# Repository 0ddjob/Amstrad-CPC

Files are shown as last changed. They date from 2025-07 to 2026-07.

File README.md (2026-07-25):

# Amstrad CPC
Amstrad CPC related projects.

## [Typer-Inner-Checker](/Typer-Inner-Checker)
A simple HTML/web page to aid typing in Locomotive BASIC program listings on a modern computer.  It doesn't run the program, that's for a proper emulator.<br>

This HTML page will:
- Check each line as you type it in
- Colourise/capitalise keywords
- Highlights missing GOTO/GOSUB targets
- Save/load BAS file for resuming where you left off

## [CPC PLUS Floppy Adaptor](/CPC_Plus_Floppy_Adaptor)
An idea to convert the 6128 PLUS model's Centronics floppy connector to a more standard 26-way or 34-way pin header to connect a drive via a ribbon cable.<br>

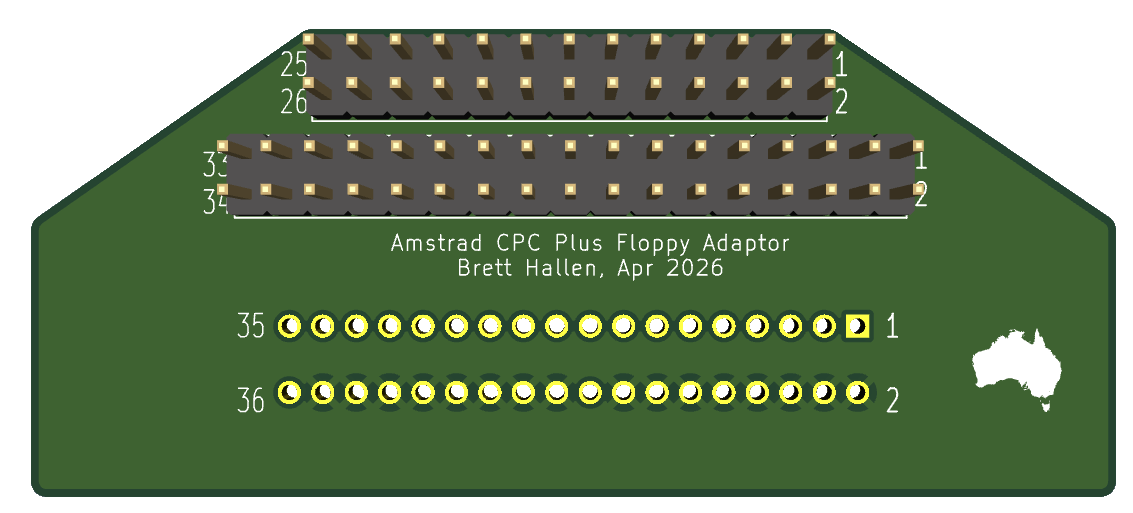
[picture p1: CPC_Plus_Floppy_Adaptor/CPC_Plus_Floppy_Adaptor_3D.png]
CPC PLUS Floppy Adaptor


### Status
21-May-2026: test boards being fabricated

## [Dual ROM Adaptor for CPC464](/CPC464_Dual_ROM)
An idea for a no-cut adaptor board to allow two 32KB ROM images to be installed/switchable on a 64KB EPROM.  This means you could have the original 464 firmware/BASIC 1.0 and 664 (or 6128) firmware/BASIC 1.1 easily switchable.  Alternatively you could install a diagnostic ROM in one of the 32KB banks.<br>

Of course you would need to de-solder the original ROM and install this, but you wouldn't need to worry about cutting the PCB and wiring up pin 1, and you can just reinstall the original ROM.<br>

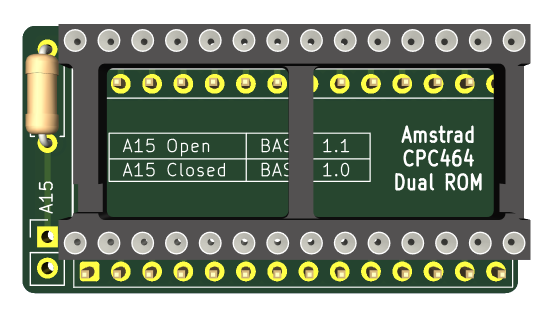
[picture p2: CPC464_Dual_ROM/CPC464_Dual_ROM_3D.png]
Dual ROM 3D


### Status
21-May-2026: test boards being fabricated

## [Amstrad CPC Troubleshooting Keyboard](/Amstrad_CPC_Keyboard)
Started off as a quick'n'dirty keyboard for my 2nd CPC664 motherboard that's missing the top case/keyboard, then morphed to a generic CPC keyboard that could be used for troubleshooting naked motherboards.<br>

### Status
25-Jul-2025: work in progress<br>

## [Easy Add on Projects for Amstrad CPC](/Easy-Add-on-Projects-for-Amstrad-CPC)
Trying out hardware projects from the book.

## [VGA4CPC](/VGA4CPC_Brett)
A modification of [grzegorz_gr's original design](https://github.com/grzegorz-gr/vga4cpc) to use with [WacKEDmaN's enhanced firmware](https://github.com/WacKEDmaN/VGA4CPC-Enhanced).<br>

- Rev. A: original re-design of grzegorz-gr's original, adding 6-pin & 8-pin DIN input sockets plus 3.5mm audio pass-through & 2.1mm DC power input
- Rev. B: added buffer on VGA output as suggest by [WacKEDmaN](https://github.com/WacKEDmaN/VGA4CPC-Enhanced#optional-hardware-mods), pass-through for B&W LUM signal, extra push button & breakout of spare GPIOs
- Rev. C: removed CPC PLUS 8-pin DIN to reduce board size (<100x100mm) for cheaper fabrication, adjusted resistor values
- Rev. D: added the CPC PLUS 8-pin DIN back in plus 3.5mm stereo audio output, remaining under 100x100mm
- Rev. E: swapped TLV3212 (SOIC-8) comparator for TLV3232 (SSOP-8) as it's faster
- Rev. F: moved the [comparator to its own daughterboard](/Amstrad-CPC/VGA4CPC_Brett/Comparator_Board) (simplifies circuit routing), switched to 5V logic (Pico 2 required), also switching the 74LVC245 (SMD) to 74HCT245 (THT)

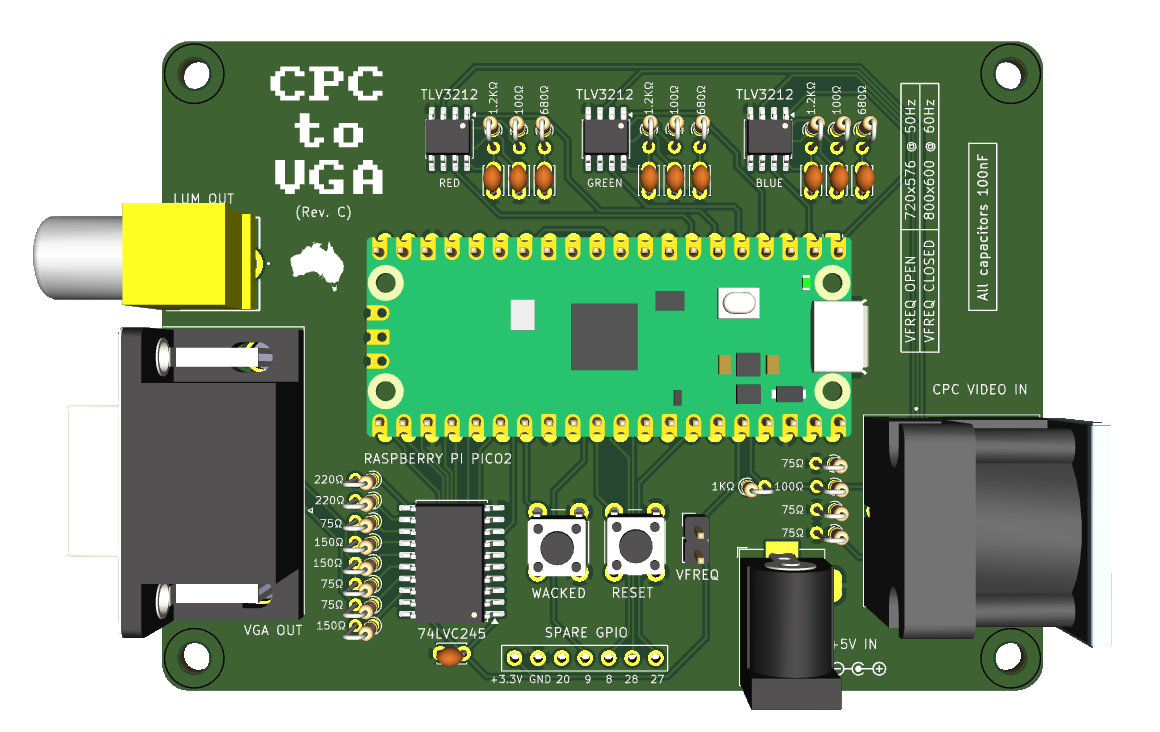
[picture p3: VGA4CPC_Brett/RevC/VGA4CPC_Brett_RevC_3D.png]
Brett's CPC-only board 3D


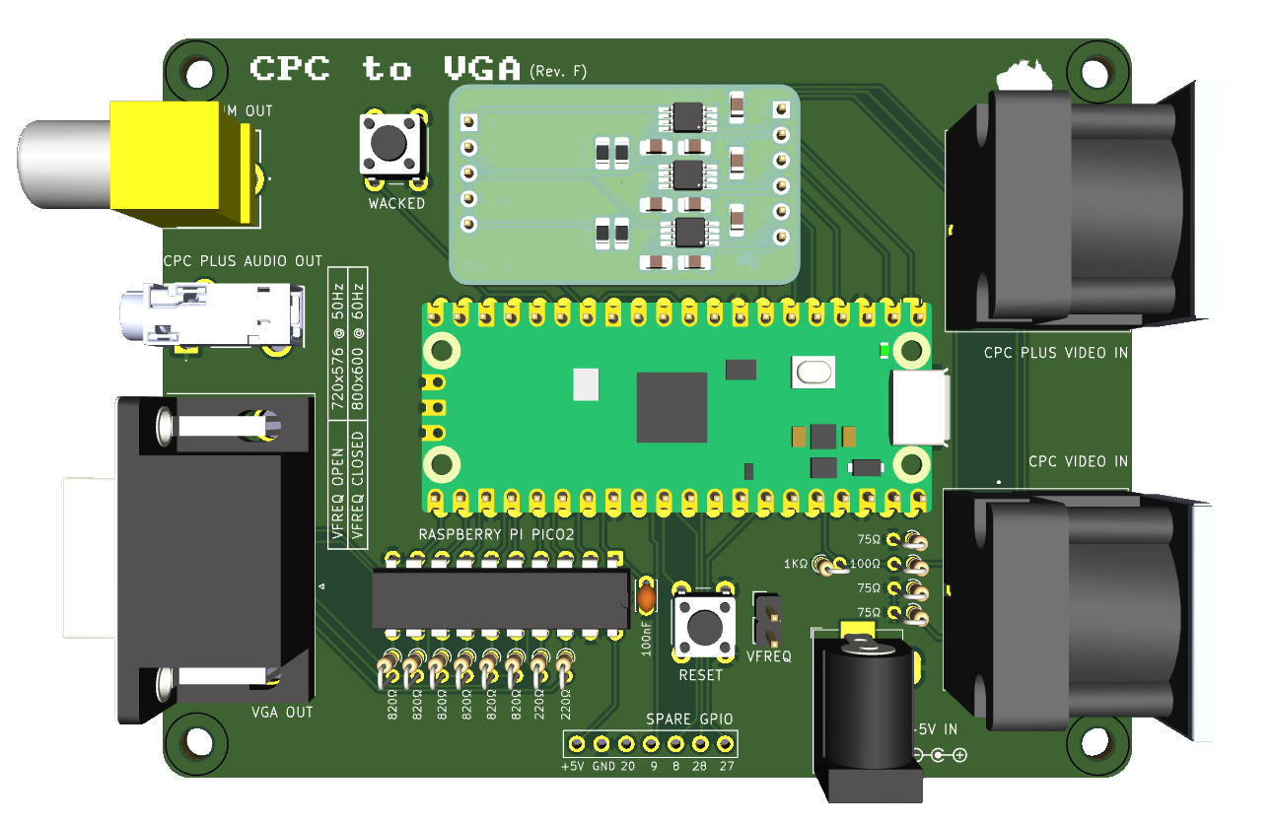
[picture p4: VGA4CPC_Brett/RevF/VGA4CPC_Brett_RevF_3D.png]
Brett's CPC-to-VGA board 3D


### Status
22-May-2025: Rev. C pending fab & testing

## [CPC DIN to VGA](/CPC_DIN-to-VGA)
This is just a very simple connector converter - convert the CPC/CPC PLUS DIN to VGA, with also an RCA for the B&W LUM signal and 3.5mm stereo socket for the PLUSs' audio output.<br>

The idea is that you can then more easily plug it into a device with a VGA socket (like GBS8200) for actual signal conversion.<br>

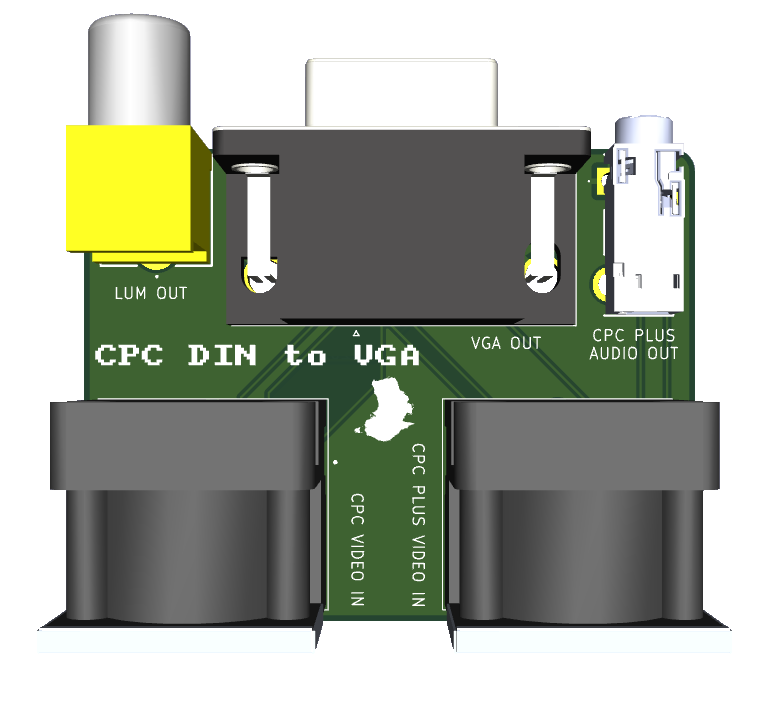
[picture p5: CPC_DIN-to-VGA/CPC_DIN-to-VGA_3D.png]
CPC DIN to VGA converter 3D


## [Laserwarp](/Laserwarp)
Laserwarp was the first game, with Map Rally, that we got with our green screen Amstrad CPC464 so I have fond memories.<br>

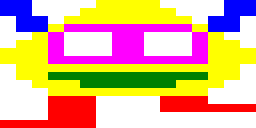
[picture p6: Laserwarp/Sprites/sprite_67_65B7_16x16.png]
Laserwarp sprite


I thought it might be interesting to try out Claude to disassemble and delve into how the game works.<br>

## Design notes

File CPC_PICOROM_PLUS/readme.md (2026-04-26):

# CPC+ ROM Emulator using Raspberry Pi Pico
Based on [Matt Callow's](https://github.com/mattcallow/CPC_PICOROM) original design for the CPC.

## Current Status: UNTESTED!
- 18-Nov-2024: initial design done
- 20-Nov-2024: test PCBs on their way from PCBWAY
- 3-Dec-2024: Initial testing ... not working!  (not really a surprise)
- 12-Dec-2024: Centronics pin numbering all wrong, duh!  External ROMs on Plus machines are all logical, upper ROMs only.

Plus Expansion Connector

## Instructions
Please refer to Matt's page for firmware & instructions on how to initialise the Pico & transfer/use Amstrad CPC ROMs.<br>
ROMs can be found [here](https://www.cpcwiki.eu/index.php/ROM_List).

## Parts
- Raspberry Pi Pico
- 50-way male Centronics connector (NorComp 111-050-113L001?)
- 2 x 6mm tactile switch (for reset)
- 5 x 1N4148 diodes

## Design
Designed using Kicad.<br>
Files, including Gerbers for production, can be found [here.](/Hardware/)<br>
Centronics connector [Kicad symbol.](/CPC_PICOROM_PLUS/Hardware/Centronics_Connector/)  I also made a custom version with signal names on the pins (see schematic image below).<br>
Raspberry Pi Pico [Kicad symbol.](https://github.com/ncarandini/KiCad-RP-Pico)<br>
Tactile switches [Kicad symbol.](https://github.com/skiselev/my_kicad_library)<br>

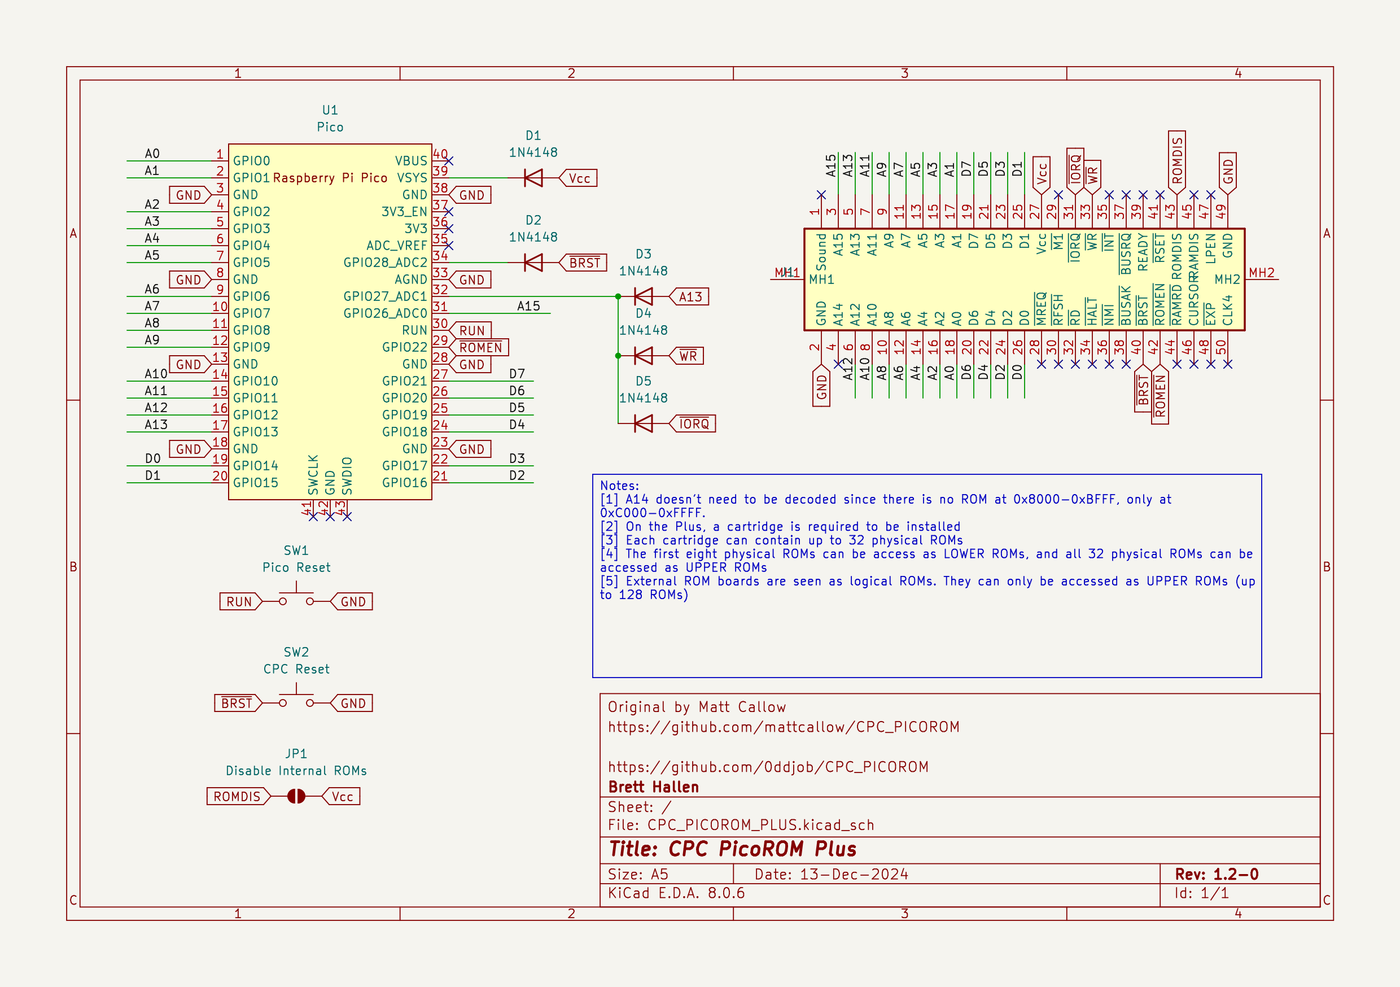
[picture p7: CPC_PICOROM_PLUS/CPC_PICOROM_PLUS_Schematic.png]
Schematic


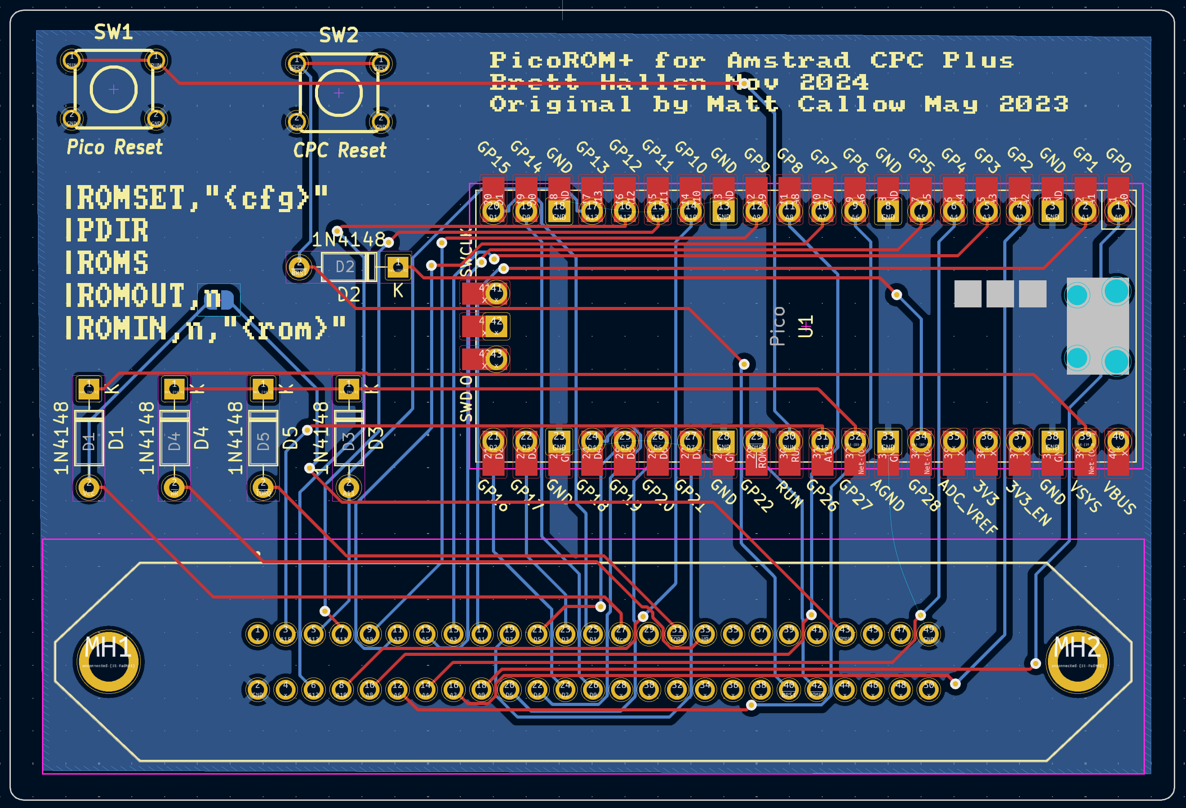
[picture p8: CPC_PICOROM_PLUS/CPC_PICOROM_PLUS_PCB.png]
PCB layout


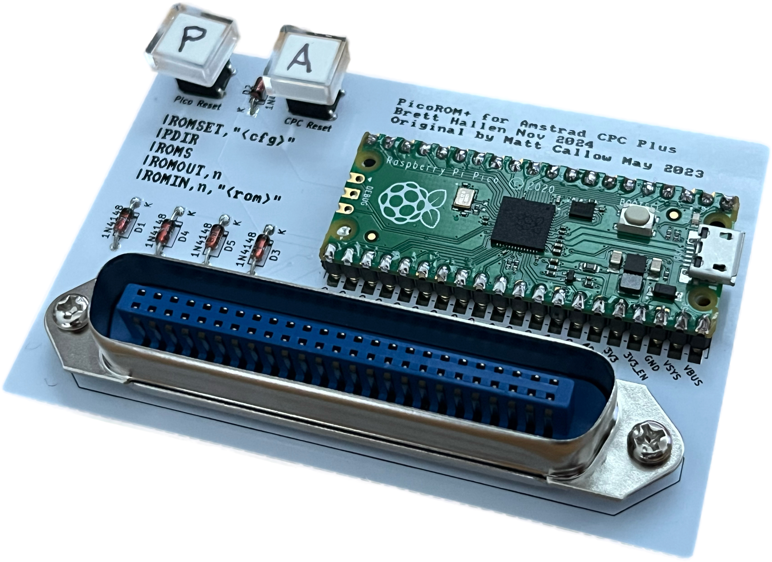
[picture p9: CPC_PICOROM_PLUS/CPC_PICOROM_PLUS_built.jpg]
Build PCB


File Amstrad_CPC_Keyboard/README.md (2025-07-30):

# Amstrad CPC Troubleshooting Keyboard
Started off as a quick'n'dirty keyboard for my 2nd CPC664 motherboard that's missing the top case/keyboard, then morphed to a generic CPC keyboard that could be used for troubleshooting naked motherboards.<br>

The CPC6128/Plus keyboard is a simple rectangle so I based this keyboard on that design, but using CPC464 colouring (that I grew up with).  The initial CPC464/664 keyboard design was abandoned/not completed in favour of the CPC6128 design.<br>

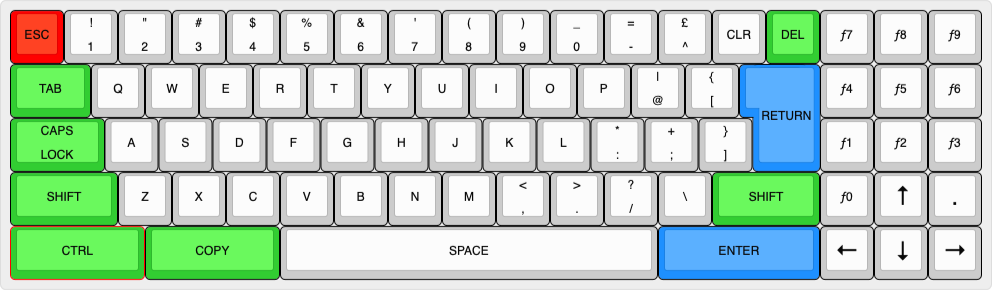
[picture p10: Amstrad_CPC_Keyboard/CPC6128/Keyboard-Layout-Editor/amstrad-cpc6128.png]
Proposed troubleshooting keyboard layout


And now I've decided to just concentrate on a simple tactile switch version, nice and compact, suitable for troubleshooting purposes.<br>

As there are different connectors used on the CPC464, CPC664 and CPC6128/Plus computers I decided to use just one connector on the keyboard itself and handle the motherboard connection by using different cable sets (to be designed).<br>

## Links (for Cherry version)
- [Keyboard layout design](https://www.keyboard-layout-editor.com)
- [Switch layout template](http://builder.swillkb.com)

## Proposed BOM (for Cherry version)
- 74 x Cherry MX-type key switches in total
- 63 x 1u
- 1 x ISO ENTER
- 1 x 1.5u (TAB)
- 1 x 1.75u (CAPS LOCK)
- 2 x 2.5u (COPY & CTRL)
- 1 x 3u (number pad ENTER)
- 1 x 7u (SPACE)
- 1 x SPST power switch
- 1 x LED & resistor
- 2 x 10-pin header (for keyboard)
- 1 x 2-pin header (for power)

## Status
25-Jul-2025: work in progress<br>

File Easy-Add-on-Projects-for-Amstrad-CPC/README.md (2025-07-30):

# Easy Add-on Projects for Amstrad CPC & MSX Computers
Hardware projects from the [book](https://archive.org/details/easy-add-on-projects-for-amstrad-cpc-464-664-6128-and-msx-computers-owen-bishopacme) by Owen Bishop.<br>

## [Project 2: Picture Digitiser](/Project02/)
Status:<br>
15-Apr-2025: Initial PCB design completed<br>

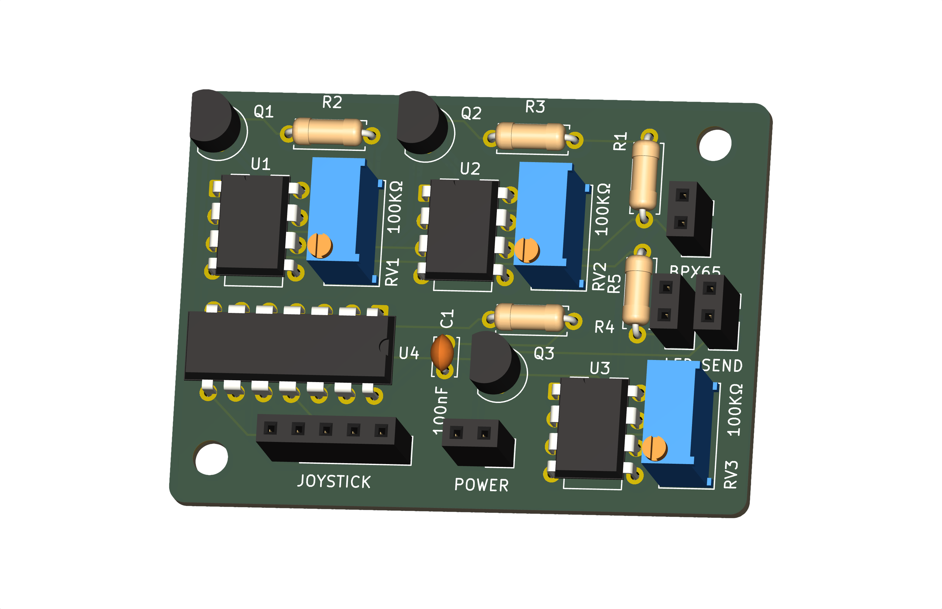
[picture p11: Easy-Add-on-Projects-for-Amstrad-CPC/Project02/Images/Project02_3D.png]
3D view of PCB


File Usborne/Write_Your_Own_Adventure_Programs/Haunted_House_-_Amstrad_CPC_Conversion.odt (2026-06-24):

Haunted House

An Amstrad CPC (Locomotive BASIC) conversion by Claude (with minor patches by Brett Hallen, June 2026)

This is a conversion of the Haunted House adventure from Usborne’s Write Your Own Adventure Programs for Your Microcomputer (the listing beginning on page 33). The book gives a generic “Microsoft BASIC” listing with conversion notes for the VIC-20, Oric, BBC, Spectrum and ZX81 — but not the Amstrad CPC. This version runs on a CPC 464, 664 or 6128 under Locomotive BASIC.

Line numbers are kept identical to the book so you can cross-reference the original. Only the lines listed below were changed; everything else is typed exactly as printed.

# Loading and running

Type the listing in directly on a real machine or an emulator (WinAPE, Caprice32, RetroVirtualMachine all work well), then:

RUN

To keep a copy:

SAVE"HAUNTED"

In an emulator you can usually paste the .bas text straight into the BASIC editor, or convert it to a .DSK disk image with a tool such as iDSK / CPCDiskXP and then LOAD it.

# Changes made for the Amstrad CPC

Line(s) | In the book | Amstrad CPC version | Reason
50 | REM SELECT "TEXT MODE" IF NECESSARY | MODE 1:INK 0,0:INK 1,24:BORDER 0:PEN 1:PAPER 0 | The CPC needs an explicit screen mode. MODE 1 gives a 40-column screen, wide enough for every message. The INK/BORDER/PAPER/PEN settings give bright text on a black background for atmosphere and are optional.
65 | CLEAR 100 | (line removed) | Marked “only needed on TRS-80.” Locomotive BASIC’s CLEAR takes no string-space argument, so this line would cause a syntax error. String space is handled automatically.
90 | CLS | CLS (unchanged) | The CPC already has CLS, so the VIC-20 substitution (PRINT CHR$(147)) is not needed.
420 | ...RND(3)<>3... | ...INT(RND*3+1)<>3... | On the CPC, RND(x) for any positive x returns a fraction 0–1, so RND(3) never equals 3. Replaced with the integer form the book itself specifies for other machines (bats attack ~2 times in 3).
430 | ...RND(2)=1... | ...INT(RND*2)=1... | Same RND issue. INT(RND*2) gives 0 or 1, a true 50/50 chance for the ghosts to appear.
1190 | ...RM=RND(63) | ...RM=INT(RND*64) | Same RND issue. INT(RND*64) teleports you to a random room 0–63, as intended.
235 | (new line) | Q$=UPPER$(Q$) | Added so input is folded to upper case before parsing. The verb and object names are stored in capitals, so without this the player would have to use CAPS LOCK. UPPER$ is built into Locomotive BASIC on all CPC models.

One small display tidy-up (not CPC-specific): line 150 originally printed a comma after every exit, leaving a trailing one — “EXITS: N,W,E,”. It now prints the comma only between exits, so the list reads “EXITS: N,W,E”.

# Things that did NOT need changing

These are worth knowing, because the book’s notes for other machines can be misleading on the CPC:

Arrays start at zero. The listing fills R$(0)…R$(63) and D$(0)…D$(63) and depends on element zero existing. Locomotive BASIC arrays are 0-based by default, exactly like the Microsoft BASIC the listing targets, so the Spectrum’s “add 1 to every room index” rewrite is NOT needed here.

LET is optional. The Spectrum requires LET on every assignment; the CPC does not, so assignments are left bare as printed (e.g. V=25).

INPUT prompts. INPUT "...";Q$ works as-is. The book notes a BBC may need a comma instead of the semicolon — the CPC is happy with the semicolon.

Ampersands in DATA. Room names such as “KITCHEN & GRIMY COOKER” and “STUDY WITH DESK & HOLE IN WALL” are left unquoted. When READ into a string variable, Locomotive BASIC takes the characters literally, so they don’t need quoting.

The long ON VB GOSUB at line 460 has 26 targets for 25 verbs — this is intentional, not a typo. An unrecognised verb sets VB to 26, which jumps to the bare RETURN at line 1590 and harmlessly does nothing.

# Playing notes

Type your commands in either case — line 235 folds the input to upper case automatically (UPPER$), so CAPS LOCK is not required. Most commands are two words, e.g. GET ROPE, OPEN DRAWER, LIGHT CANDLE, SAY XZANFAR. HELP lists the words it knows; CARRYING? lists your inventory; SCORE checks progress.

You start at the front gate (room 57) with a candle whose life (LL) is 60 turns; once lit it burns down and warns you before going out. Only N/S/W/E are processed directly — up and down work at the staircases, where lines 720–770 remap them.

# Saving and quitting (pages 30–31)

Pages 30–31 of the book describe optional SAVE, LOAD and QUIT commands. These have been added and adapted to the CPC’s file handling. Each is a single-word command — just type SAVE, LOAD or QUIT. (QUIT first asks whether you want to save, then ends the program.)

Three wiring changes connect the new commands, exactly as the book instructs:

• Line 70: V raised from 25 to 28 (three new verbs).

• Line 1665: SAVE, LOAD and QUIT appended to the verb list, becoming verbs 26, 27 and 28.

• Line 460: the subroutine numbers 3000, 4000 and 5000 spliced in just before the final 1590, so SAVE jumps to 3000, LOAD to 4000 and QUIT to 5000.

The new routines themselves (3000–3200 SAVE, 4000–4200 LOAD, 5000–5050 QUIT) needed the book’s generic file commands swapped for real Locomotive BASIC ones:

Line(s) | In the book | Amstrad CPC version | Reason
3020 / 4020 | OPEN FILE FOR OUTPUT / INPUT (placeholder) | OPENOUT"HOUSE" / OPENIN"HOUSE" | The book leaves these as plain-English placeholders to fill in per machine. On the CPC, OPENOUT opens a file to save to, OPENIN opens one to read back.
3030–3080 / 4030–4080 | PRINT #1,... / INPUT #1,... | PRINT #9,... / INPUT #9,... | Locomotive BASIC uses stream #9 for the open cassette/disc file, not #1.
3080 / 4080 | PRINT #1,C(I),F(I) | PRINT #9,C(I):PRINT #9,F(I) | Two values per line confuse INPUT# on the CPC. Writing (and reading) each on its own line makes the save reliable. The book’s footnote flags this same separator problem for the BBC.
3100 / 4100 | CLOSE | CLOSEOUT / CLOSEIN | The CPC closes the output and input files with separate keywords.
5020 | INPUT "...",Q$ | INPUT "...";Q$ | Comma changed to semicolon for the CPC’s INPUT prompt syntax.

Two things worth knowing. On a 464 the game saves to cassette and on a 664/6128 to disc; OPENOUT and OPENIN prompt you to ready the tape automatically, so the “READY TO SAVE/LOAD” questions are just polite extras. And, as the book itself warns, the save records only your room, the object positions, what you are carrying and the game flags — it does NOT save the D$ and R$ arrays. So any room you have permanently changed (opening the secret room, digging out the bars, unlocking the front door) reverts to its original description and exits when you reload. To preserve those too you would add matching loops for D$ and R$ to both routines.

# Full listing

Filename: Haunted House (Amstrad CPC).bas

10 REM HAUNTED HOUSE ADVENTURE

20 REM

30 REM AMSTRAD CPC (LOCOMOTIVE BASIC) VERSION

40 REM ADAPTED FROM USBORNE "WRITE YOUR OWN

45 REM ADVENTURE PROGRAMS", PAGE 33

50 MODE 1:INK 0,0:INK 1,24:BORDER 0:PEN 1:PAPER 0

60 REM

70 V=28:W=36:G=18

80 GOSUB 1600

90 CLS:PRINT"HAUNTED HOUSE"

100 PRINT"------------"

110 PRINT"YOUR LOCATION"

120 PRINT D$(RM)

130 PRINT"EXITS:"

140 FOR I=1 TO LEN(R$(RM))

150 PRINT MID$(R$(RM),I,1);:IF I<LEN(R$(RM)) THEN PRINT",";

160 NEXT I

170 PRINT

180 FOR I=1 TO G

190 IF L(I)=RM AND F(I)=0 THEN PRINT"YOU CAN SEE ";O$(I);" HERE"

200 NEXT I

210 PRINT"=============="

220 PRINT M$:M$="WHAT"

230 INPUT"WHAT WILL YOU DO NOW";Q$

235 Q$=UPPER$(Q$)

240 V$="":W$="":VB=0:OB=0

250 FOR I=1 TO LEN(Q$)

260 IF MID$(Q$,I,1)=" " AND V$="" THEN V$=LEFT$(Q$,I-1)

270 IF MID$(Q$,I,1)=" " AND V$<>"" THEN W$=MID$(Q$,I+1,LEN(Q$)-1):I=LEN(Q$)

280 NEXT I

290 IF W$="" THEN V$=Q$

300 FOR I=1 TO V

310 IF V$=V$(I) THEN VB=I

320 NEXT I

330 FOR I=1 TO W

340 IF W$=O$(I) THEN OB=I

350 NEXT I

360 IF W$<>"" AND OB=0 THEN M$="THAT'S SILLY"

370 IF VB=0 THEN VB=V+1

380 IF W$="" THEN M$="I NEED TWO WORDS"

390 IF VB>V AND OB>0 THEN M$="YOU CAN'T '"+Q$+"'"

400 IF VB>V AND OB=0 THEN M$="YOU DON'T MAKE SENSE"

410 IF VB<V AND OB>0 AND C(OB)=0 THEN M$="YOU DON'T HAVE '"+W$

420 IF F(26)=1 AND RM=13 AND INT(RND*3+1)<>3 AND VB<>21 THEN M$="BATS ATTACKING!":GOTO 90

430 IF RM=44 AND INT(RND*2)=1 AND F(24)<>1 THEN F(27)=1

440 IF F(0)=1 THEN LL=LL-1

450 IF LL<1 THEN F(0)=0

460 ON VB GOSUB 500,570,640,640,640,640,640,640,640,980,980,1030,1070,1140,1180,1220,1250,1300,1340,1380,1400,1430,1460,1490,1510,3000,4000,5000,1590

470 IF LL=10 THEN M$="YOUR CANDLE IS WANING!"

480 IF LL=1 THEN M$="YOUR CANDLE IS OUT!"

490 GOTO 90

500 PRINT"WORDS I KNOW:"

510 FOR I=1 TO V

520 PRINT V$(I);",";

530 NEXT I

540 M$="":PRINT

550 GOSUB 1580

560 RETURN

570 PRINT"YOU ARE CARRYING:"

580 FOR I=1 TO G

590 IF C(I)=1 THEN PRINT O$(I);",";

600 NEXT I

610 M$="":PRINT

620 GOSUB 1580

630 RETURN

640 D=0

650 IF OB=0 THEN D=VB-3

660 IF OB=19 THEN D=1

670 IF OB=20 THEN D=2

680 IF OB=21 THEN D=3

690 IF OB=22 THEN D=4

700 IF OB=23 THEN D=5

710 IF OB=24 THEN D=6

720 IF RM=20 AND D=5 THEN D=1

730 IF RM=20 AND D=6 THEN D=3

740 IF RM=22 AND D=6 THEN D=2

750 IF RM=22 AND D=5 THEN D=3

760 IF RM=36 AND D=6 THEN D=2

770 IF RM=36 AND D=5 THEN D=2

780 IF F(14)=1 THEN M$="CRASH! YOU FELL OUT OF THE TREE!":F(14)=0:RETURN

790 IF F(27)=1 AND RM=52 THEN M$="GHOSTS WILL NOT LET YOU MOVE":RETURN

800 IF RM=45 AND C(1)=1 AND F(34)=0 THEN M$="A MAGICAL BARRIER TO THE WEST":RETURN

810 IF (RM=26 AND F(0)=0) AND (D=1 OR D=4) THEN M$="YOU NEED A LIGHT":RETURN

820 IF RM=54 AND C(15)<>1 THEN M$="YOU'RE STUCK!":RETURN

830 IF C(15)=1 AND NOT (RM=53 OR RM=54 OR RM=55 OR RM=47) THEN M$="YOU CAN'T CARRY A BOAT!":RETURN

840 IF (RM>26 AND RM<30) AND F(0)=0 THEN M$="TOO DARK TO MOVE":RETURN

850 F(35)=0:RL=LEN(R$(RM))

860 FOR I=1 TO RL

870 U$=MID$(R$(RM),I,1)

880 IF (U$="N" AND D=1 AND F(35)=0) THEN RM=RM-8:F(35)=1

890 IF (U$="S" AND D=2 AND F(35)=0) THEN RM=RM+8:F(35)=1

900 IF (U$="W" AND D=3 AND F(35)=0) THEN RM=RM-1:F(35)=1

910 IF (U$="E" AND D=4 AND F(35)=0) THEN RM=RM+1:F(35)=1

920 NEXT I

930 M$="OK"

940 IF F(35)=0 THEN M$="CAN'T GO THAT WAY!"

950 IF D<1 THEN M$="GO WHERE?"

960 IF RM=41 AND F(23)=1 THEN R$(49)="SW":M$="THE DOOR SLAMS SHUT!":F(23)=0

970 RETURN

980 IF OB>G THEN M$="I CAN'T GET "+W$:RETURN

985 IF L(OB)<>RM THEN M$="IT ISN'T HERE"

990 IF F(OB)<>0 THEN M$="WHAT "+W$+"?"

1000 IF C(OB)=1 THEN M$="YOU ALREADY HAVE IT"

1010 IF OB>0 AND L(OB)=RM AND F(OB)=0 THEN C(OB)=1:L(OB)=65:M$="YOU HAVE THE "+W$

1020 RETURN

1030 IF RM=43 AND (OB=28 OR OB=29) THEN F(17)=0:M$="DRAWER OPEN"

1040 IF RM=28 AND OB=25 THEN M$="IT'S LOCKED"

1050 IF RM=38 AND OB=32 THEN M$="THAT'S CREEPY!":F(2)=0

1060 RETURN

1070 IF OB=30 THEN F(18)=0:M$="SOMETHING HERE!"

1080 IF OB=31 THEN M$="THAT'S DISGUSTING!"

1090 IF (OB=28 OR OB=29) THEN M$="THERE IS A DRAWER"

1100 IF OB=33 OR OB=5 THEN GOSUB 1140

1110 IF RM=43 AND OB=35 THEN M$="THERE IS SOMETHING BEYOND.."

1120 IF OB=32 THEN GOSUB 1030

1130 RETURN

1140 IF RM=42 AND OB=33 THEN M$="THEY ARE DEMONIC WORKS"

1150 IF (OB=3 OR OB=36) AND C(3)=1 AND F(34)=0 THEN M$="USE THIS WORD WITH CARE 'XZANFAR'"

1160 IF C(5)=1 AND OB=5 THEN M$="THE SCRIPT IS IN AN ALIEN TONGUE"

1170 RETURN

1180 M$="OK '"+W$+"'"

1190 IF C(3)=1 AND OB=34 THEN M$="*MAGIC OCCURS*":IF RM<>45 THEN RM=INT(RND*64)

1200 IF C(3)=1 AND OB=34 AND RM=45 THEN F(34)=1

1210 RETURN

1220 IF C(12)=1 THEN M$="YOU MADE A HOLE"

1230 IF C(12)=1 AND RM=30 THEN M$="DUG THE BARS OUT":D$(RM)="HOLE IN WALL":R$(RM)="NSE"

1240 RETURN

1250 IF C(14)<>1 AND RM=7 THEN M$="THIS IS NO TIME TO PLAY GAMES"

1260 IF OB=14 AND C(14)=1 THEN M$="YOU SWUNG IT"

1270 IF OB=13 AND C(13)=1 THEN M$="WHOOSH!"

1280 IF OB=13 AND C(13)=1 AND RM=43 THEN R$(RM)="WN":D$(RM)="STUDY WITH SECRET ROOM":M$="YOU BROKE THE THIN WALL"

1290 RETURN

1300 IF OB=14 AND C(14)=1 THEN M$="IT ISN'T ATTACHED TO ANYTHING!"

1310 IF OB=14 AND C(14)<>1 AND RM=7 AND F(14)=0 THEN M$="YOU SEE THICK FOREST AND CLIFF SOUTH":F(14)=1:RETURN

1320 IF OB=14 AND C(14)<>1 AND RM=7 AND F(14)=1 THEN M$="GOING DOWN!":F(14)=0

1330 RETURN

1340 IF OB=17 AND C(17)=1 AND C(8)=0 THEN M$="IT WILL BURN YOUR HANDS"

1350 IF OB=17 AND C(17)=1 AND C(9)=0 THEN M$="NOTHING TO LIGHT IT WITH"

1360 IF OB=17 AND C(17)=1 AND C(9)=1 AND C(8)=1 THEN M$="IT CASTS A FLICKERING LIGHT":F(0)=1

1370 RETURN

1380 IF F(0)=1 THEN F(0)=0:M$="EXTINGUISHED"

1390 RETURN

1400 IF OB=26 AND C(16)=1 THEN M$="HISSSS"

1410 IF OB=26 AND C(16)=1 AND F(26)=1 THEN F(26)=0:M$="PFFT! GOT THEM"

1420 RETURN

1430 IF OB=10 AND C(10)=1 AND C(11)=1 THEN M$="SWITCHED ON":F(24)=1

1440 IF F(27)=1 AND F(24)=1 THEN M$="WHIZZ- VACUUMED THE GHOSTS UP!":F(27)=0

1450 RETURN

1460 IF RM=43 AND (OB=27 OR OB=28) THEN GOSUB 1030

1470 IF RM=28 AND OB=25 AND F(25)=0 AND C(18)=1 THEN F(25)=1:R$(RM)="SEW":D$(RM)="HUGE OPEN DOOR":M$="THE KEY TURNS!"

1480 RETURN

1490 IF C(OB)=1 THEN C(OB)=0:L(OB)=RM:M$="DONE"

1500 RETURN

1510 S=0

1520 FOR I=1 TO G

1530 IF C(I)=1 THEN S=S+1

1540 NEXT I

1550 IF S=17 AND C(15)<>1 AND RM<>57 THEN PRINT"YOU HAVE EVERYTHING":PRINT"RETURN TO THE GATE FOR FINAL SCORE"

1560 IF S=17 AND RM=57 THEN PRINT"DOUBLE SCORE FOR REACHING HERE!":S=S*2

1570 PRINT"YOUR SCORE=";S:IF S>18 THEN PRINT"WELL DONE! YOU FINISHED THE GAME":END

1580 INPUT"PRESS RETURN TO CONTINUE";Q$

1590 RETURN

1600 DIM R$(63),D$(63),O$(W),V$(V)

1610 DIM C(W),L(G),F(W)

1620 DATA 46,38,35,50,13,18,28,42,10,25,26,4,2,7,47,60,43,32

1630 FOR I=1 TO G

1640 READ L(I)

1650 NEXT I

1660 DATA HELP,CARRYING?,GO,N,S,W,E,U,D,GET,TAKE,OPEN,EXAMINE,READ,SAY

1665 DATA DIG,SWING,CLIMB,LIGHT,UNLIGHT,SPRAY,USE,UNLOCK,LEAVE,SCORE,SAVE,LOAD,QUIT

1680 FOR I=1 TO V

1690 READ V$(I)

1700 NEXT I

1710 DATA SE,WE,WE,SWE,WE,WE,SWE,WS

1720 DATA NS,SE,WE,NW,SE,W,NE,NSW

1730 DATA NS,NS,SE,WE,NWUD,SE,WSUD,NS

1740 DATA N,NS,NSE,WE,WE,NSW,NS,NS

1750 DATA S,NSE,NSW,S,NSUD,N,N,NS

1760 DATA NE,NW,NE,W,NSE,WE,W,NS

1770 DATA SE,NSW,E,WE,NS,S,SW,NW

1780 DATA NWE,NWE,WE,WE,WE,NWE,NWE,W

1790 FOR I=0 TO 63

1800 READ R$(I)

1810 NEXT I

1820 DATA DARK CORNER,OVERGROWN GARDEN,BY LARGE WOODPILE,YARD BY RUBBISH

1825 DATA WEEDPATCH,FOREST,THICK FOREST,BLASTED TREE

1840 DATA CORNER OF HOUSE,ENTRANCE TO KITCHEN,KITCHEN & GRIMY COOKER,SCULLERY DOOR

1845 DATA ROOM WITH INCHES OF DUST,REAR TURRET ROOM,CLEARING BY HOUSE,PATH

1860 DATA SIDE OF HOUSE,BACK OF HALLWAY,DARK ALCOVE,SMALL DARK ROOM

1865 DATA BOTTOM OF SPIRAL STAIRCASE,WIDE PASSAGE,SLIPPERY STEPS,CLIFFTOP

1880 DATA NEAR CRUMBLING WALL,GLOOMY PASSAGE,POOL OF LIGHT,IMPRESSIVE VAULTED HALLWAY

1885 DATA HALL BY THICK WOODEN DOOR,TROPHY ROOM,CELLAR WITH BARRED WINDOW,CLIFF PATH

1900 DATA CUPBOARD WITH HANGING COAT,FRONT HALL,SITTING ROOM,SECRET ROOM

1905 DATA STEEP MARBLE STAIRS,DINING ROOM,DEEP CELLAR WITH COFFIN,CLIFF PATH

1920 DATA CLOSET,FRONT LOBBY,LIBRARY OF EVIL BOOKS,STUDY WITH DESK & HOLE IN WALL

1925 DATA WEIRD COBWEBBY ROOM,VERY COLD CHAMBER,SPOOKY ROOM,CLIFF PATH BY MARSH

1940 DATA RUBBLE-STREWN VERANDAH,FRONT PORCH,FRONT TOWER,SLOPING CORRIDOR

1945 DATA UPPER GALLERY,MARSH BY WALL,MARSH,SOGGY PATH

1960 DATA BY TWISTED RAILING,PATH THROUGH IRON GATE,BY RAILINGS,BENEATH FRONT TOWER

1965 DATA DEBRIS FROM CRUMBLING FACADE,LARGE FALLEN BRICKWORK,ROTTING STONE ARCH,CRUMBLING CLIFFTOP

1980 FOR I=0 TO 63

1990 READ D$(I)

2000 NEXT I

2010 DATA PAINTING,RING,MAGIC SPELLS,GOBLET,SCROLL,COINS,STATUE,CANDLESTICK

2012 DATA MATCHES,VACUUM,BATTERIES,SHOVEL,AXE,ROPE,BOAT,AEROSOL,CANDLE,KEY

2014 DATA NORTH,SOUTH,WEST,EAST,UP,DOWN

2016 DATA DOOR,BATS,GHOSTS,DRAWER,DESK,COAT,RUBBISH

2018 DATA COFFIN,BOOKS,XZANFAR,WALL,SPELLS

2060 FOR I=1 TO W

2070 READ O$(I)

2080 NEXT I

2090 F(18)=1:F(17)=1:F(2)=1:F(26)=1:F(28)=1:F(23)=1:LL=60:RM=57:M$="OK"

2100 RETURN

3000 INPUT"READY TO SAVE";Y$

3010 IF Y$<>"Y" THEN 3000

3020 OPENOUT"HOUSE"

3030 PRINT #9,RM

3040 FOR I=1 TO G

3050 PRINT #9,L(I)

3060 NEXT I

3070 FOR I=1 TO W

3080 PRINT #9,C(I):PRINT #9,F(I)

3090 NEXT I

3100 CLOSEOUT

3200 RETURN

4000 INPUT"READY TO LOAD";Y$

4010 IF Y$<>"Y" THEN 4000

4020 OPENIN"HOUSE"

4030 INPUT #9,RM

4040 FOR I=1 TO G

4050 INPUT #9,L(I)

4060 NEXT I

4070 FOR I=1 TO W

4080 INPUT #9,C(I):INPUT #9,F(I)

4090 NEXT I

4100 CLOSEIN

4200 RETURN

5000 INPUT"WANT TO QUIT";Q$

5010 IF Q$<>"Y" THEN RETURN

5020 INPUT"LIKE TO SAVE GAME FIRST";Q$

5030 IF Q$="Y" THEN GOSUB 3000

5040 PRINT"THANKS FOR PLAYING"

5050 END

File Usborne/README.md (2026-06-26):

# Usborne Programs
We got our Amstrad CPC464 with green screen in 1985 and the first book I got was Usborne's "Write Your Own Adventure Programs".<br>

It included a listing of an example adventure game, HAUNTED HOUSE, in Microsoft BASIC with custom conversions for various popular machines ... except for the Amstrad CPC and its Locomotive BASIC ... as the book came out a year before the 464's release.<br>

I never really got the program working (I was very young and stupid) so I finally decided to rectify that by using Claude to generate a CPC version in a DSK file, and then made some minor tweaks of my own (like using UPPER$ function to accept either upper or lower case commands).<br>

Usborne have very graciously made high-quality PDFs available for free download [here](https://usborne.com/au/books/computer-and-coding-books).

## [Write Your Own Adventure Programs](/Usborne/Write_Your_Own_Adventure_Programs)
My first attempt - it seems to work quite well (thanks Claude).<br>

There's two versions:
- HOUSE1.BAS: this is the straight conversion of the original listing
- HOUSE2.BAS: this is my tweaked version that's a little more playable

The tweaks include:
- using UPPER$ function so you don't need to SHOUT commands :)
- removed the extra comma on the EXITS output (i.e. N,S,W instead of N,S,W,)
- added in the save/load/quit subroutines

## [Write Your Own Fantasy Games](/Usborne/Write_Your_Own_Fantasy_Games)
The original game had three separate listings: the dungeon designer, the character creator and then the main game itself.<br>

Still a work in progress - they seem to be working but I will tweak more.<br>

- DUNGEON1.BAS: the straight conversion of the dungeon designer
- DUNGEON2.BAS: my tweaked/improved version
- CREATOR1.BAS: the straight conversion of the character creator
- GAME1.BAS: the straight conversion of the main game

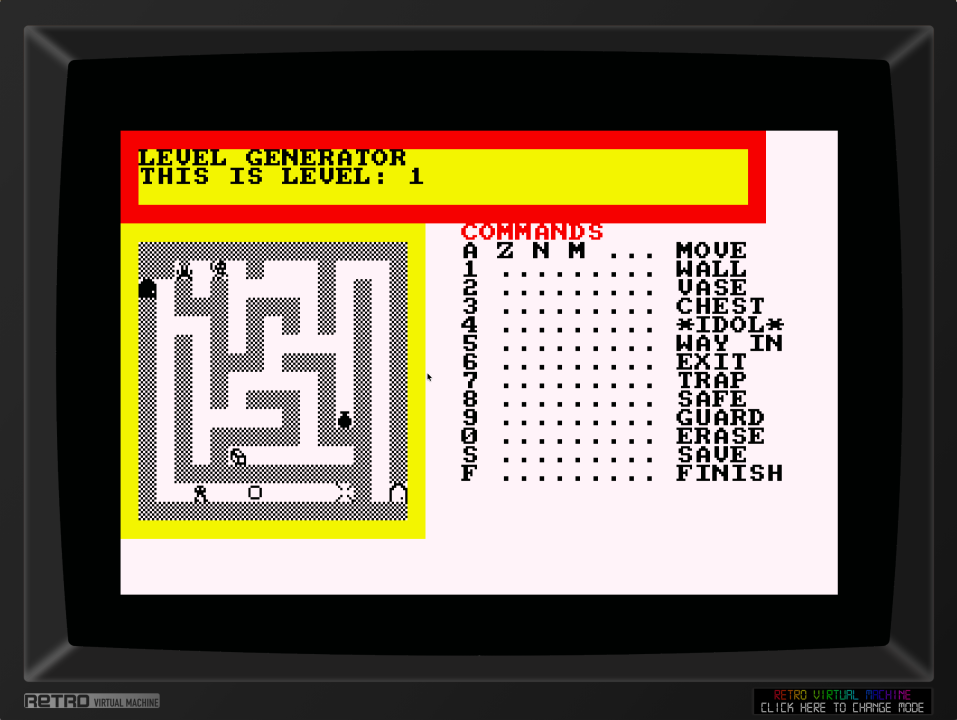
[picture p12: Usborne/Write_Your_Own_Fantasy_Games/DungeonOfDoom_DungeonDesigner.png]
Dungeon of Doom level designer


## [Island of Secrets](/Usborne/Island_Of_Secrets)
Claude got a little cagey when asked to create an Amstrad CPC version - it was worried about copyright.  But it did offer to create a conversion guide which I could use as I type in 450 lines of the program like it was 1985 ...

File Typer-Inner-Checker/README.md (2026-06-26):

# Typer Inner Checker for Locomotive BASIC

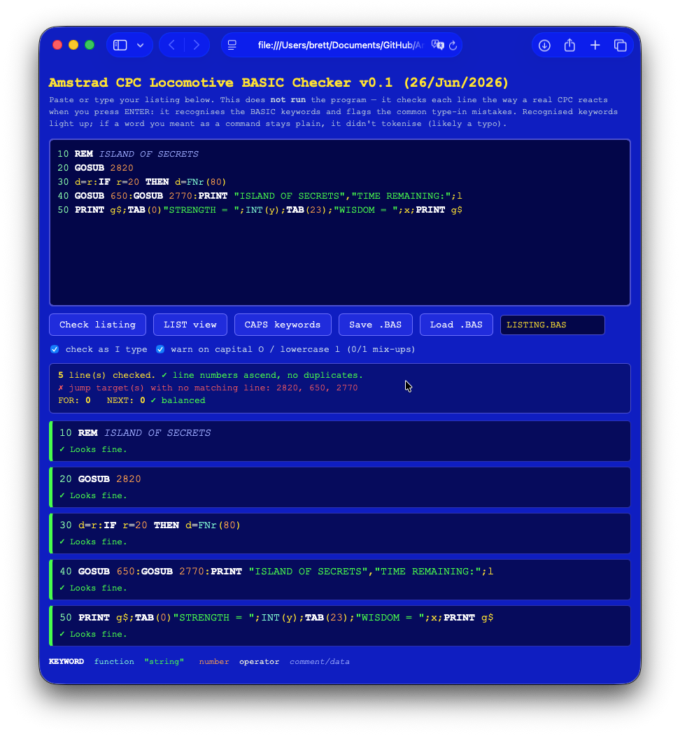
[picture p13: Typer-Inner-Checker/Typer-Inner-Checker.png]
Example


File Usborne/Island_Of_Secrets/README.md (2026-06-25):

# Island of Secrets — Amstrad CPC Conversion Guide

A reference for porting the type-in listing to **Amstrad Locomotive BASIC** (CPC 464/664/6128).
You type the program in from your own copy of the book; apply these rules as you go. The book's
left-margin symbols mark the lines that differ per machine — those are the lines this guide is about.

There is no Amstrad column in the book, so the CPC equivalents below are worked out from how the
generic/Spectrum versions behave.

---

## 1. Global rules (apply everywhere)

| Book construct | CPC (Locomotive BASIC) | Notes |
|---|---|---|
| `LET A=...` | `A=...` (drop `LET`) | Optional on the CPC. Keep `LET` if you'd rather match the book exactly — it's valid either way. |
| `DEF FNR(Z)=INT(RND(1)*Z)+1` | `DEF FNR(Z)=INT(RND*Z)+1` | CPC `RND` already returns 0–<1. (`RND(1)` also works.) Random integer 1…Z. |
| `DEF FNP(Z)=POS` | `DEF FNP(Z)=POS(#0)` | CPC `POS` needs a stream argument. Returns the cursor **column** (1–40). |
| `DEF FNS(Z)=Y-(E/C4+.1)` | unchanged | Uses Y/E/C4 globals; fine as-is. |
| machine-specific clear-screen | `CLS` | Wherever the book's clear routine is called. |
| `PRINT TAB(c)` used for layout | `LOCATE c,r` (or keep `TAB`) | See §2. |

**`O`/`0` and `I`/`1`:** the book warns about these — they bite hardest in the data lines. When in
doubt, capital-letter variables (`L`, `O`, `R`, `Y`) vs digits.

---

## 2. Screen, colour, cursor

- **Mode:** it's a 40-column text adventure → `MODE 1`.
- **Colour:** pick your palette once at start, e.g. a parchment look:
  `MODE 1:INK 0,0:INK 1,26:INK 2,6:INK 3,24:BORDER 0:PAPER 0:PEN 1`
  (black paper, white text; inks 2/3 spare for highlights). Adjust to taste.
- **Status line** (STRENGTH / WISDOM / TIME at the top): the book positions fields with `TAB`/home
  tricks tuned to each machine's width. On the CPC, place each field explicitly:
  `LOCATE 1,1:PRINT"STRENGTH = ";INT(Y);` … `LOCATE 24,1:PRINT"WISDOM = ";X` etc.
  The `G$` "row of dashes" separator string is just text — keep it.
- **Don't rely on TAB(0) wrapping** to start a new line (some machines do this; the CPC's behaviour
  differs). Use `LOCATE` for anything that must land in an exact spot.

---

## 3. Keyboard

- Command line: `INPUT E$` — fine as-is.
- Any single-key tests: wrap with `UPPER$(INKEY$)` so they work without CAPS LOCK.

---

## 4. The one structural change: computed `RESTORE`

The describe-location routine builds a DATA line number and jumps to it:
`D = D*10 + LR : RESTORE D : READ A$` (with `LR` ≈ 2860, so it targets the room-description DATA
block at that line). **Locomotive BASIC's `RESTORE` only accepts a *literal* line number** — `RESTORE D`
is a `Syntax error` on the CPC. This is the only change that needs real restructuring.

**Fix — pre-load the room/action DATA into an array once, then index it.**

At init (after the DIMs), read every room-description DATA block into a string array. If those blocks
run from the first room line `Lfirst` in steps of 10 for `N` rooms:

```
DIM RM$(N)
RESTORE Lfirst              ' literal line number — allowed
FOR I=1 TO N:READ RM$(I):NEXT I
```

Then replace the describe routine's `RESTORE D:READ A$` with a direct index. Because `D=D*10+LR`:

```
A$=RM$((D-LR)/10)
```

For any **other** computed `RESTORE` that uses a *constant* offset (e.g. the one near 4110,
`RESTORE LR+1230`), you don't need an array — just compute the constant yourself and write the
**literal**: `RESTORE 4090` (i.e. 2860+1230). Only the *variable* `RESTORE D` needs the array.

> Tip: keep a scrap of paper mapping `D` values → room line numbers as you type the DATA, so you can
> confirm `(D-LR)/10` lands on the right block.

---

## 5. Word-wrap printer

The book prints a description one character at a time and breaks at a space once the cursor passes a
margin: `IF E$=" " AND FNP(Z)>Z THEN PRINT`. On the CPC:

- `FNP(Z)` → `POS(#0)` (see §1).
- `Z` is your **wrap column**. For MODE 1, set `Z=36` at init (breaks a few columns before the edge).
  `Z` is also passed as the dummy argument to `FNP`/`FNS`, but those ignore it — only line ~730 uses
  `Z` as the threshold, so one value (36) serves both jobs.
- The rest of the print loop is unchanged.

(The CPC also auto-wraps text windows, but the manual break-on-space gives cleaner word breaks — keep it.)

---

## 6. Save / load game (the `"ISDATA"` feature)

The book uses `SAVE "ISDATA" DATA L()` / `LOAD "ISDATA" DATA L()` (and `F()`). The CPC has **no
array save/load** verb, so stream the elements yourself. With `L()` and `F()` dimensioned to 52:

**Save:**
```
OPENOUT"ISDATA"
FOR I=0 TO 52:PRINT #9,L(I):NEXT I
FOR I=0 TO 52:PRINT #9,F(I):NEXT I
CLOSEOUT
```

**Load:**
```
OPENIN"ISDATA"
FOR I=0 TO 52:INPUT #9,L(I):NEXT I
FOR I=0 TO 52:INPUT #9,F(I):NEXT I
CLOSEIN
```

Match the loop bounds to the book's actual `DIM L(...)`/`DIM F(...)`. Numbers round-trip cleanly
through `PRINT #`/`INPUT #`.

---

## 7. The encoded data strings (type, don't convert)

The packed "code" strings (decoded with `ASC(MID$(...))-offset`) and the binary-flag strings are
**machine-independent data** — no CPC change needed. But they must be typed *character-perfect*,
including every `~ % \ ; / *` etc., or the decode produces garbage. Type them slowly and use the
book's own checks: flag strings come in groups of four `0`/`1`s; watch `O` vs `0`. These are the lines
most worth re-reading aloud against the book.

---

## 8. Quick conversion table

| Book | CPC |
|---|---|
| `INT(RND(1)*Z)+1` | `INT(RND*Z)+1` |
| `POS` | `POS(#0)` |
| `RESTORE <variable>` | pre-load DATA → array, index it (§4) |
| `RESTORE <const expr>` | `RESTORE <literal line>` |
| `SAVE/LOAD "x" DATA a()` | `OPENOUT`/`OPENIN` + `PRINT#`/`INPUT#` loop (§6) |
| machine clear-screen | `CLS` |
| `TAB(c)` for absolute layout | `LOCATE c,r` |
| `PEEK(screen)` / `POS` wrap test | `POS(#0)` |
| `LET` | (drop, or keep — your choice) |

---

## 9. Order of work that worked well for the other games

1. Type the **init / DIM / DEF FN** and the **DATA** first (including the encoded strings) and check
   them hard — most "won't run" bugs live here.
2. Add the **main loop + parser**, then the **subroutines** a block at a time, `RUN`-testing after each.
3. Save often. Build a `.dsk` when it's stable — I can do that, verify it round-trips, and add a
   README launcher, exactly like the other titles.

When you hit a line you can't get to behave on the CPC, paste me that line (or the routine around it)
and I'll work out the Locomotive BASIC equivalent with you.

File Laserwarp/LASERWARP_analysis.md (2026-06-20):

# Laserwarp (Amstrad CPC) — Disassembly Notes

**Game:** Laserwarp / *Attaque au Laser* — Amsoft / Mikro-Gen, 1985. Vertically-scrolling
fixed shoot-'em-up; original code by Chris Hinsley.

**This revision is built from the cassette image `Laserwarp (E).cdt`,** which is a far better
source than the earlier `LASERWRP.BIN` and is what these notes now describe. The `.cdt` gives
the **complete, CRC-verified, uncracked** game; the old `.BIN` was only a partial cracked rip.

Deliverables: `LASERWARP.asm` (full annotated listing of the `&4000–&88FF` image),
`laserwarp_full.bin` (the reconstructed binary), `basic_loader.bin` (the BASIC loader), and
these notes. Tooling (`z80disasm.py`, `firmware.py`, `cdt` parser in `generate_full.py`) is
included for reproducibility.

---

## 1. Why the tape is the better source

| | Old `LASERWRP.BIN` | Tape `Laserwarp (E).cdt` |
|---|---|---|
| Coverage | ~13 KB, `&4000–&73xx` only | **Full 18,688 bytes, `&4000–&88FF`** |
| Main loop at `&75FE` | **missing** (jumped outside the file) | **present and disassembled** |
| Integrity | cracked/modified; garbled message text; `CHANY from NPS` / `Doctor Fegg` tags | **clean original; all 95 tape chunks pass CRC** |
| Loader | none | **BASIC loader included** |

The two share only the first 159 bytes (`&4000–&409E`: entry stub + sound init + envelopes);
from `&409F` on they differ almost completely, so the old file was a genuinely different,
modified build — not just a subset.

## 2. Tape structure

The CDT is a TZX 1.0 container. Data is carried in "turbo" (0x11) blocks, each CPC record
being a sync byte (`0x2C` header / `0x16` data) followed by 256-byte chunks each protected by a
16-bit CRC (CRC-16/CCITT, stored complemented). **All 95 chunks verified**, so the
reconstruction is exact. The tape holds two files:

**File 1 — BASIC loader** (type `&01`, loads at `&0170`, 2,510 bytes). It paints the title
screen — its strings include `"AND"`, `"PRESENT"`, `"L A S E R W A R P"`, `"!"` — then loads
and runs the machine-code file.

**File 2 — machine code** (type `&02`), 10 blocks loading contiguously:

```
block 1  &4000  2048      block 6  &6800  2048
block 2  &4800  2048      block 7  &7000  2048
block 3  &5000  2048      block 8  &7800  2048
block 4  &5800  2048      block 9  &8000  2048
block 5  &6000  2048      block 10 &8800   256
```

→ one image `&4000–&88FF`, total length `&4900` (18,688 bytes), matching the header's logical
length field exactly.

## 3. Run-time memory map

| Range | Size | Contents |
|---|---|---|
| `&4000–&4007` | 8 | Entry stub: `call snd_init` ; `jp main` |
| `&4008–&4064` | 93 | Sound + ink initialisation |
| `&4065–&414F` | ~235 | Sound envelopes (6 amplitude + 4 tone), sound-effect blocks, ink-setup string, `SCORE=`/`SECTION=` panel strings |
| `&4150–&6865` | ~10 KB | **Sprite & character graphics** (player, enemies, explosions) |
| `&6866–&7BC8` | ~5 KB | **Game routines** — drawing, movement, collision, scoring, and the main loop at `&75FE` |
| `&7BC9–&8881` | ~3.3 KB | **"THE MASTER" message text**, enemy names, "sheet complete" lines, UI prompts |
| `&8882–&88FF` | ~126 | Small trailing tables |

Recursive-descent from the real entry point reaches ~3.75 KB of code (20% of the image); the
remaining ~80% is graphics, text and tables — a normal ratio for a sprite-heavy 1985 CPC game.

## 4. Control flow that is now resolved

```
entry  &4000  call snd_init        ; install envelopes, program inks
              jp   main (&75FE)
main   &75FE  ld   hl,&4118        ; status-panel string
              call print_string    ; (&405B - the TXT OUTPUT loop from init)
              ld   a,&03           ; 3 lives
              ld   (&7816),a
              ld   (&726F),a
              call sub_7270        ; set up a new game / sheet
              ...
              jp   L_781A          ; enter the per-frame game loop
```

`print_string` (`&405B`) is the small routine `ld a,(hl) : cp &FF : ret z : call TXT OUTPUT :
inc hl : jr` that the init code and main loop both reuse to print `&FF`-terminated strings.
The main loop maintains lives/score/sheet state in a `&72xx–&78xx` variable block and drives
the enemy waves.

## 5. Sound initialisation (`&4008`) — unchanged and confirmed

Installs ten envelopes via the firmware (`call &BCBC` = SOUND AMPL ENVELOPE,
`call &BCBF` = SOUND TONE ENVELOPE), then prints the ink-setup string at `&40D2` (a run of
control-code `&1C` "set ink" triples) to program the 16-pen palette. Decoded envelopes:

```
Amplitude (step-count, step-size, pause):
  1 (15,255,3)  2 (15,255,5)  3 (8,1,6)  4 (7,254,40)
  5 (10,0,1)(10,255,6)(5,255,7)  6 (15,255,60)
Tone:
  1 (0,60,1)(120,3,1)  2 (0,50,1)(100,1,1)  3 (0,20,1)(100,0,1)  4 (100,1,5)
```

## 6. Firmware usage

Standard CPC 464 jumpblock: `KM INITIALISE/RESET`, `KM TEST KEY`, `KM GET JOYSTICK`,
`TXT INITIALISE`, `TXT OUTPUT`, `TXT CLEAR WINDOW`, `SCR SET MODE`, `SCR SET INK`,
`SCR SET BORDER`, `SOUND QUEUE`, `SOUND AMPL ENVELOPE`, `SOUND TONE ENVELOPE`. All referenced
entries are listed as `equ` defs at the top of the listing.

## 7. The script (now complete and clean)

The player is "Earth's greatest defender" facing **THE MASTER** across numbered "sheets". You
start with **3 lives + 1 per 10,000 points**. The enemy waves are:

> WHIRLING DERVISHES · SPACE MINES · RAMSHIPS · INTERSTELLAR POGOS · GALACTIC SPIDERS ·
> COSMIC SPINNERS · ARMOURED DROID · HYPERSPACE CHICKENS

with "Sheet *n* complete" lines and taunts between waves. The tape's text is intact, unlike the
cracked `.BIN` where these strings were corrupted. UI strings: `SCORE=`, `SECTION=`,
`PLEASE ENTER NAME`, `LEVEL (1-9)`, `PRACTICE SHEET`, and the French `VIES INFINIES (O/N) ?`.

## 8. Verification

1. **Tape CRCs** — all 95 data chunks pass CRC-16/CCITT, so the `&4000–&88FF` image is an exact
   bit-for-bit reconstruction of the original tape.
2. **Decoder self-test** — `z80disasm.py` passes 50/50 hand-checked opcode cases across every
   prefix family (CB, ED, DD/FD, DDCB), addressing modes, jumps/calls, block ops and I/O.
3. **Byte-exact round-trip** — re-concatenating every emitted instruction and every `defb`
   block reproduces the 18,688-byte image exactly.

## 9. Taking it further

- Code coverage is the flow-reachable spine (~20%); some routines are reached only through
  data-driven jump tables / `jp (hl)` dispatch that static descent doesn't follow. Seeding the
  disassembler with those table targets (or tracing in an emulator's monitor) would lift it.
- The graphics block `&4150–&6865` is raw sprite/character bitmaps; a CPC sprite viewer (mode-1
  4-colour, 2 pixels/byte) would render them.
- To rebuild a working tape/disk: re-assemble the code, `incbin` the data regions at their
  load addresses, and reproduce the BASIC loader (or just `LOAD` the binary at `&4000` and
  `CALL &4000`).
```

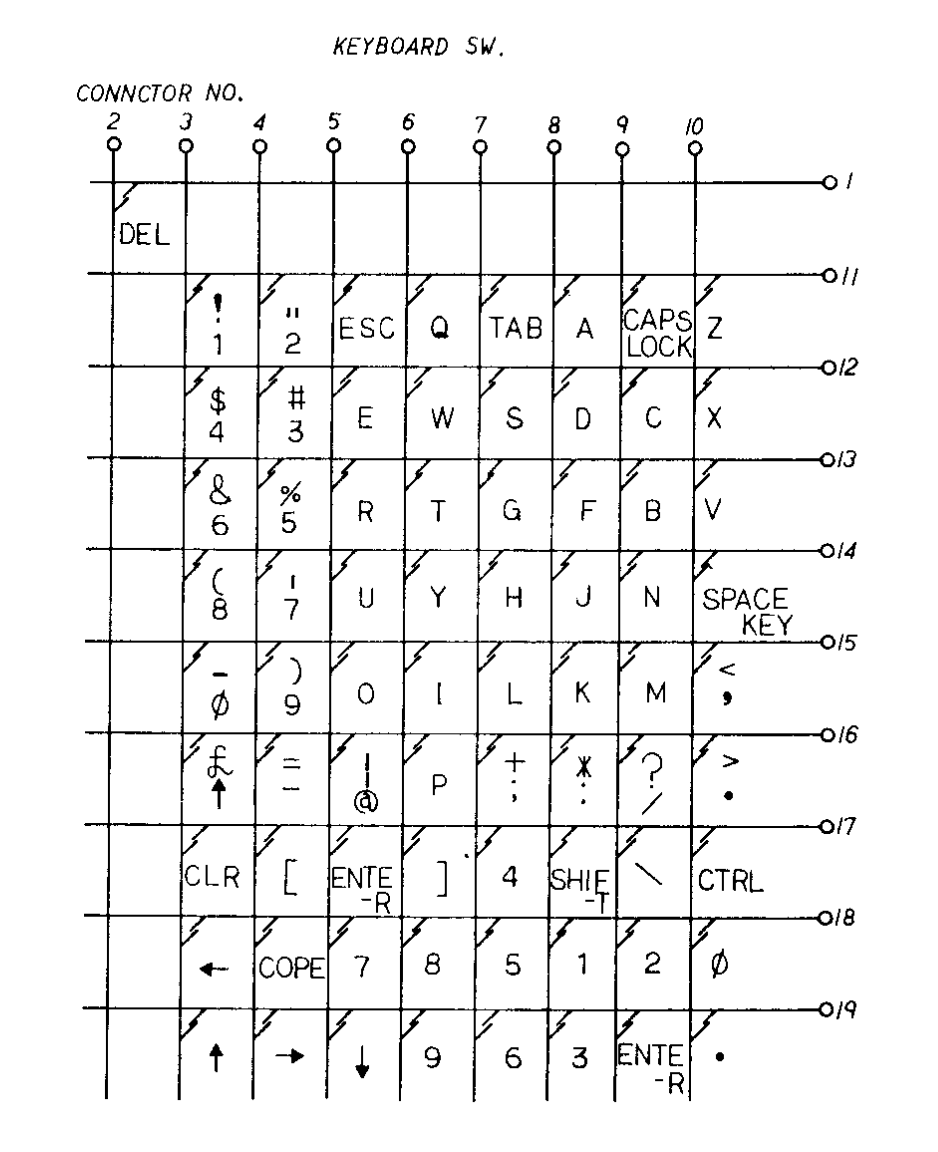
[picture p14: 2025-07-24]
Amstrad_CPC_Keyboard/Schematics/Amstrad_CPC6128_Keyboard_Matrix.png

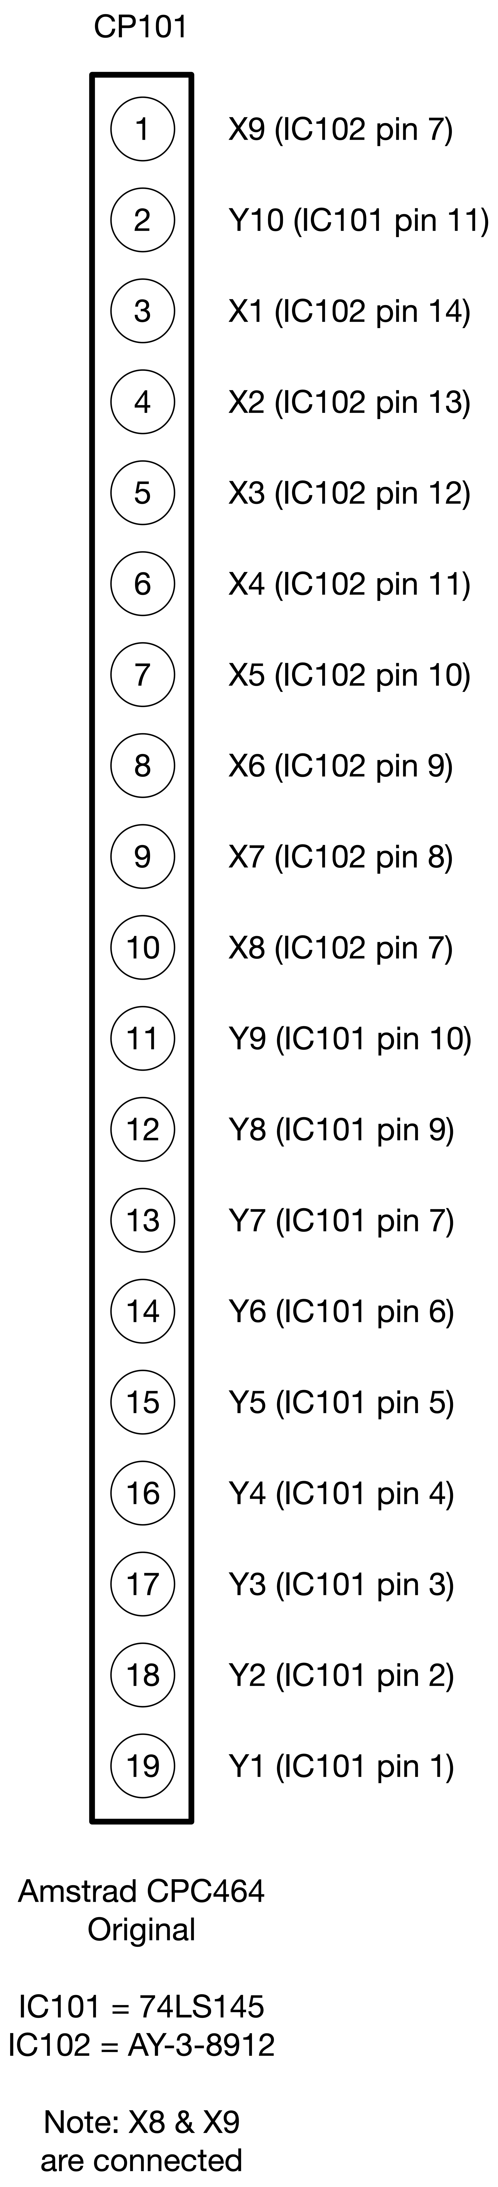
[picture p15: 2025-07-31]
Amstrad_CPC_Keyboard/Schematics/Amstrad_CPC464_Keyboard_Connectors_Original.png

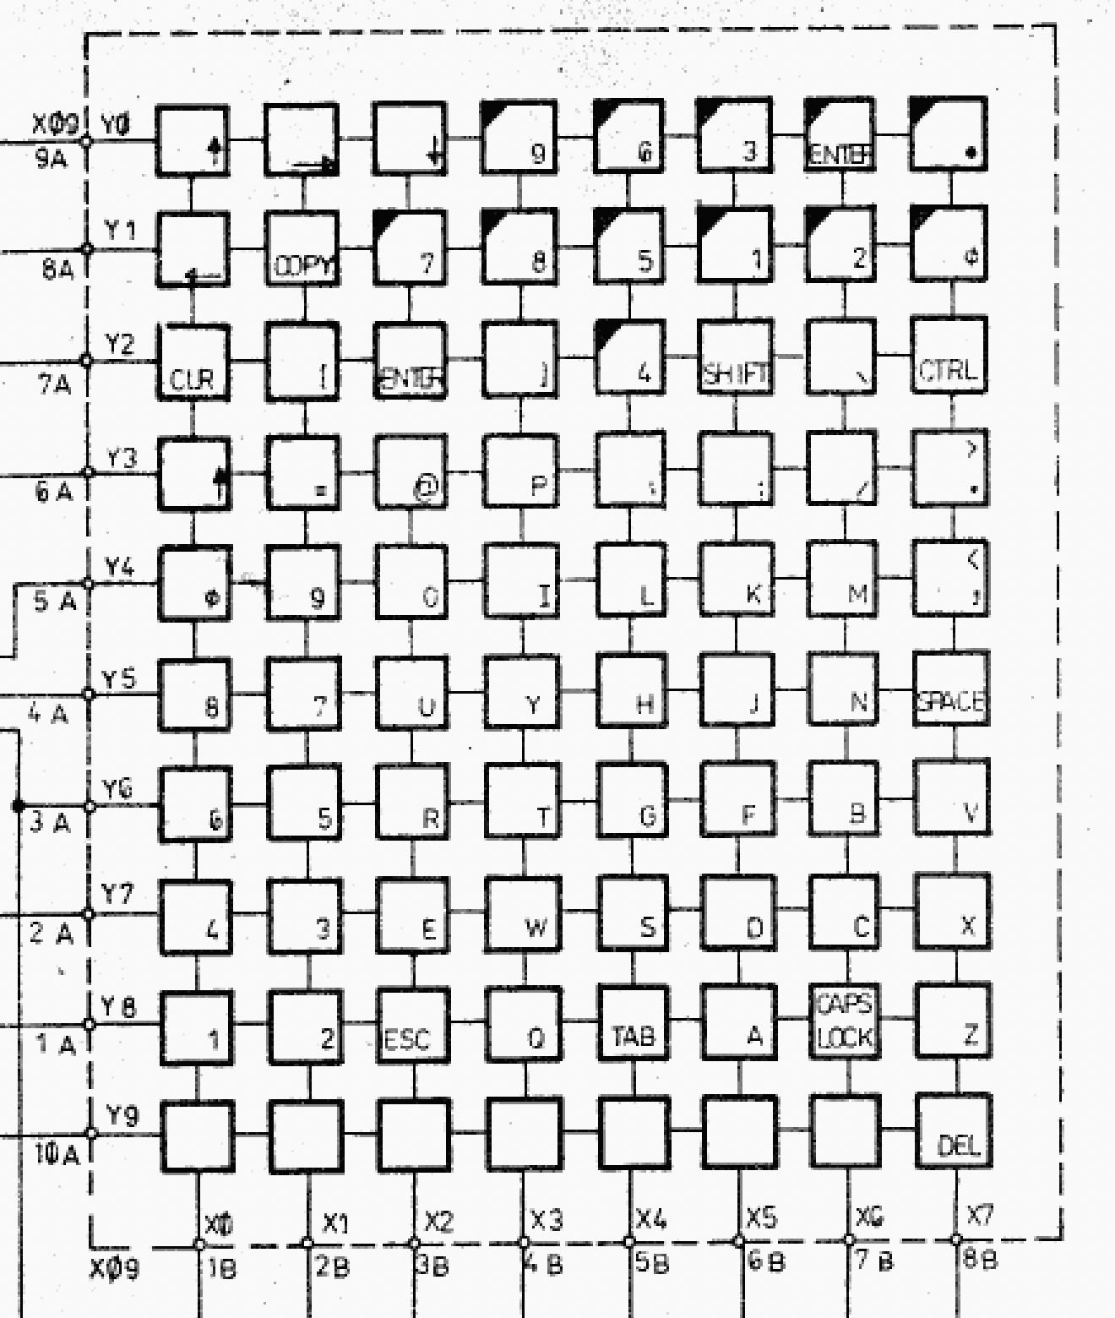
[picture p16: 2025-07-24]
Amstrad_CPC_Keyboard/Schematics/KC_Compact_Keyboard_Matrix.png

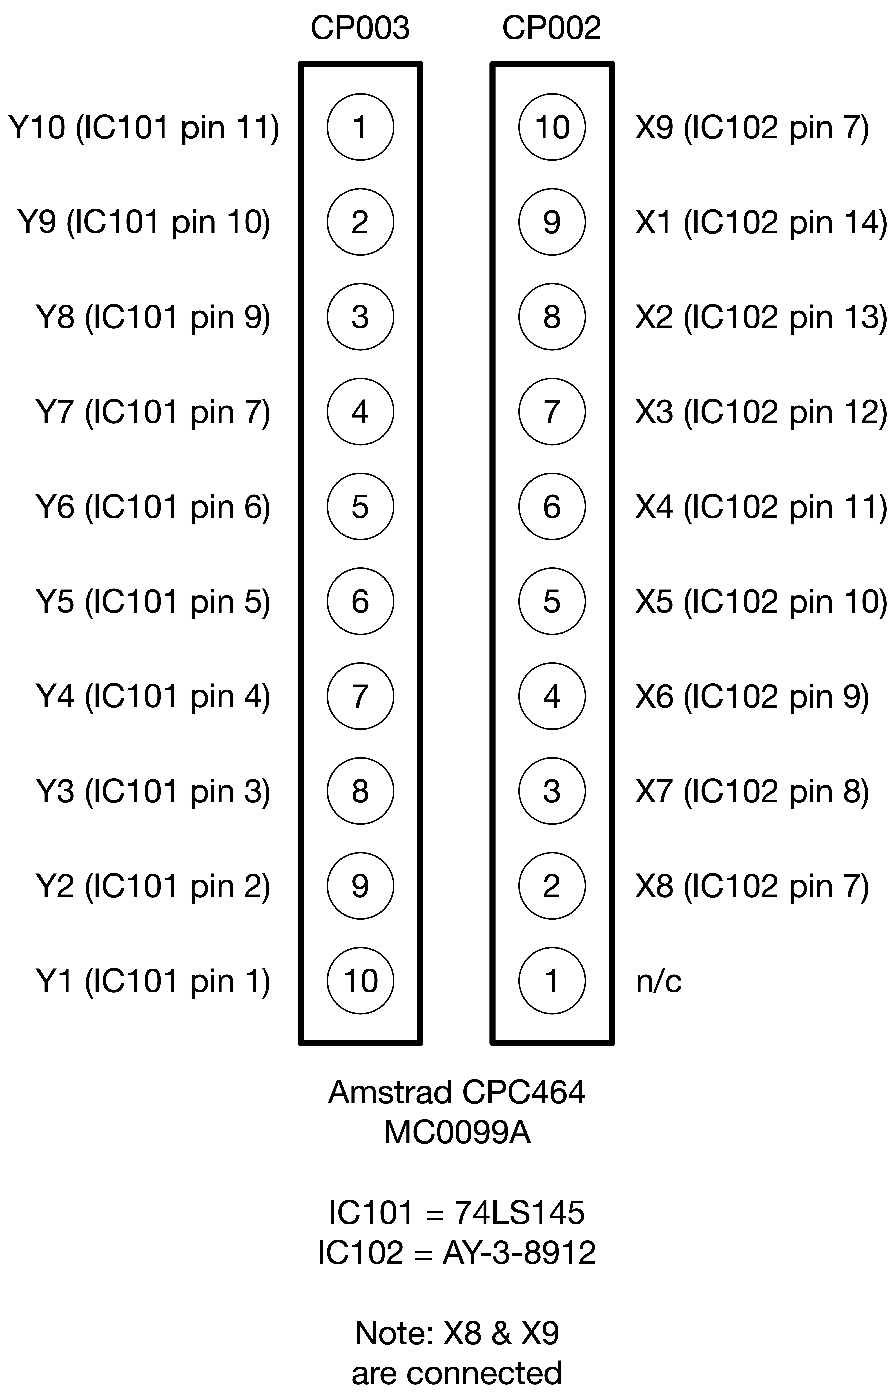
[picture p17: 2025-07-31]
Amstrad_CPC_Keyboard/Schematics/Amstrad_CPC464_Keyboard_Connectors_MC0099A.png

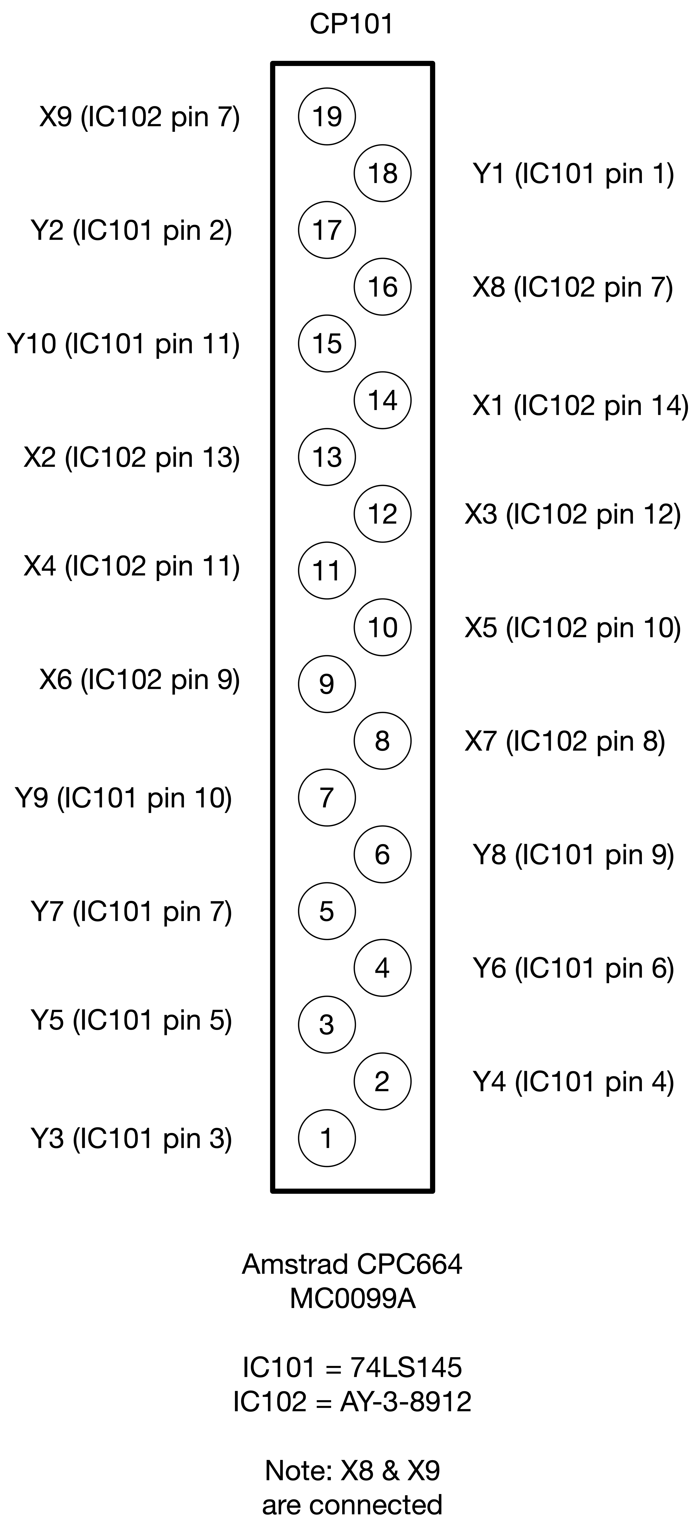
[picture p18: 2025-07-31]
Amstrad_CPC_Keyboard/Schematics/Amstrad_CPC664_Keyboard_Connectors_MC00058.png

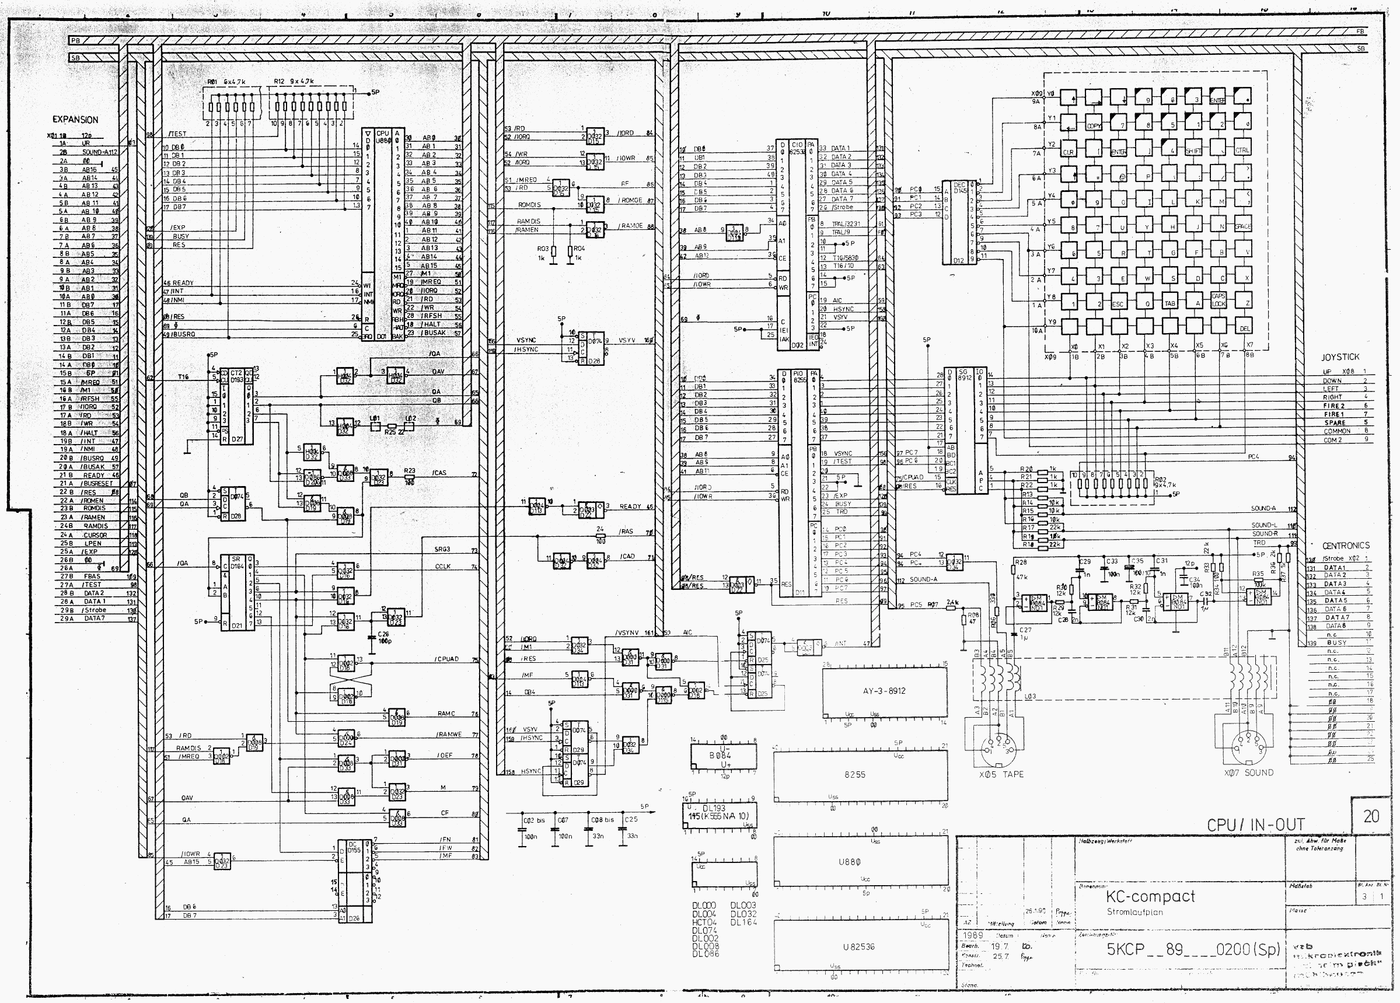
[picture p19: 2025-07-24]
Amstrad_CPC_Keyboard/Schematics/Kcc_schematic_cpu_io.gif

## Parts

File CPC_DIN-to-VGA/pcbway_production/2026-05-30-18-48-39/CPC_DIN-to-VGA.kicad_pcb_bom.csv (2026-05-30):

Designator | Quantity | Value | Footprint | Package | MPN | DNP | Mount_Type | Description
J1 | 1 | DIN-6 | SDF80J |  |  |  | tht | 6-pin DIN connector
J2 | 1 | CPC PLUS VIDEO IN | SDF80J |  |  |  | tht | 8-pin DIN connector
J3 | 1 | CPC PLUS AUDIO OUT | SJ335083ATR |  |  |  | tht | Audio Jack, 3 Poles (Stereo / TRS)
J4 | 1 | 15KHz VGA OUT | DSUB-15-HD_Socket_Horizontal_P2.29x2.54mm_EdgePinOffset8.35mm_Housed_MountingHolesOffset10.89mm |  |  |  | tht | 15-pin D-SUB connector, socket (female), High density (3 columns), Triple Row, Generic, VGA-connector, Mounting Hole
J5 | 1 | LUM OUT | 1560099E |  |  |  | tht | coaxial connector (BNC, SMA, SMB, SMC, Cinch/RCA, LEMO, ...)

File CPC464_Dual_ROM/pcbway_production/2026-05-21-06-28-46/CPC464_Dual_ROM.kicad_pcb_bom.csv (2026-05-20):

Designator | Quantity | Value | Footprint | Package | MPN | DNP | Mount_Type | Description
J1 | 1 | Conn_01x02 | PinHeader_1x02_P2.54mm_Vertical |  |  |  | tht | Generic connector, single row, 01x02, script generated (kicad-library-utils/schlib/autogen/connector/)
R1 | 1 | 10KΩ | R_Axial_DIN0207_L6.3mm_D2.5mm_P7.62mm_Horizontal |  |  |  | tht | Resistor
U1 | 1 | 27256 Socket | DIP-28_W15.24mm |  |  |  | tht | UV Erasable EPROM 256 KiBit, [Obsolete 2000-11]
U2 | 1 | 27512 ROM | DIP-28_W15.24mm_Socket |  |  |  | tht | UV Erasable EPROM 512 KiBit, [Obsolete 2007-01]

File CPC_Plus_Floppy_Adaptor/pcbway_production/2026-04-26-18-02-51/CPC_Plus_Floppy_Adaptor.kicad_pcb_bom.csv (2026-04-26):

Designator | Quantity | Value | Footprint | Package | MPN | DNP | Mount_Type | Description | Height | Mouser Part Number | Mouser Price/Stock | Manufacturer_Name
J1 | 1 | 111-036-113L001 | 111-036-113L001 |  | 111-036-113L001 |  | tht | I/O Connectors 36P Centronics male vertical dip solder | 13.05 | 636-111-036-113L001 | https://www.mouser.co.uk/ProductDetail/NorComp/111-036-113L001?qs=IGgAdOvCTsSmLhhYAltKCw%3D%3D | NorComp
J2 | 1 | Standard Floppy | PinHeader_2x17_P2.54mm_Vertical |  |  |  | tht | Generic connector, double row, 02x17, odd/even pin numbering scheme (row 1 odd numbers, row 2 even numbers), script generated (kicad-library-utils/schlib/autogen/connector/)
J3 | 1 | CPC Floppy | PinHeader_2x13_P2.54mm_Vertical |  |  |  | tht | Generic connector, double row, 02x13, odd/even pin numbering scheme (row 1 odd numbers, row 2 even numbers), script generated (kicad-library-utils/schlib/autogen/connector/)

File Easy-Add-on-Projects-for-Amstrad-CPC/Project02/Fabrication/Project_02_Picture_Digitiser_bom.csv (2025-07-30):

Designator | Quantity | Value | Footprint | Package | MPN | DNP | Mount_Type | Description | Sim.Device | Sim.Type | Sim.Pins
C1 | 1 | 100nF | C_Disc_D3.4mm_W2.1mm_P2.50mm |  |  |  | tht | Unpolarized capacitor
J1 | 1 | BPX65 | PinSocket_1x02_P2.54mm_Vertical |  |  |  | tht | Generic connector, single row, 01x02, script generated (kicad-library-utils/schlib/autogen/connector/)
J2 | 1 | JOYSTICK | PinSocket_1x05_P2.54mm_Vertical |  |  |  | tht | Generic connector, single row, 01x05, script generated (kicad-library-utils/schlib/autogen/connector/)
J3 | 1 | POWER | PinSocket_1x02_P2.54mm_Vertical |  |  |  | tht | Generic connector, single row, 01x02, script generated (kicad-library-utils/schlib/autogen/connector/)
J4 | 1 | LED | PinSocket_1x02_P2.54mm_Vertical |  |  |  | tht | Generic connector, single row, 01x02, script generated (kicad-library-utils/schlib/autogen/connector/)
J5 | 1 | SEND | PinSocket_1x02_P2.54mm_Vertical |  |  |  | tht | Generic connector, single row, 01x02, script generated (kicad-library-utils/schlib/autogen/connector/)
Q1, Q2, Q3 | 3 | ZTX300 | TO-92_Inline |  |  |  | tht | Bipolar transistor symbol for simulation only, substrate tied to the emitter | NPN | GUMMELPOON | 1=C 2=B 3=E
R1 | 1 | 100KΩ | R_Axial_DIN0207_L6.3mm_D2.5mm_P7.62mm_Horizontal |  |  |  | tht | Resistor
R2, R3, R4 | 3 | 1KΩ | R_Axial_DIN0207_L6.3mm_D2.5mm_P7.62mm_Horizontal |  |  |  | tht | Resistor
R5 | 1 | 180Ω | R_Axial_DIN0207_L6.3mm_D2.5mm_P7.62mm_Horizontal |  |  |  | tht | Resistor
RV1, RV2, RV3 | 3 | 100KΩ | Potentiometer_Bourns_3296W_Vertical |  |  |  | tht | Potentiometer
U1, U2, U3 | 3 | LM311 | DIP-8_W7.62mm |  |  |  | tht | Voltage Comparator, DIP-8/SOIC-8
U4 | 1 | 74LS125 | DIP-14_W7.62mm |  |  |  | tht | Quad buffer 3-State outputs

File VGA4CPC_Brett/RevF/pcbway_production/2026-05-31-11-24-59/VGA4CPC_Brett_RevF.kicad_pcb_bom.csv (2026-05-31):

Designator | Quantity | Value | Footprint | Package | MPN | DNP | Mount_Type | Description
C1 | 1 | 100nF | C_Disc_D3.0mm_W2.0mm_P2.50mm |  |  |  | tht
H1, H2, H3, H4 | 4 | MountingHole | MountingHole_3.2mm_M3 |  |  |  | tht
J1 | 1 | CPC VIDEO IN | SDF80J |  |  |  | tht | Same Sky SDF-60J 6-pin DIN Socket
J2 | 1 | LUM OUT | 1560099E |  |  |  | tht | coaxial connector (BNC, SMA, SMB, SMC, Cinch/RCA, LEMO, ...)
J3 | 1 | +5V IN | BarrelJack_Horizontal |  |  |  | tht | DC Barrel Jack
J4 | 1 | VFREQ | PinHeader_1x02_P2.54mm_Vertical |  |  |  | tht | Generic connector, single row, 01x02, script generated (kicad-library-utils/schlib/autogen/connector/)
J5 | 1 | SPARE GPIO | PinHeader_1x07_P2.54mm_Vertical |  |  |  | tht | Generic connector, single row, 01x07, script generated (kicad-library-utils/schlib/autogen/connector/)
J6 | 1 | VGA OUT | DSUB-15-HD_Socket_Horizontal_P2.29x2.54mm_EdgePinOffset8.35mm_Housed_MountingHolesOffset10.89mm |  |  |  | tht | 15-pin D-SUB connector, socket (female), High density (3 columns), Triple Row, Generic, VGA-connector, Mounting Hole
J7 | 1 | CPC PLUS VIDEO IN | SDF80J |  |  |  | tht | 8-pin DIN connector
J8 | 1 | CPC PLUS AUDIO OUT | SJ335083ATR |  |  |  | tht | Audio Jack, 3 Poles (Stereo / TRS)
R1, R2, R3 | 3 | 75Ω | R_Axial_DIN0204_L3.6mm_D1.6mm_P1.90mm_Vertical |  |  |  | tht | Resistor, small symbol
R10, R11, R6, R7, R8, R9 | 6 | 820Ω | R_Axial_DIN0204_L3.6mm_D1.6mm_P1.90mm_Vertical |  |  |  | tht | Resistor, small symbol
R12, R13 | 2 | 220Ω | R_Axial_DIN0204_L3.6mm_D1.6mm_P1.90mm_Vertical |  |  |  | tht | Resistor, small symbol
R4 | 1 | 100Ω | R_Axial_DIN0204_L3.6mm_D1.6mm_P1.90mm_Vertical |  |  |  | tht | Resistor, small symbol
R5 | 1 | 1KΩ | R_Axial_DIN0204_L3.6mm_D1.6mm_P1.90mm_Vertical |  |  |  | tht | Resistor, small symbol
SW1 | 1 | RESET | SW_PUSH_6mm |  |  |  | tht | Push button switch, generic, two pins
SW2 | 1 | WACKED | SW_PUSH_6mm |  |  |  | tht | Push button switch, generic, two pins
U1 | 1 | RASPBERRY PI PICO2 | RaspberryPi_Pico_Common_Unspecified |  |  |  | tht | Versatile and inexpensive microcontroller module powered by RP2040 dual-core Arm Cortex-M0+ processor up to 133 MHz, 264kB SRAM, 2MB QSPI flash; also supports Raspberry Pi Pico 2
U2 | 1 | 74HCT245 | DIP-20_W7.62mm |  |  |  | tht | Octal BUS Transceivers, 3-State outputs
U6 | 1 | Comparator Daughterboard | Comparator Daughterboard |  |  |  | tht

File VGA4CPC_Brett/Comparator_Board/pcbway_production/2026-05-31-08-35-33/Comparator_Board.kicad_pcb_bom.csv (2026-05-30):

Designator | Quantity | Value | Footprint | Package | MPN | DNP | Mount_Type | Description | Height | Mouser Part Number | Mouser Price/Stock | Manufacturer_Name
C1, C2, C3, C4, C5, C6, C7, C8, C9 | 9 | 100nF | C_0805_2012Metric_Pad1.18x1.45mm_HandSolder |  |  |  | smt
J1 | 1 | INPUT | PinHeader_1x05_P2.54mm_Vertical |  |  |  | tht | Generic connector, single row, 01x05, script generated (kicad-library-utils/schlib/autogen/connector/)
J2 | 1 | OUTPUT | PinHeader_1x06_P2.54mm_Vertical |  |  |  | tht | Generic connector, single row, 01x06, script generated (kicad-library-utils/schlib/autogen/connector/)
R1 | 1 | 17KΩ | R_0805_2012Metric_Pad1.20x1.40mm_HandSolder |  |  |  | smt | Resistor, small symbol
R2 | 1 | 3KΩ | R_0805_2012Metric_Pad1.20x1.40mm_HandSolder |  |  |  | smt | Resistor, small symbol
R3 | 1 | 19KΩ | R_0805_2012Metric_Pad1.20x1.40mm_HandSolder |  |  |  | smt | Resistor, small symbol
R4 | 1 | 1KΩ | R_0805_2012Metric_Pad1.20x1.40mm_HandSolder |  |  |  | smt | Resistor, small symbol
U1, U2, U3 | 3 | TLV3232 | VSSOP-8_3x3mm_P0.65mm |  | TLV3202AID |  | smt | Dual, 40ns, microPower, Rail-to-Rail input Comparator with Push-pull outputs | 1.75 | 595-TLV3202AID | https://www.mouser.co.uk/ProductDetail/Texas-Instruments/TLV3202AID?qs=b5Ofe9I6AaEPCPyfWxMBkg%3D%3D | Texas Instruments

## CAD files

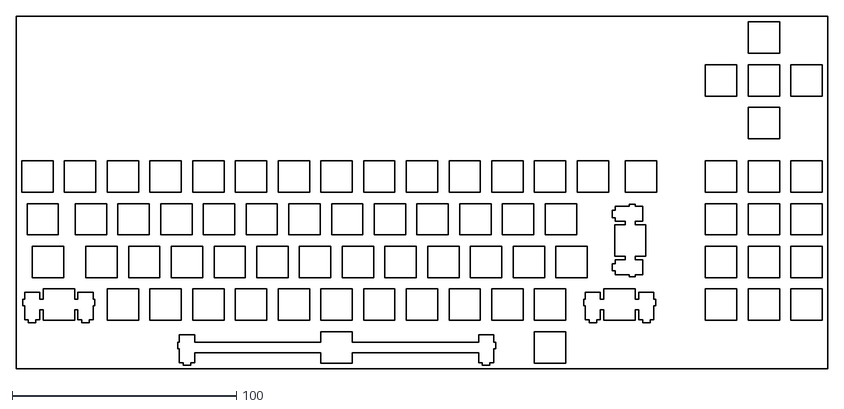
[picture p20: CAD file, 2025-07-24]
Amstrad_CPC_Keyboard/CPC464_CPC664/Keyboard-Layout-Editor/Match_Original_CPC664/amstrad-cpc664_original_plate.dxf
361.9 x 157.2

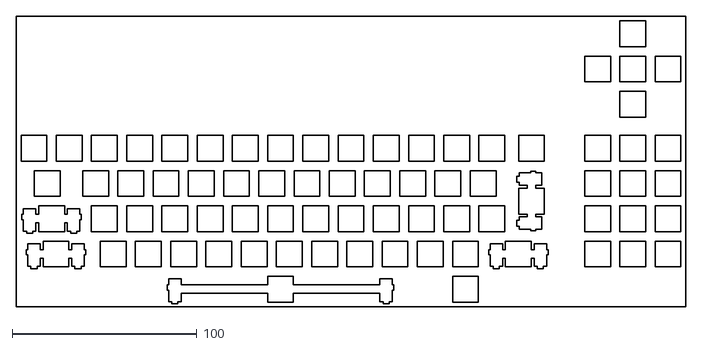
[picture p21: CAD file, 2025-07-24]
Amstrad_CPC_Keyboard/CPC464_CPC664/Keyboard-Layout-Editor/Modern_Key_Size/amstrad-cpc664_modern_plate.dxf
361.9 x 157.2

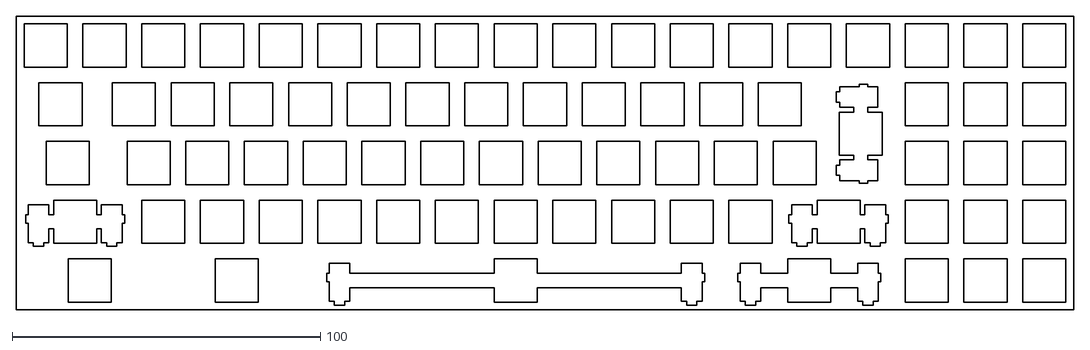
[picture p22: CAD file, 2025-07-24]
Amstrad_CPC_Keyboard/CPC6128/Keyboard-Layout-Editor/amstrad-cpc6128_plate.dxf
342.9 x 95.2

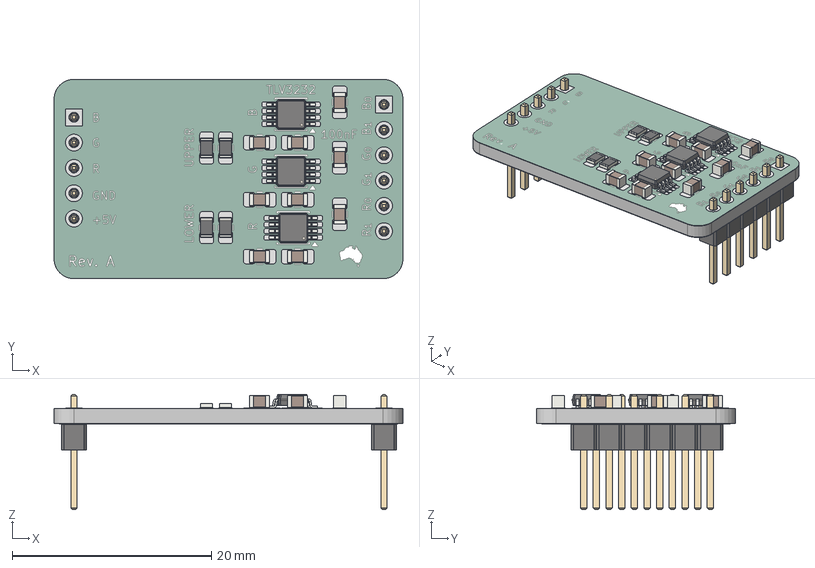
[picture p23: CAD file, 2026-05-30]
VGA4CPC_Brett/Comparator_Board.step
35.0 x 20.0 x 11.6 mm
R_0805_2012Metric x 4
C_0805_2012Metric x 9
VSSOP-8_3x3mm_P0.65mm x 3
PinHeader_1x06_P2.54mm_Vertical
PinHeader_1x05_P2.54mm_Vertical
Comparator_Board_copper
Comparator_Board_pad
Comparator_Board_via
Comparator_Board_silkscreen x 2
Comparator_Board_soldermask x 2
Comparator_Board_PCB

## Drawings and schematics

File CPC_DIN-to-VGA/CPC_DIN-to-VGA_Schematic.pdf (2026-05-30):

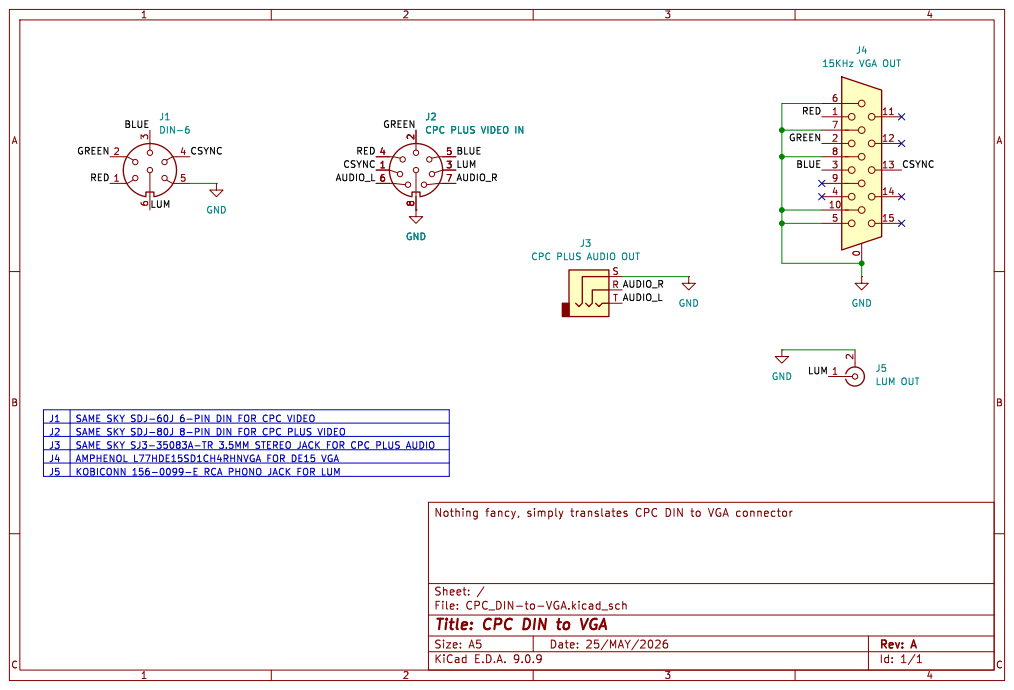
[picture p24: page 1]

J3 CPC PLUS AUDIO OUT

J1 | SAME SKY SDJ-60J 6-PIN DIN FOR CPC VIDEO
J2 | SAME SKY SDJ-80J 8-PIN DIN FOR CPC PLUS VIDEO
J3 | SAME SKY SJ3-35083A-TR 3.5MM STEREO JACK FOR CPC PLUS AUDIO
J4 | AMPHENOL L77HDE15SD1CH4RHNVGA FOR DE15 VGA
J5 | KOBICONN 156-0099-E RCA PHONO JACK FOR LUM

Id: 1/1 Title: CPC DIN to VGA

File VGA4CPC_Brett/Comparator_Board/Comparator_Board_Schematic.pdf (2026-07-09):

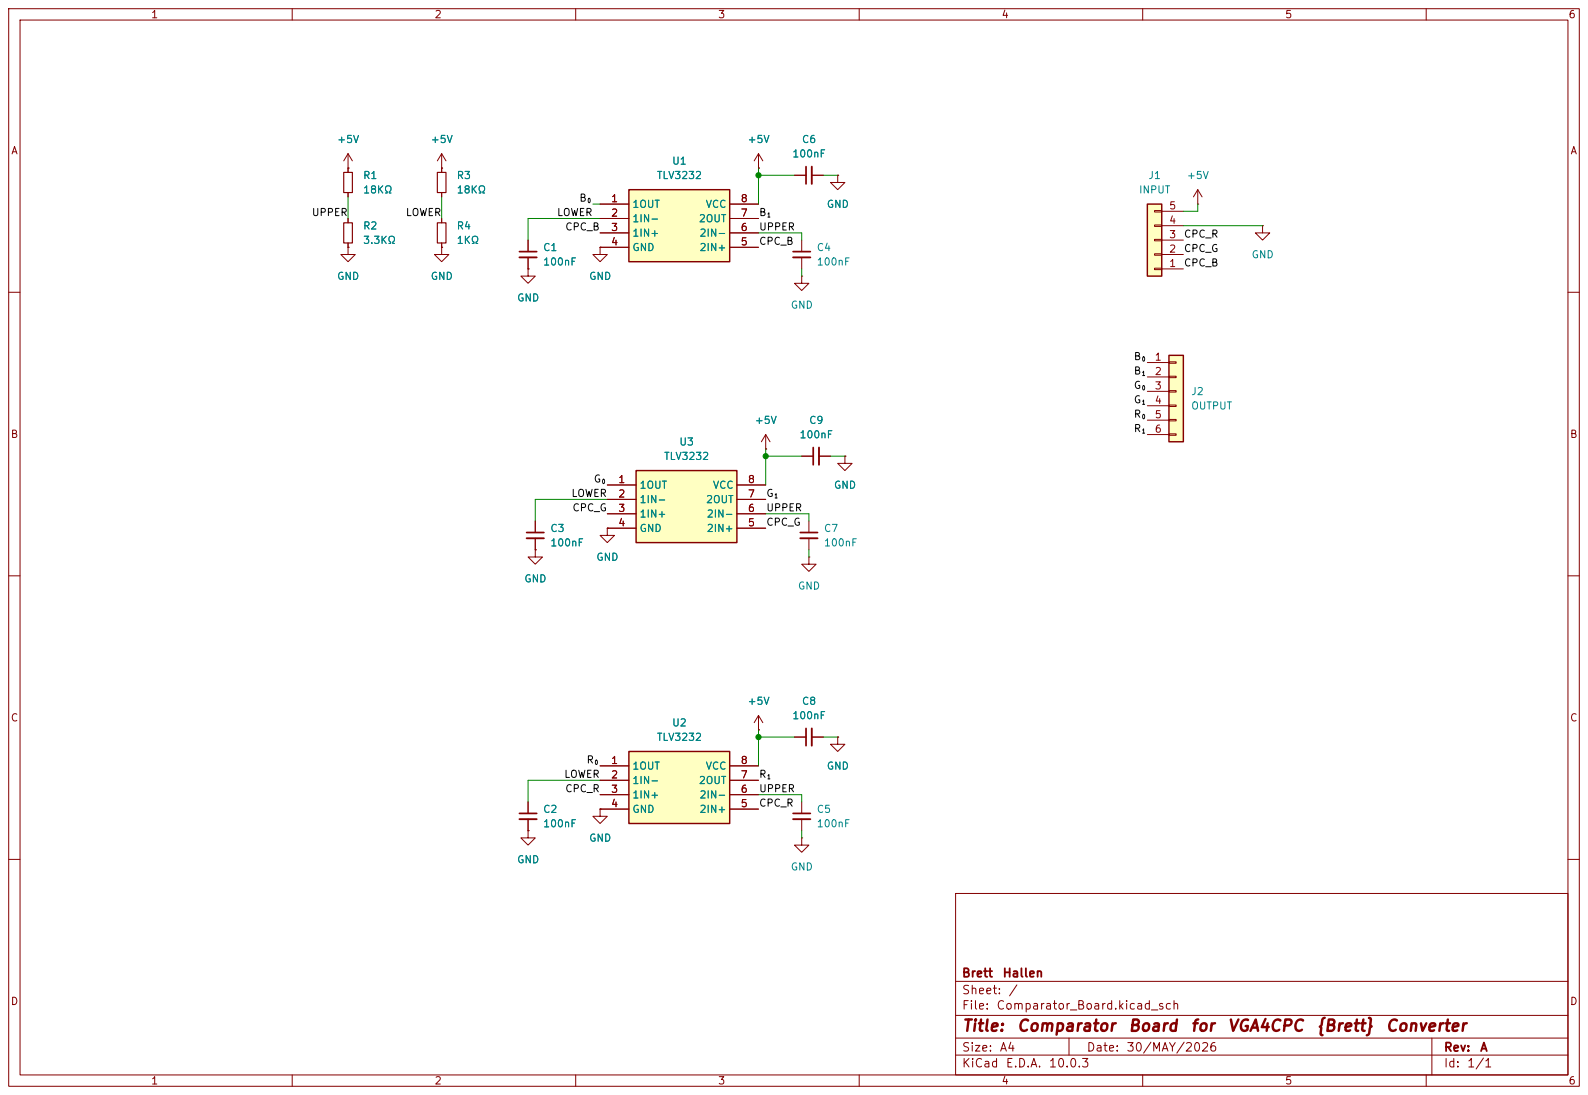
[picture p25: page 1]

Brett Hallen
Sheet: /
File: Comparator_Board.kicad_sch
Title: Comparator Board for VGA4CPC {Brett} Converter

Size: A4 | Rev: A
KiCad E.D.A. 10.0.3 | Id: 1/1

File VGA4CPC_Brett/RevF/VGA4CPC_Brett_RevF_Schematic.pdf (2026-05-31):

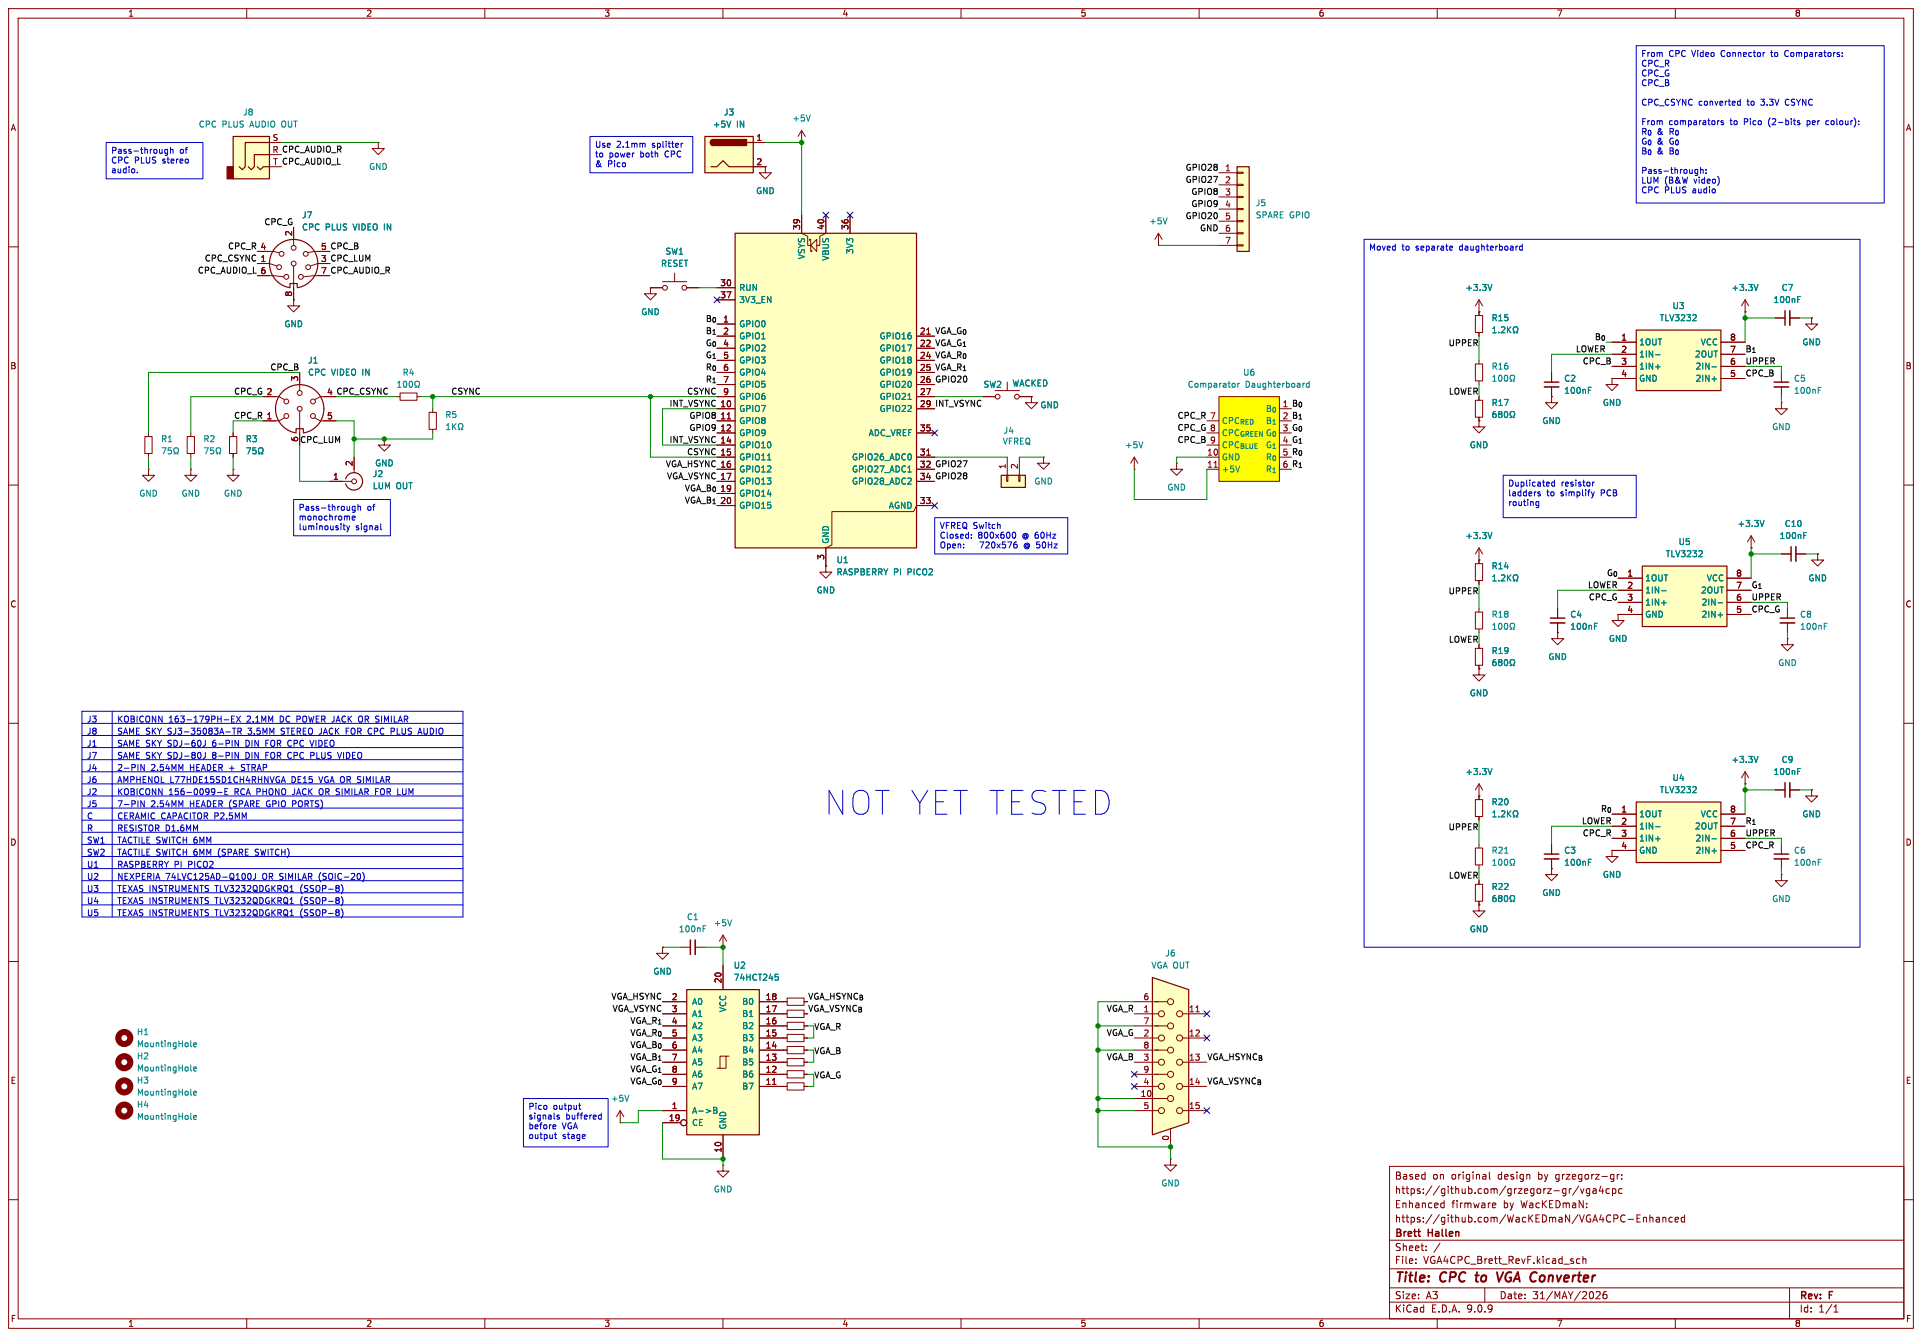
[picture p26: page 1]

routing Moved to separate daughterboard Use 2.1mm splitter
to power both CPC

3 3V3 36 GPIO16 21 GPIO17 22 GPIO18 24 GPIO19 25 GPIO20 26 GPIO21 27 GPIO22 29 ADC_VREF 35 GPIO26_ADC0 31 GPIO27_ADC1 32 GPIO28_ADC2 34 AGND 33 U1 RASPBERRY PI PICO2 GND GND

Pass-through: LUM (B&W video) CPC PLUS audio NOT YET TESTED

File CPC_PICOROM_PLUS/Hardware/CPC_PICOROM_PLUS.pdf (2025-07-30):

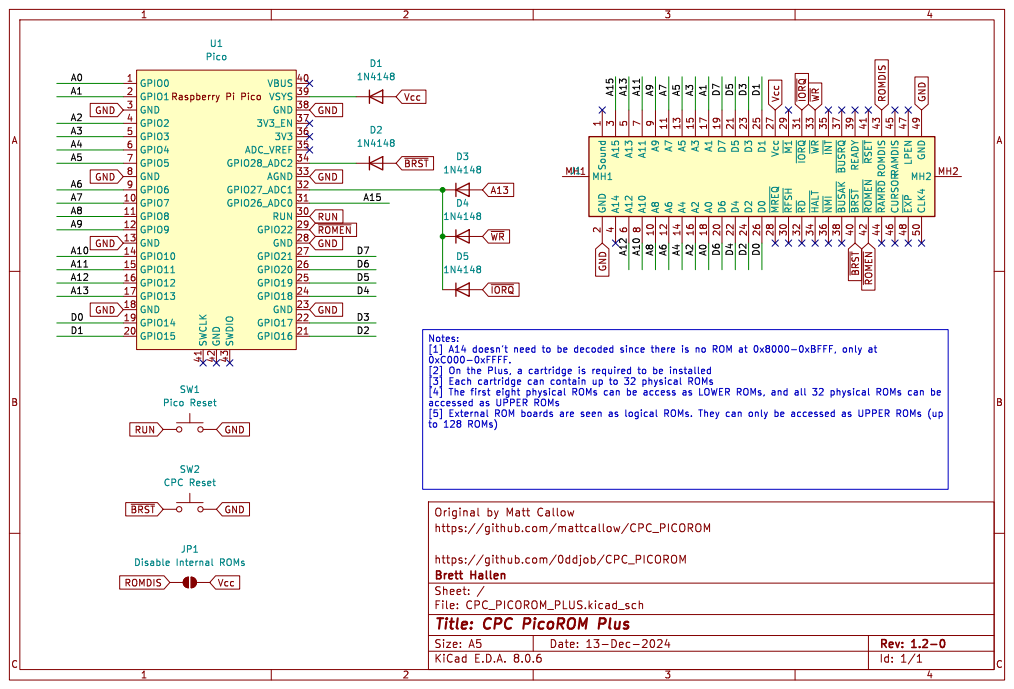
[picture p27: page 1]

3 ~{RFSH} 30 ~{IORQ}31 ~{RD} 32 ~{WR}33 ~{HALT} 34 ~{INT}35 ~{NMI} 36 ~{BUSRQ}37 ~{BUSAK} 38 READY 39 A14

4 ~{BRST} 40 ~{RSET}41 ~{ROMEN} 42 ROMDIS 43 ~{RAMRD} 44 RAMDIS 45 CURSOR 46 LPEN 47 ~{EXP} 48 GND 49 A13

https://github.com/mattcallow/CPC_PICOROM

https://github.com/0ddjob/CPC_PICOROM
Sheet: /
File: CPC_PICOROM_PLUS.kicad_sch
Title: CPC PicoROM Plus

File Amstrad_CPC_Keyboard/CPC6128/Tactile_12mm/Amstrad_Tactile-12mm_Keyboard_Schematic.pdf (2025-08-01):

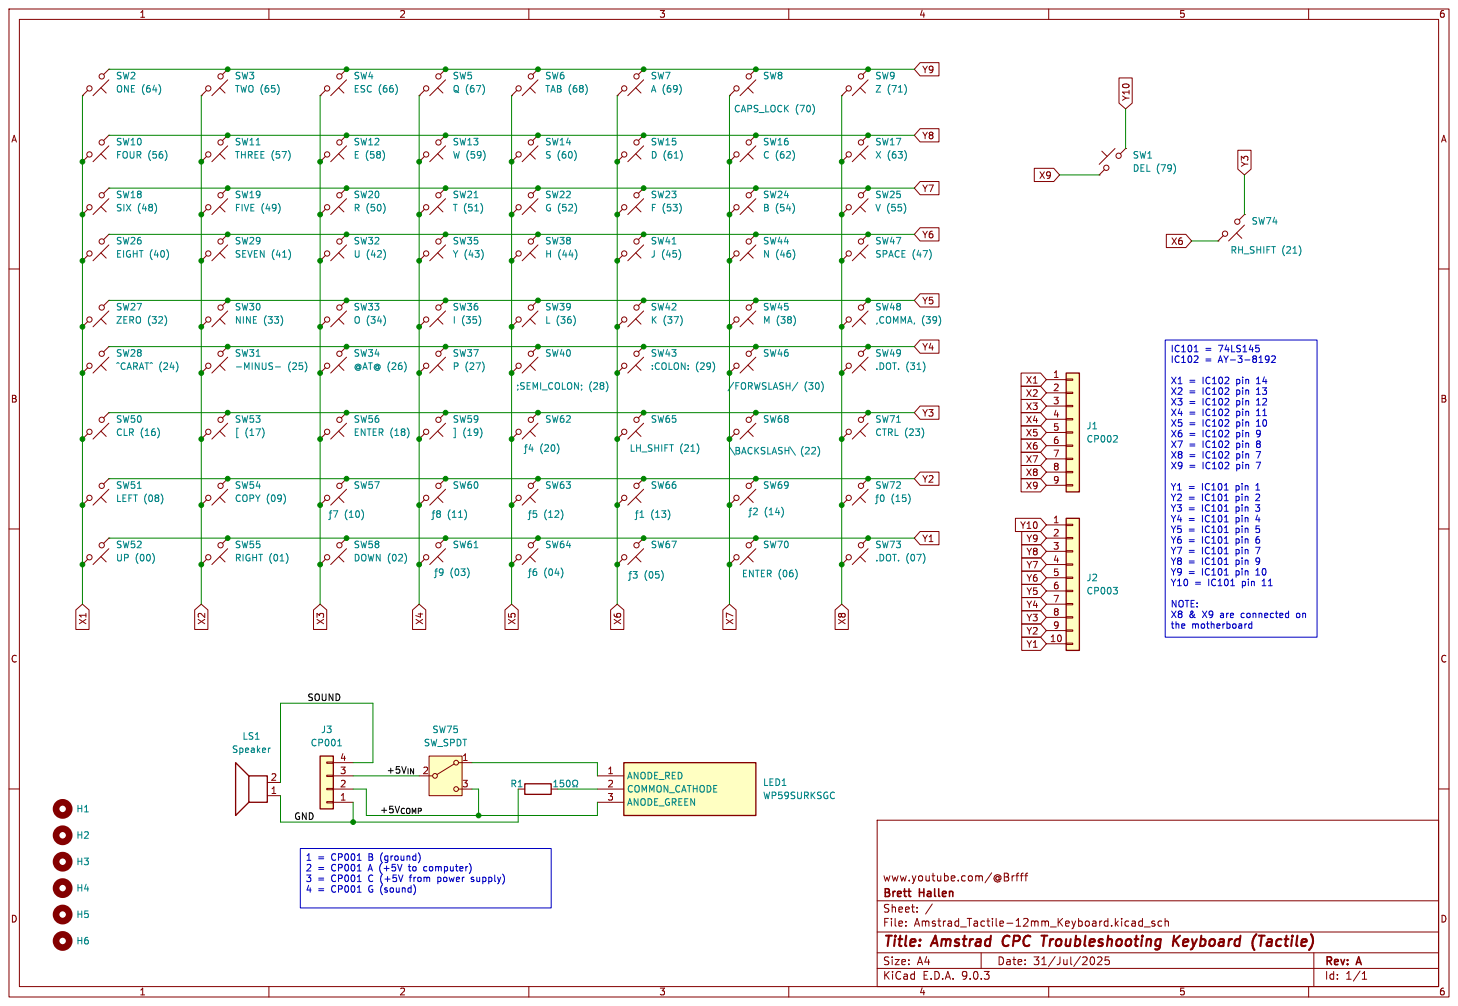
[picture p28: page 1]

1 = CP001 B (ground) 2 = CP001 A (+5V to computer) 3 = CP001 C (+5V from power supply) 4 = CP001 G (sound)

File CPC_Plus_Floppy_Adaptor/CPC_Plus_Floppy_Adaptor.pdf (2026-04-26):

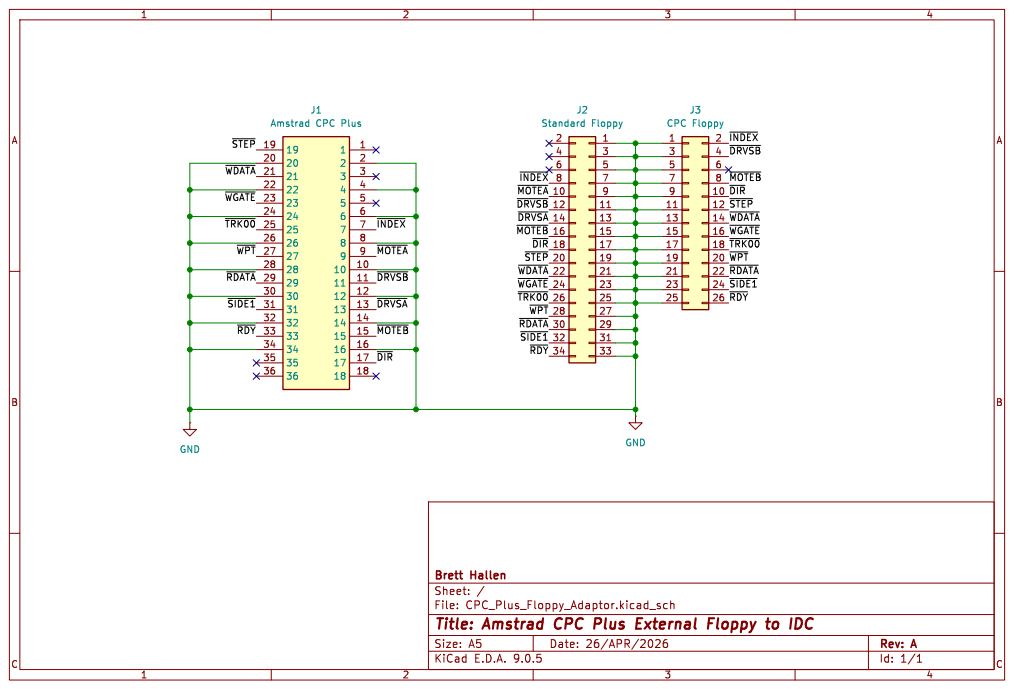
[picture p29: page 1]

16 | ~{WGATE}
18

Sheet: /
File: CPC_Plus_Floppy_Adaptor.kicad_sch
Title: Amstrad CPC Plus External Floppy to IDC

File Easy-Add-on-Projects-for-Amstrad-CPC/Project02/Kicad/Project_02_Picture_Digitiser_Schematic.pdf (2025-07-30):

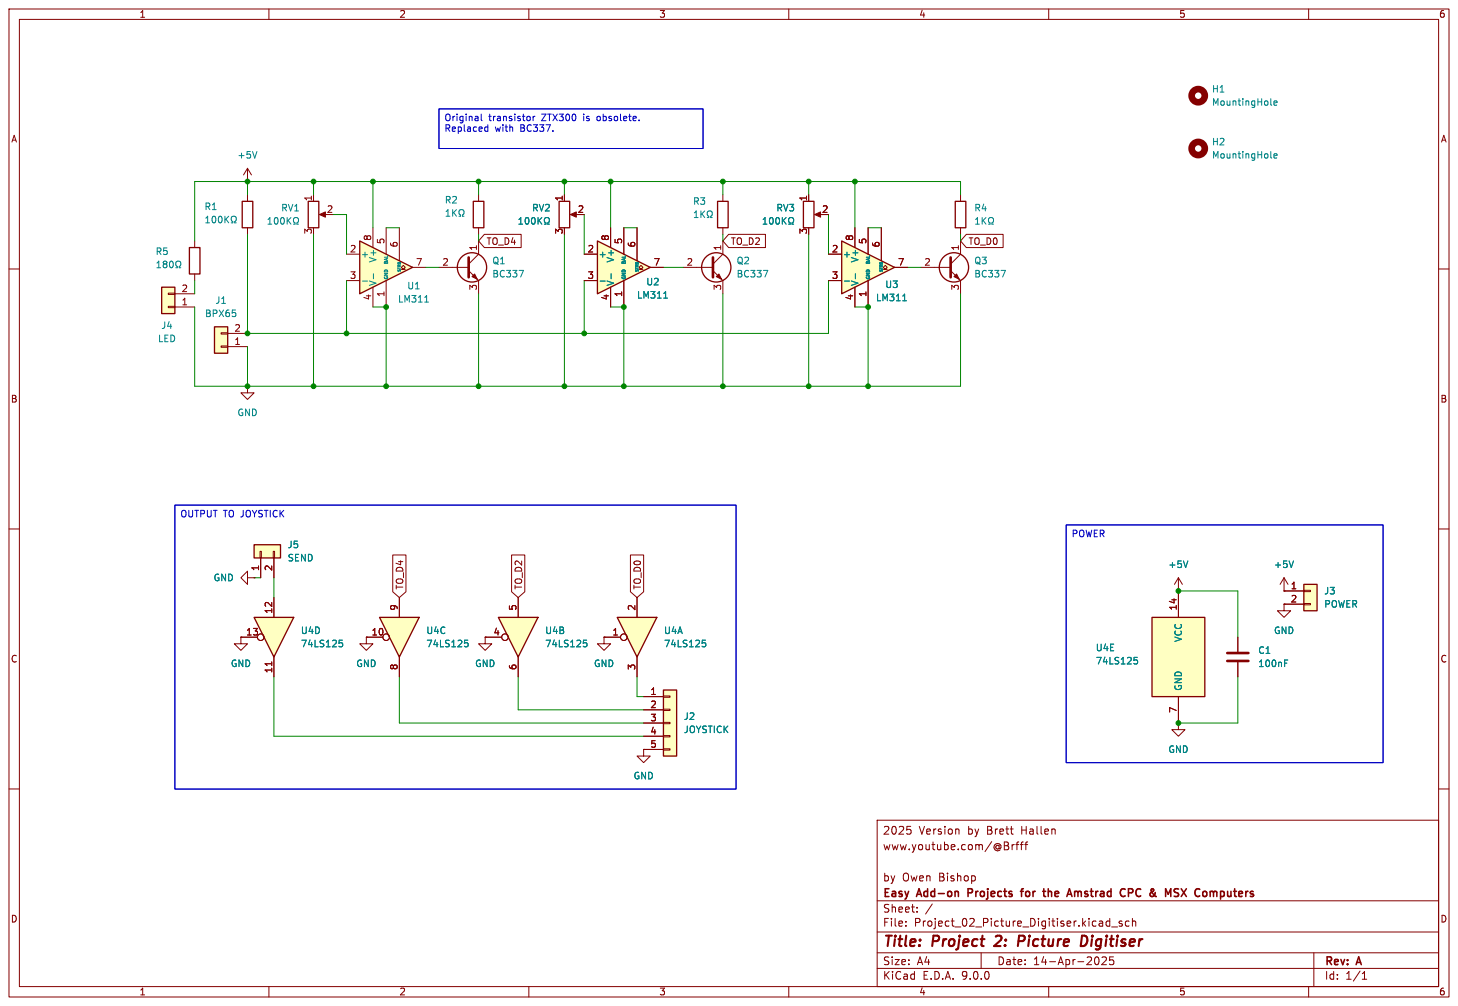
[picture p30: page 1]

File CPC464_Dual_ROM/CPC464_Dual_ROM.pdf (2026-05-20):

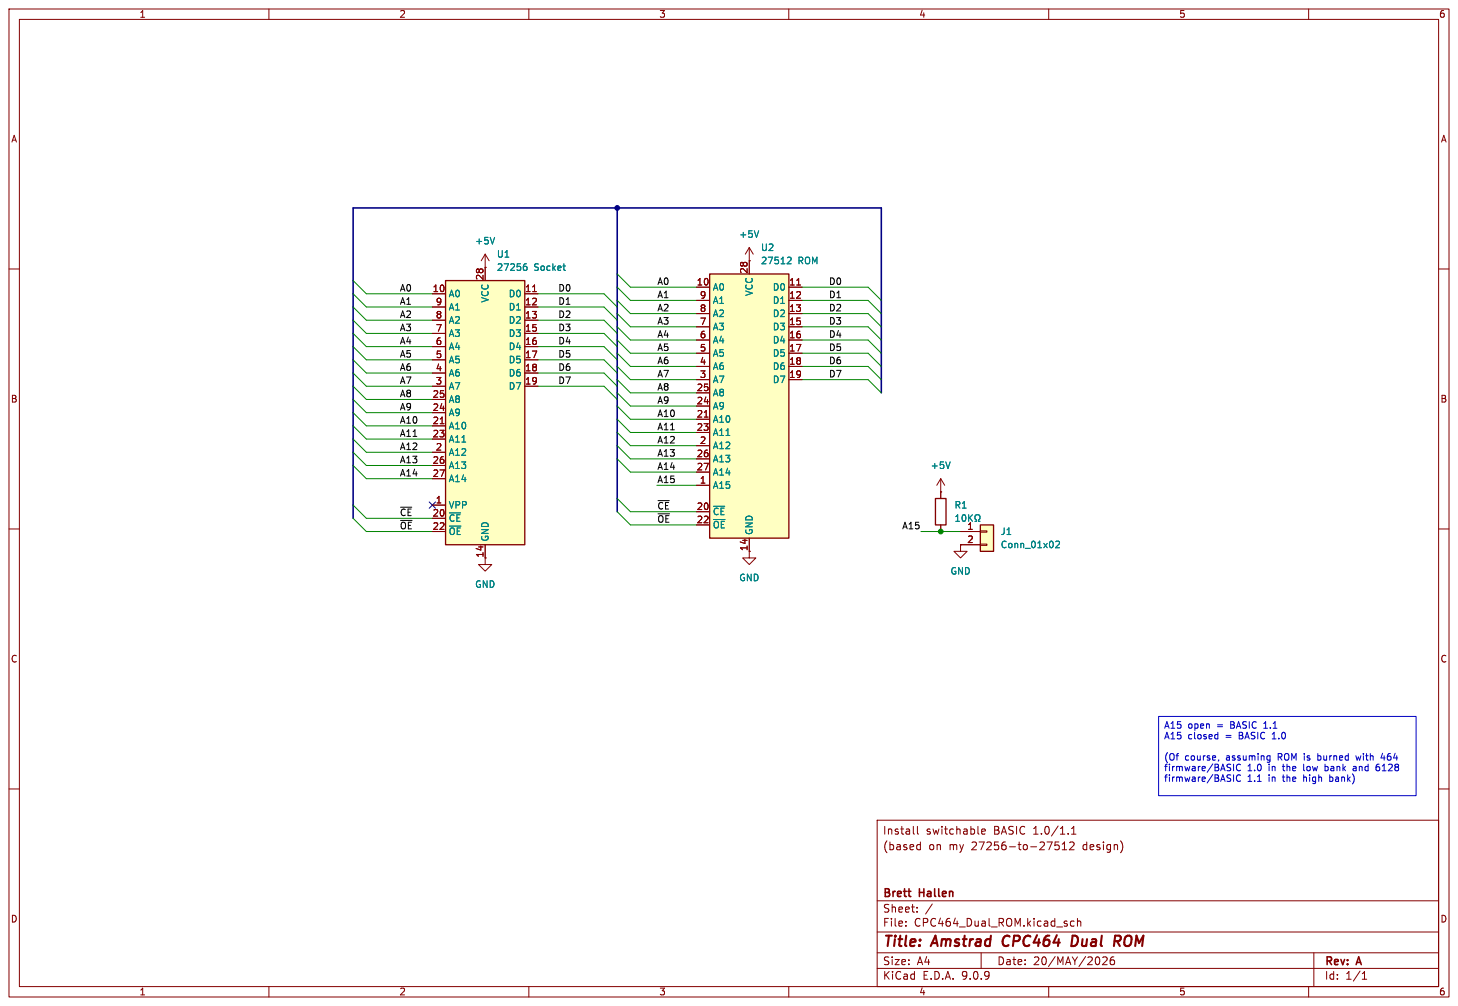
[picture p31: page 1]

Id: 1/1 Title: Amstrad CPC464 Dual ROM

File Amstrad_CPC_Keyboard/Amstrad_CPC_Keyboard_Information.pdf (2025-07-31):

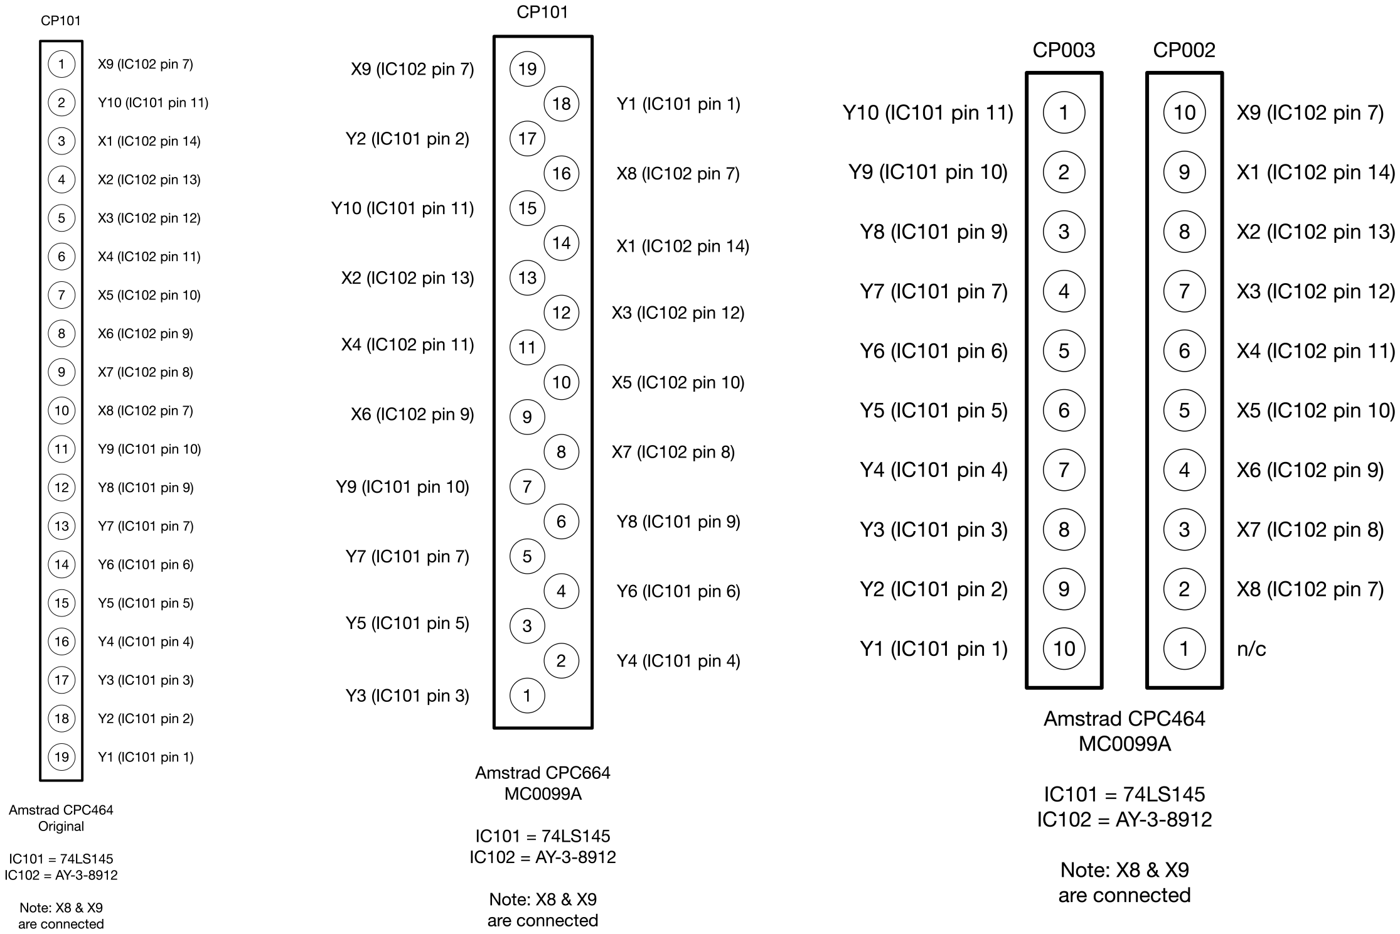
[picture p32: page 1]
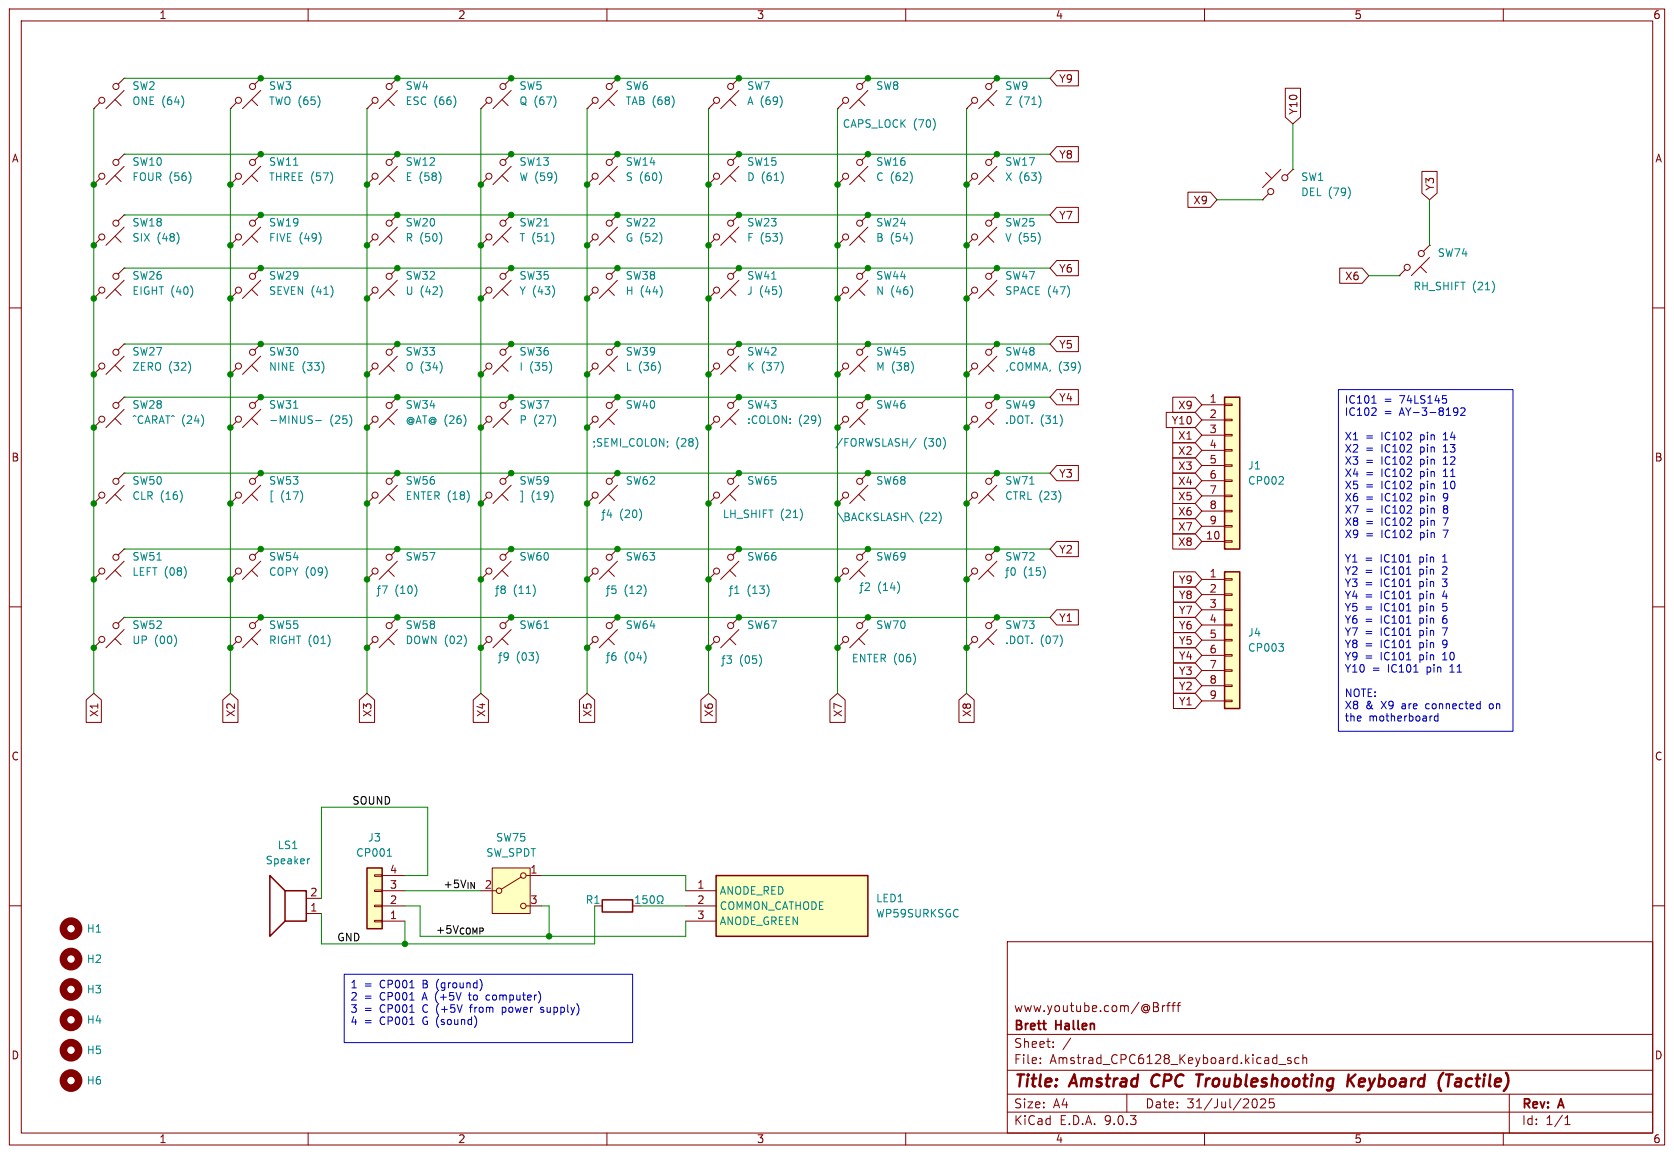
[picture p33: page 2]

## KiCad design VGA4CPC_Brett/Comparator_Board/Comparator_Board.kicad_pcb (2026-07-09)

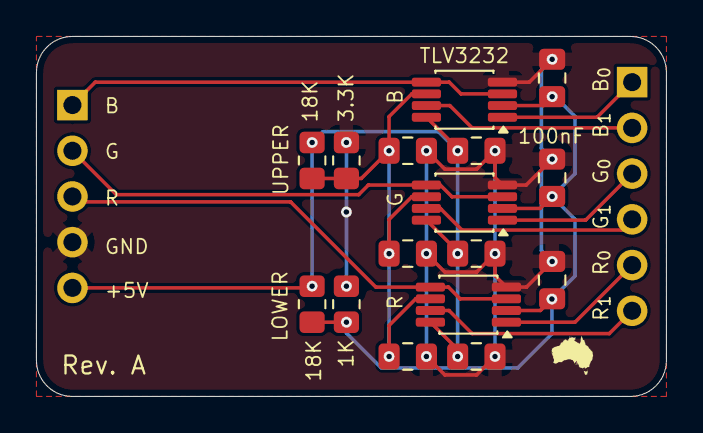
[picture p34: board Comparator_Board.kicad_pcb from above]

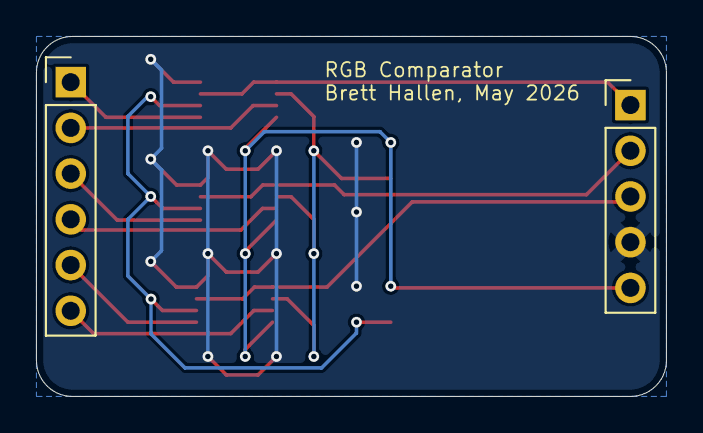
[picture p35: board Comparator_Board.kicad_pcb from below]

Board: 2 copper layers, 35.0 x 20.0 mm, 18 parts (2 on the bottom side), 13 nets.

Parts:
C1, C2, C3, C4, C5, C6, C7, C8, C9: 100nF; C_0805_2012Metric_Pad1.18x1.45mm_HandSolder
J1: INPUT; PinHeader_1x05_P2.54mm_Vertical
J2: OUTPUT; PinHeader_1x06_P2.54mm_Vertical
R1, R3: 18K; R_0805_2012Metric_Pad1.20x1.40mm_HandSolder
R2: 3.3K; R_0805_2012Metric_Pad1.20x1.40mm_HandSolder
R4: 1K; R_0805_2012Metric_Pad1.20x1.40mm_HandSolder
U1, U2, U3: TLV3232; VSSOP-8_3x3mm_P0.65mm

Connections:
+5V: C6.1, C8.1, C9.1, J1.5, R1.2, R3.2, U1.8 (VCC), U2.8 (VCC), U3.8 (VCC)
/B_{0}: J2.1, U1.1 (1OUT)
/B_{1}: J2.2, U1.7 (2OUT)
/CPC_B: J1.1, U1.3 (1IN+), U1.5 (2IN+)
/CPC_G: J1.2, U3.3 (1IN+), U3.5 (2IN+)
/CPC_R: J1.3, U2.3 (1IN+), U2.5 (2IN+)
/G_{0}: J2.3, U3.1 (1OUT)
/G_{1}: J2.4, U3.7 (2OUT)
/LOWER: C1.1, C2.1, C3.1, R3.1, R4.1, U1.2 (1IN-), U2.2 (1IN-), U3.2 (1IN-)
/R_{0}: J2.5, U2.1 (1OUT)
/R_{1}: J2.6, U2.7 (2OUT)
/UPPER: C4.1, C5.1, C7.1, R1.1, R2.2, U1.6 (2IN-), U2.6 (2IN-), U3.6 (2IN-)
GND: C1.2, C2.2, C3.2, C4.2, C5.2, C6.2, C7.2, C8.2, C9.2, J1.4, R2.1, R4.2, U1.4 (GND), U2.4 (GND), U3.4 (GND)

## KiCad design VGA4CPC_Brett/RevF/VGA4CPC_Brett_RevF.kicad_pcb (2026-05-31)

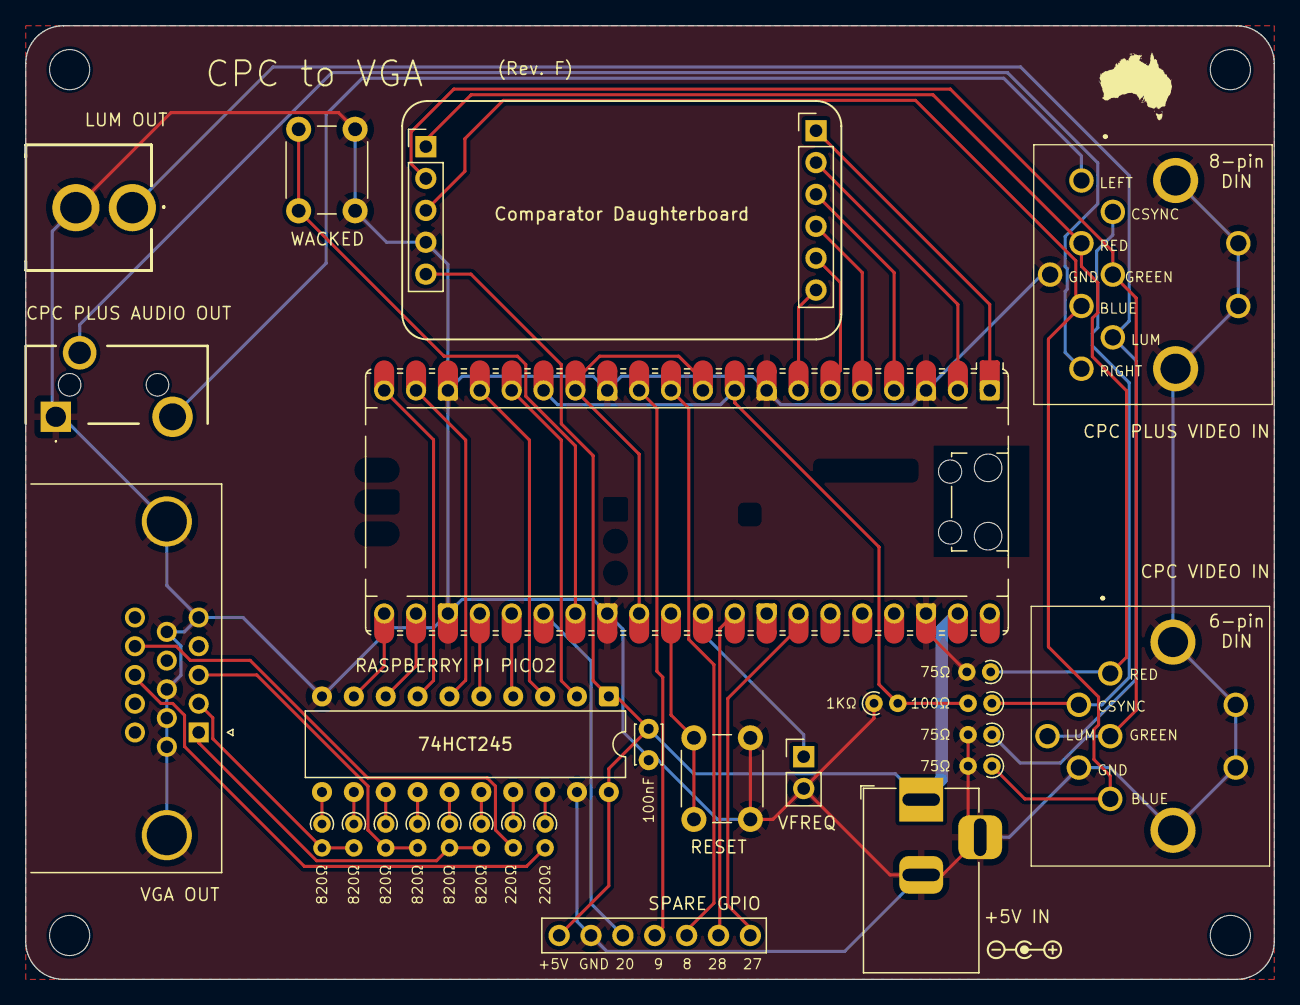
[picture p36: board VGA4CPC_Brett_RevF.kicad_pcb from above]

Board: 2 copper layers, 99.5 x 76.0 mm, 31 parts (0 on the bottom side), 46 nets.

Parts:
C1: 100nF; C_Disc_D3.0mm_W2.0mm_P2.50mm
H1, H2, H3, H4: MountingHole; MountingHole_3.2mm_M3
J1: CPC VIDEO IN; SDF80J
J2: LUM OUT; 1560099E
J3: +5V IN; BarrelJack_Horizontal
J4: VFREQ; PinHeader_1x02_P2.54mm_Vertical
J5: SPARE GPIO; PinHeader_1x07_P2.54mm_Vertical
J6: VGA OUT; DSUB-15-HD_Socket_Horizontal_P2.29x2.54mm_EdgePinOffset8.35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
J7: CPC PLUS VIDEO IN; SDF80J
J8: CPC PLUS AUDIO OUT; SJ335083ATR
R1, R2, R3: 75Ω; R_Axial_DIN0204_L3.6mm_D1.6mm_P1.90mm_Vertical
R4: 100Ω; R_Axial_DIN0204_L3.6mm_D1.6mm_P1.90mm_Vertical
R5: 1KΩ; R_Axial_DIN0204_L3.6mm_D1.6mm_P1.90mm_Vertical
R6, R7, R8, R9, R10, R11: 820Ω; R_Axial_DIN0204_L3.6mm_D1.6mm_P1.90mm_Vertical
R12, R13: 220Ω; R_Axial_DIN0204_L3.6mm_D1.6mm_P1.90mm_Vertical
SW1: RESET; SW_PUSH_6mm
SW2: WACKED; SW_PUSH_6mm
U1: RASPBERRY PI PICO2; RaspberryPi_Pico_Common_Unspecified
U2: 74HCT245; DIP-20_W7.62mm
U6: Comparator Daughterboard

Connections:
+5V: C1.2, J3.1, J5.7, U1.39 (VSYS), U2.1 (A->B), U2.20 (VCC), U6.11 (+5V)
/B_{0}: U1.1 (GPIO0), U6.1 (B_{0})
/B_{1}: U1.2 (GPIO1), U6.2 (B_{1})
/CPC_AUDIO_L: J7.6, J8.T
/CPC_AUDIO_R: J7.7, J8.R
/CPC_B: J1.3, J7.5, R1.1, U6.9 (CPC_{BLUE})
/CPC_CSYNC: J1.4, J7.1, R4.1
/CPC_G: J1.2, J7.2, R2.1, U6.8 (CPC_{GREEN})
/CPC_LUM: J1.6, J2.1 (In), J7.3
/CPC_R: J1.1, J7.4, R3.1, U6.7 (CPC_{RED})
/CSYNC: R4.2, R5.2, U1.9 (GPIO6), U1.15 (GPIO11)
/GPIO8: J5.3, U1.11 (GPIO8)
/GPIO9: J5.4, U1.12 (GPIO9)
/GPIO20: J5.5, U1.26 (GPIO20)
/GPIO27: J5.2, U1.32 (GPIO27_ADC1)
/GPIO28: J5.1, U1.34 (GPIO28_ADC2)
/G_{0}: U1.4 (GPIO2), U6.3 (G_{0})
/G_{1}: U1.5 (GPIO3), U6.4 (G_{1})
/INT_VSYNC: U1.10 (GPIO7), U1.14 (GPIO10), U1.29 (GPIO22)
/R_{0}: U1.6 (GPIO4), U6.5 (R_{0})
/R_{1}: U1.7 (GPIO5), U6.6 (R_{1})
/VGA_B: J6.3, R8.2, R9.2
/VGA_B_{0}: U1.19 (GPIO14), U2.6 (A4)
/VGA_B_{1}: U1.20 (GPIO15), U2.7 (A5)
/VGA_G: J6.2, R6.2, R7.2
/VGA_G_{0}: U1.21 (GPIO16), U2.9 (A7)
/VGA_G_{1}: U1.22 (GPIO17), U2.8 (A6)
/VGA_HSYNC: U1.16 (GPIO12), U2.2 (A0)
/VGA_HSYNC_{B}: J6.13, R12.2
/VGA_R: J6.1, R10.2, R11.2
/VGA_R_{0}: U1.24 (GPIO18), U2.5 (A3)
/VGA_R_{1}: U1.25 (GPIO19), U2.4 (A2)
/VGA_VSYNC: U1.17 (GPIO13), U2.3 (A1)
/VGA_VSYNC_{B}: J6.14, R13.2
GND: C1.1, J1.5, J2.2 (Ext), J3.2, J4.2, J5.6, J6.0, J6.5, J6.6, J6.7, J6.8, J6.10, J7.8, J8.S, R1.2, R2.2, R3.2, R5.1, SW1.1, SW2.2, U1.3 (GND), U1.8 (GND), U1.13 (GND), U1.18 (GND), U1.23 (GND), U1.28 (GND), U1.38 (GND), U2.10 (GND), U2.19 (CE), U6.10 (GND)
unnamed: J4.1, U1.31 (GPIO26_ADC0)
unnamed: SW2.1, U1.27 (GPIO21)
unnamed: SW1.2, U1.30 (RUN)
unnamed: R12.1, U2.18 (B0)
unnamed: R13.1, U2.17 (B1)
unnamed: R10.1, U2.16 (B2)
unnamed: R11.1, U2.15 (B3)
unnamed: R8.1, U2.14 (B4)
unnamed: R9.1, U2.13 (B5)
unnamed: R6.1, U2.12 (B6)
unnamed: R7.1, U2.11 (B7)

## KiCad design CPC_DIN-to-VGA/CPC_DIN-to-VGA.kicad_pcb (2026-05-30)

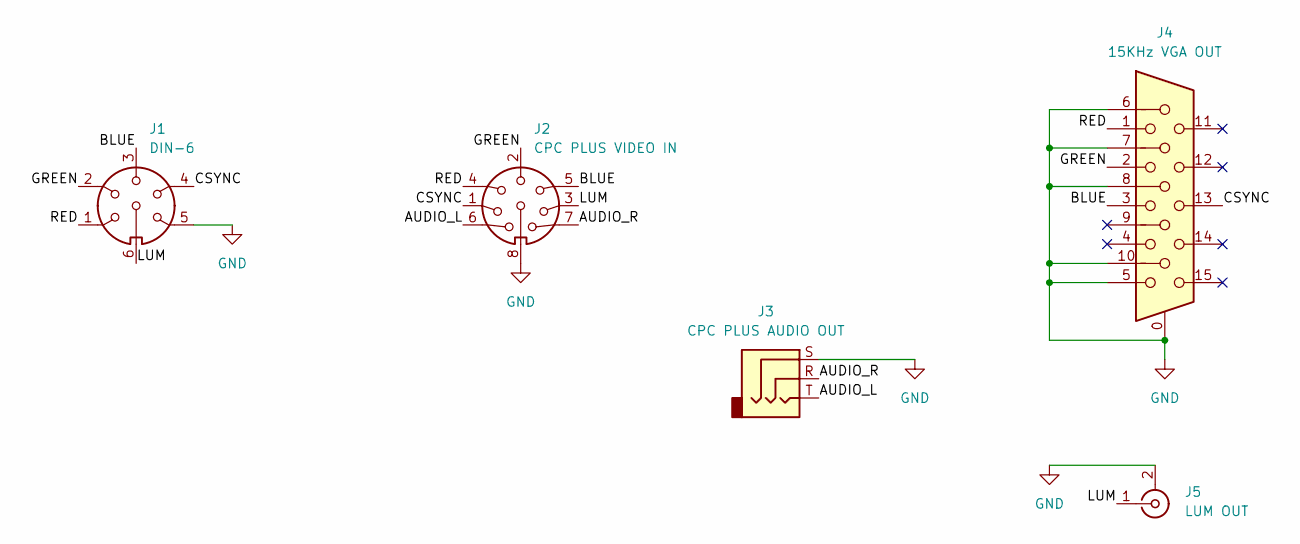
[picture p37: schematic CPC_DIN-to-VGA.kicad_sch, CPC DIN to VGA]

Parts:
J1: DIN-6; SDF80J
J2: CPC PLUS VIDEO IN; SDF80J
J3: CPC PLUS AUDIO OUT; SJ335083ATR
J4: 15KHz VGA OUT; DSUB-15-HD_Socket_Horizontal_P2.29x2.54mm_EdgePinOffset8.35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
J5: LUM OUT; 1560099E

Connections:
/AUDIO_L: J2.6, J3.T
/AUDIO_R: J2.7, J3.R
/BLUE: J1.3, J2.5, J4.3
/CSYNC: J1.4, J2.1, J4.13
/GREEN: J1.2, J2.2, J4.2
/LUM: J1.6, J2.3, J5.1 (In)
/RED: J1.1, J2.4, J4.1
GND: J1.5, J2.8, J3.S, J4.0, J4.5, J4.6, J4.7, J4.8, J4.10, J5.2 (Ext)

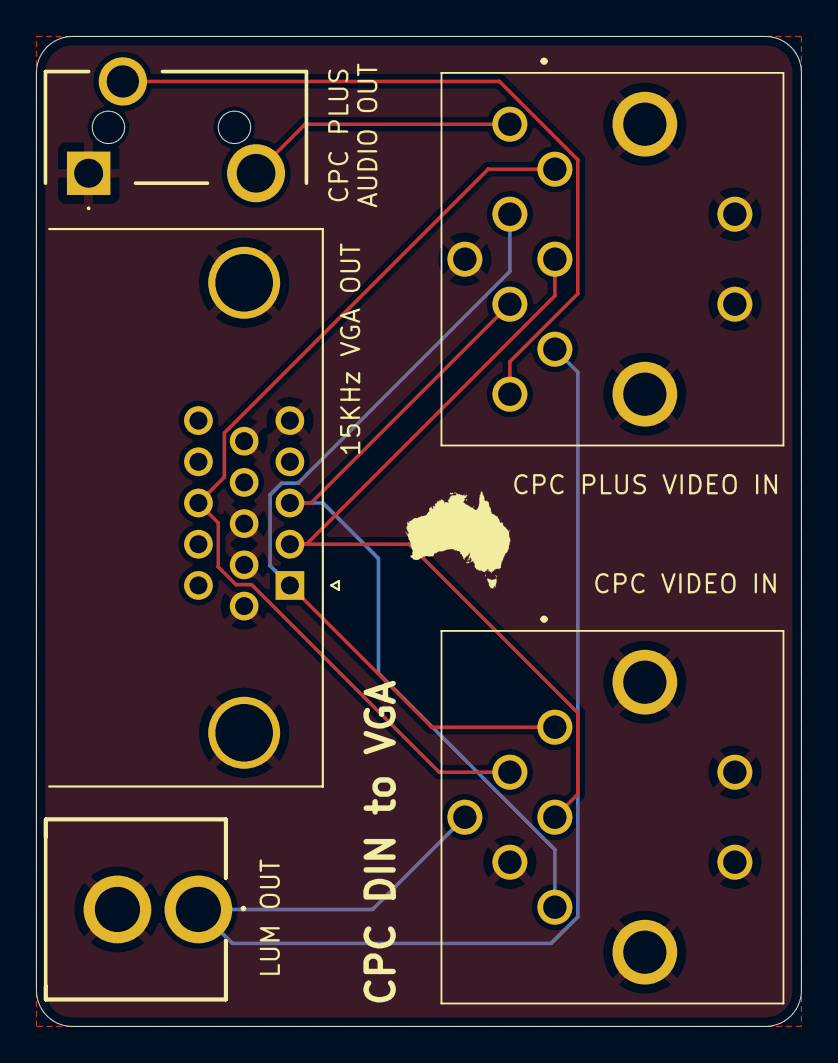
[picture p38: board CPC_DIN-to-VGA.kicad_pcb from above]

Board: 2 copper layers, 42.5 x 55.0 mm, 5 parts (0 on the bottom side), 8 nets.

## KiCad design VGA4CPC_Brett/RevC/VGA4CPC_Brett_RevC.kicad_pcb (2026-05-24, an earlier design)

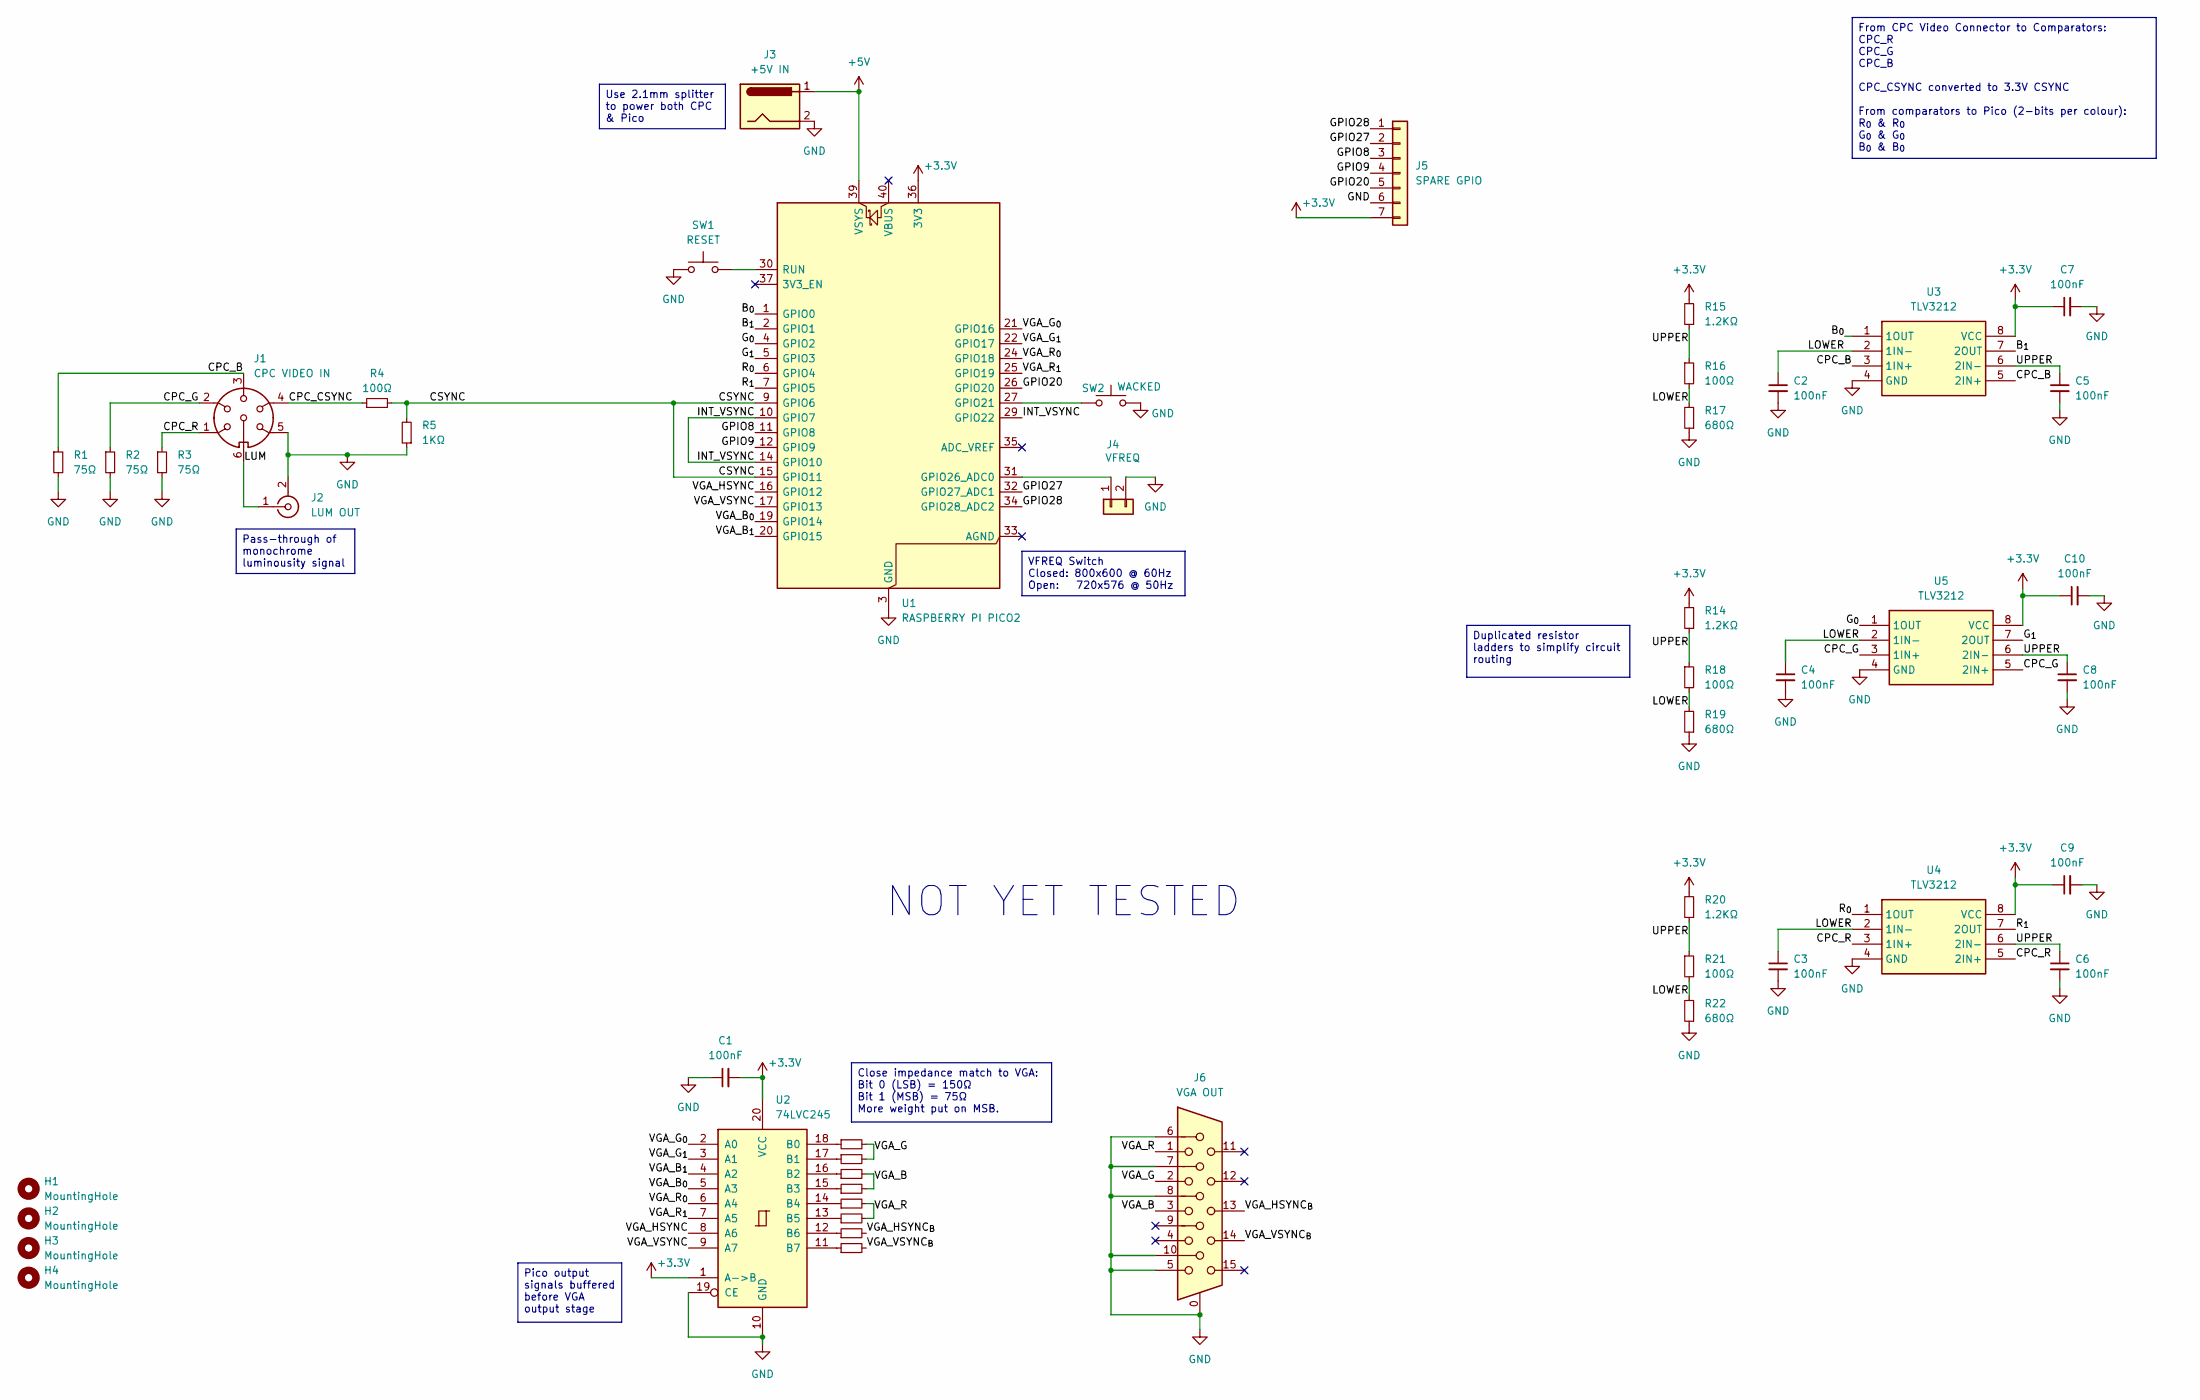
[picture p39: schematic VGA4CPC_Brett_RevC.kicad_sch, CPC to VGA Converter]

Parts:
C1, C2, C3, C4, C5, C6, C7, C8, C9, C10: 100nF; C_Disc_D3.0mm_W2.0mm_P2.50mm
H1, H2, H3, H4: MountingHole; MountingHole_3.2mm_M3
J1: CPC VIDEO IN; SDF80J
J2: LUM OUT; 1560099E
J3: +5V IN; BarrelJack_Horizontal
J4: VFREQ; PinHeader_1x02_P2.54mm_Vertical
J5: SPARE GPIO; PinHeader_1x07_P2.54mm_Vertical
J6: VGA OUT; DSUB-15-HD_Socket_Horizontal_P2.29x2.54mm_EdgePinOffset8.35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
R1, R2, R3, R7, R8, R11: 75Ω; R_Axial_DIN0204_L3.6mm_D1.6mm_P1.90mm_Vertical
R4, R16, R18, R21: 100Ω; R_Axial_DIN0204_L3.6mm_D1.6mm_P1.90mm_Vertical
R5: 1KΩ; R_Axial_DIN0204_L3.6mm_D1.6mm_P1.90mm_Vertical
R6, R9, R10: 150Ω; R_Axial_DIN0204_L3.6mm_D1.6mm_P1.90mm_Vertical
R12, R13: 220Ω; R_Axial_DIN0204_L3.6mm_D1.6mm_P1.90mm_Vertical
R14, R15, R20: 1.2KΩ; R_Axial_DIN0204_L3.6mm_D1.6mm_P1.90mm_Vertical
R17, R19, R22: 680Ω; R_Axial_DIN0204_L3.6mm_D1.6mm_P1.90mm_Vertical
SW1: RESET; SW_PUSH_6mm
SW2: WACKED; SW_PUSH_6mm
U1: RASPBERRY PI PICO2; RaspberryPi_Pico_Common_Unspecified
U2: 74LVC245; SOIC-20W_7.5x12.8mm_P1.27mm
U3, U4, U5: TLV3212; SOIC-8_3.9x4.9mm_P1.27mm; Mouser Part Number 595-TLV3202AID

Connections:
+3.3V: C1.2, C7.1, C9.1, C10.1, J5.7, R14.2, R15.2, R20.2, U1.36 (3V3), U2.1 (A->B), U2.20 (VCC), U3.8 (VCC), U4.8 (VCC), U5.8 (VCC)
+5V: J3.1, U1.39 (VSYS)
/B_{0}: U1.1 (GPIO0), U3.1 (1OUT)
/B_{1}: U1.2 (GPIO1), U3.7 (2OUT)
/CPC_B: J1.3, R1.1, U3.3 (1IN+), U3.5 (2IN+)
/CPC_CSYNC: J1.4, R4.1
/CPC_G: J1.2, R2.1, U5.3 (1IN+), U5.5 (2IN+)
/CPC_R: J1.1, R3.1, U4.3 (1IN+), U4.5 (2IN+)
/CSYNC: R4.2, R5.2, U1.9 (GPIO6), U1.15 (GPIO11)
/GPIO8: J5.3, U1.11 (GPIO8)
/GPIO9: J5.4, U1.12 (GPIO9)
/GPIO20: J5.5, U1.26 (GPIO20)
/GPIO27: J5.2, U1.32 (GPIO27_ADC1)
/GPIO28: J5.1, U1.34 (GPIO28_ADC2)
/G_{0}: U1.4 (GPIO2), U5.1 (1OUT)
/G_{1}: U1.5 (GPIO3), U5.7 (2OUT)
/INT_VSYNC: U1.10 (GPIO7), U1.14 (GPIO10), U1.29 (GPIO22)
/LOWER: C2.1, C3.1, C4.1, R16.2, R17.2, R18.2, R19.2, R21.2, R22.2, U3.2 (1IN-), U4.2 (1IN-), U5.2 (1IN-)
/LUM: J1.6, J2.1 (In)
/R_{0}: U1.6 (GPIO4), U4.1 (1OUT)
/R_{1}: U1.7 (GPIO5), U4.7 (2OUT)
/UPPER: C5.1, C6.1, C8.1, R14.1, R15.1, R16.1, R18.1, R20.1, R21.1, U3.6 (2IN-), U4.6 (2IN-), U5.6 (2IN-)
/VGA_B: J6.3, R8.2, R9.2
/VGA_B_{0}: U1.19 (GPIO14), U2.5 (A3)
/VGA_B_{1}: U1.20 (GPIO15), U2.4 (A2)
/VGA_G: J6.2, R6.2, R7.2
/VGA_G_{0}: U1.21 (GPIO16), U2.2 (A0)
/VGA_G_{1}: U1.22 (GPIO17), U2.3 (A1)
/VGA_HSYNC: U1.16 (GPIO12), U2.8 (A6)
/VGA_HSYNC_{B}: J6.13, R12.2
/VGA_R: J6.1, R10.2, R11.2
/VGA_R_{0}: U1.24 (GPIO18), U2.6 (A4)
/VGA_R_{1}: U1.25 (GPIO19), U2.7 (A5)
/VGA_VSYNC: U1.17 (GPIO13), U2.9 (A7)
/VGA_VSYNC_{B}: J6.14, R13.2
GND: C1.1, C2.2, C3.2, C4.2, C5.2, C6.2, C7.2, C8.2, C9.2, C10.2, J1.5, J2.2 (Ext), J3.2, J4.2, J5.6, J6.0, J6.5, J6.6, J6.7, J6.8, J6.10, R1.2, R2.2, R3.2, R5.1, R17.1, R19.1, R22.1, SW1.1, SW2.2, U1.3 (GND), U1.8 (GND), U1.13 (GND), U1.18 (GND), U1.23 (GND), U1.28 (GND), U1.38 (GND), U2.10 (GND), U2.19 (CE), U3.4 (GND), U4.4 (GND), U5.4 (GND)
unnamed: J4.1, U1.31 (GPIO26_ADC0)
unnamed: SW2.1, U1.27 (GPIO21)
unnamed: SW1.2, U1.30 (RUN)
unnamed: R6.1, U2.18 (B0)
unnamed: R7.1, U2.17 (B1)
unnamed: R8.1, U2.16 (B2)
unnamed: R9.1, U2.15 (B3)
unnamed: R10.1, U2.14 (B4)
unnamed: R11.1, U2.13 (B5)
unnamed: R12.1, U2.12 (B6)
unnamed: R13.1, U2.11 (B7)

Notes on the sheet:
NOT YET TESTED
From CPC Video Connector to Comparators: CPC_R CPC_G CPC_B CPC_CSYNC converted to 3.3V CSYNC From comparators to Pico (2-bits per colour): R_{0} & R_{0} G_{0} & G_{0} B_{0} & B_{0}
Use 2.1mm splitter to power both CPC & Pico
VFREQ Switch Closed: 800x600 @ 60Hz Open: 720x576 @ 50Hz
Pass-through of monochrome luminousity signal
Pico output signals buffered before VGA output stage
Duplicated resistor ladders to simplify circuit routing
Close impedance match to VGA: Bit 0 (LSB) = 150Ω Bit 1 (MSB) = 75Ω More weight put on MSB.

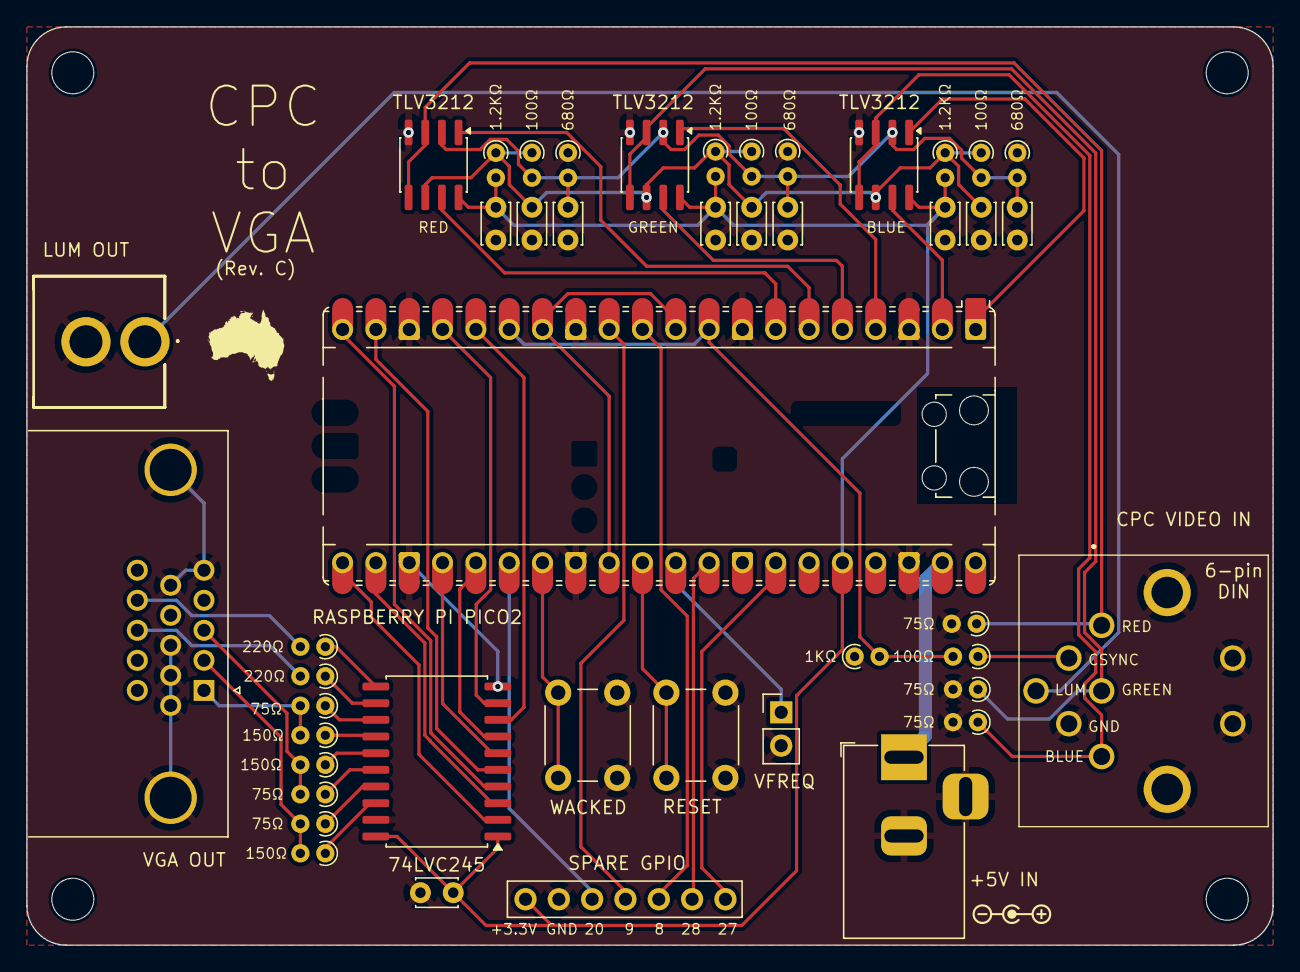
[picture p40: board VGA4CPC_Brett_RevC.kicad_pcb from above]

Board: 2 copper layers, 95.0 x 70.0 mm, 49 parts (0 on the bottom side), 47 nets.

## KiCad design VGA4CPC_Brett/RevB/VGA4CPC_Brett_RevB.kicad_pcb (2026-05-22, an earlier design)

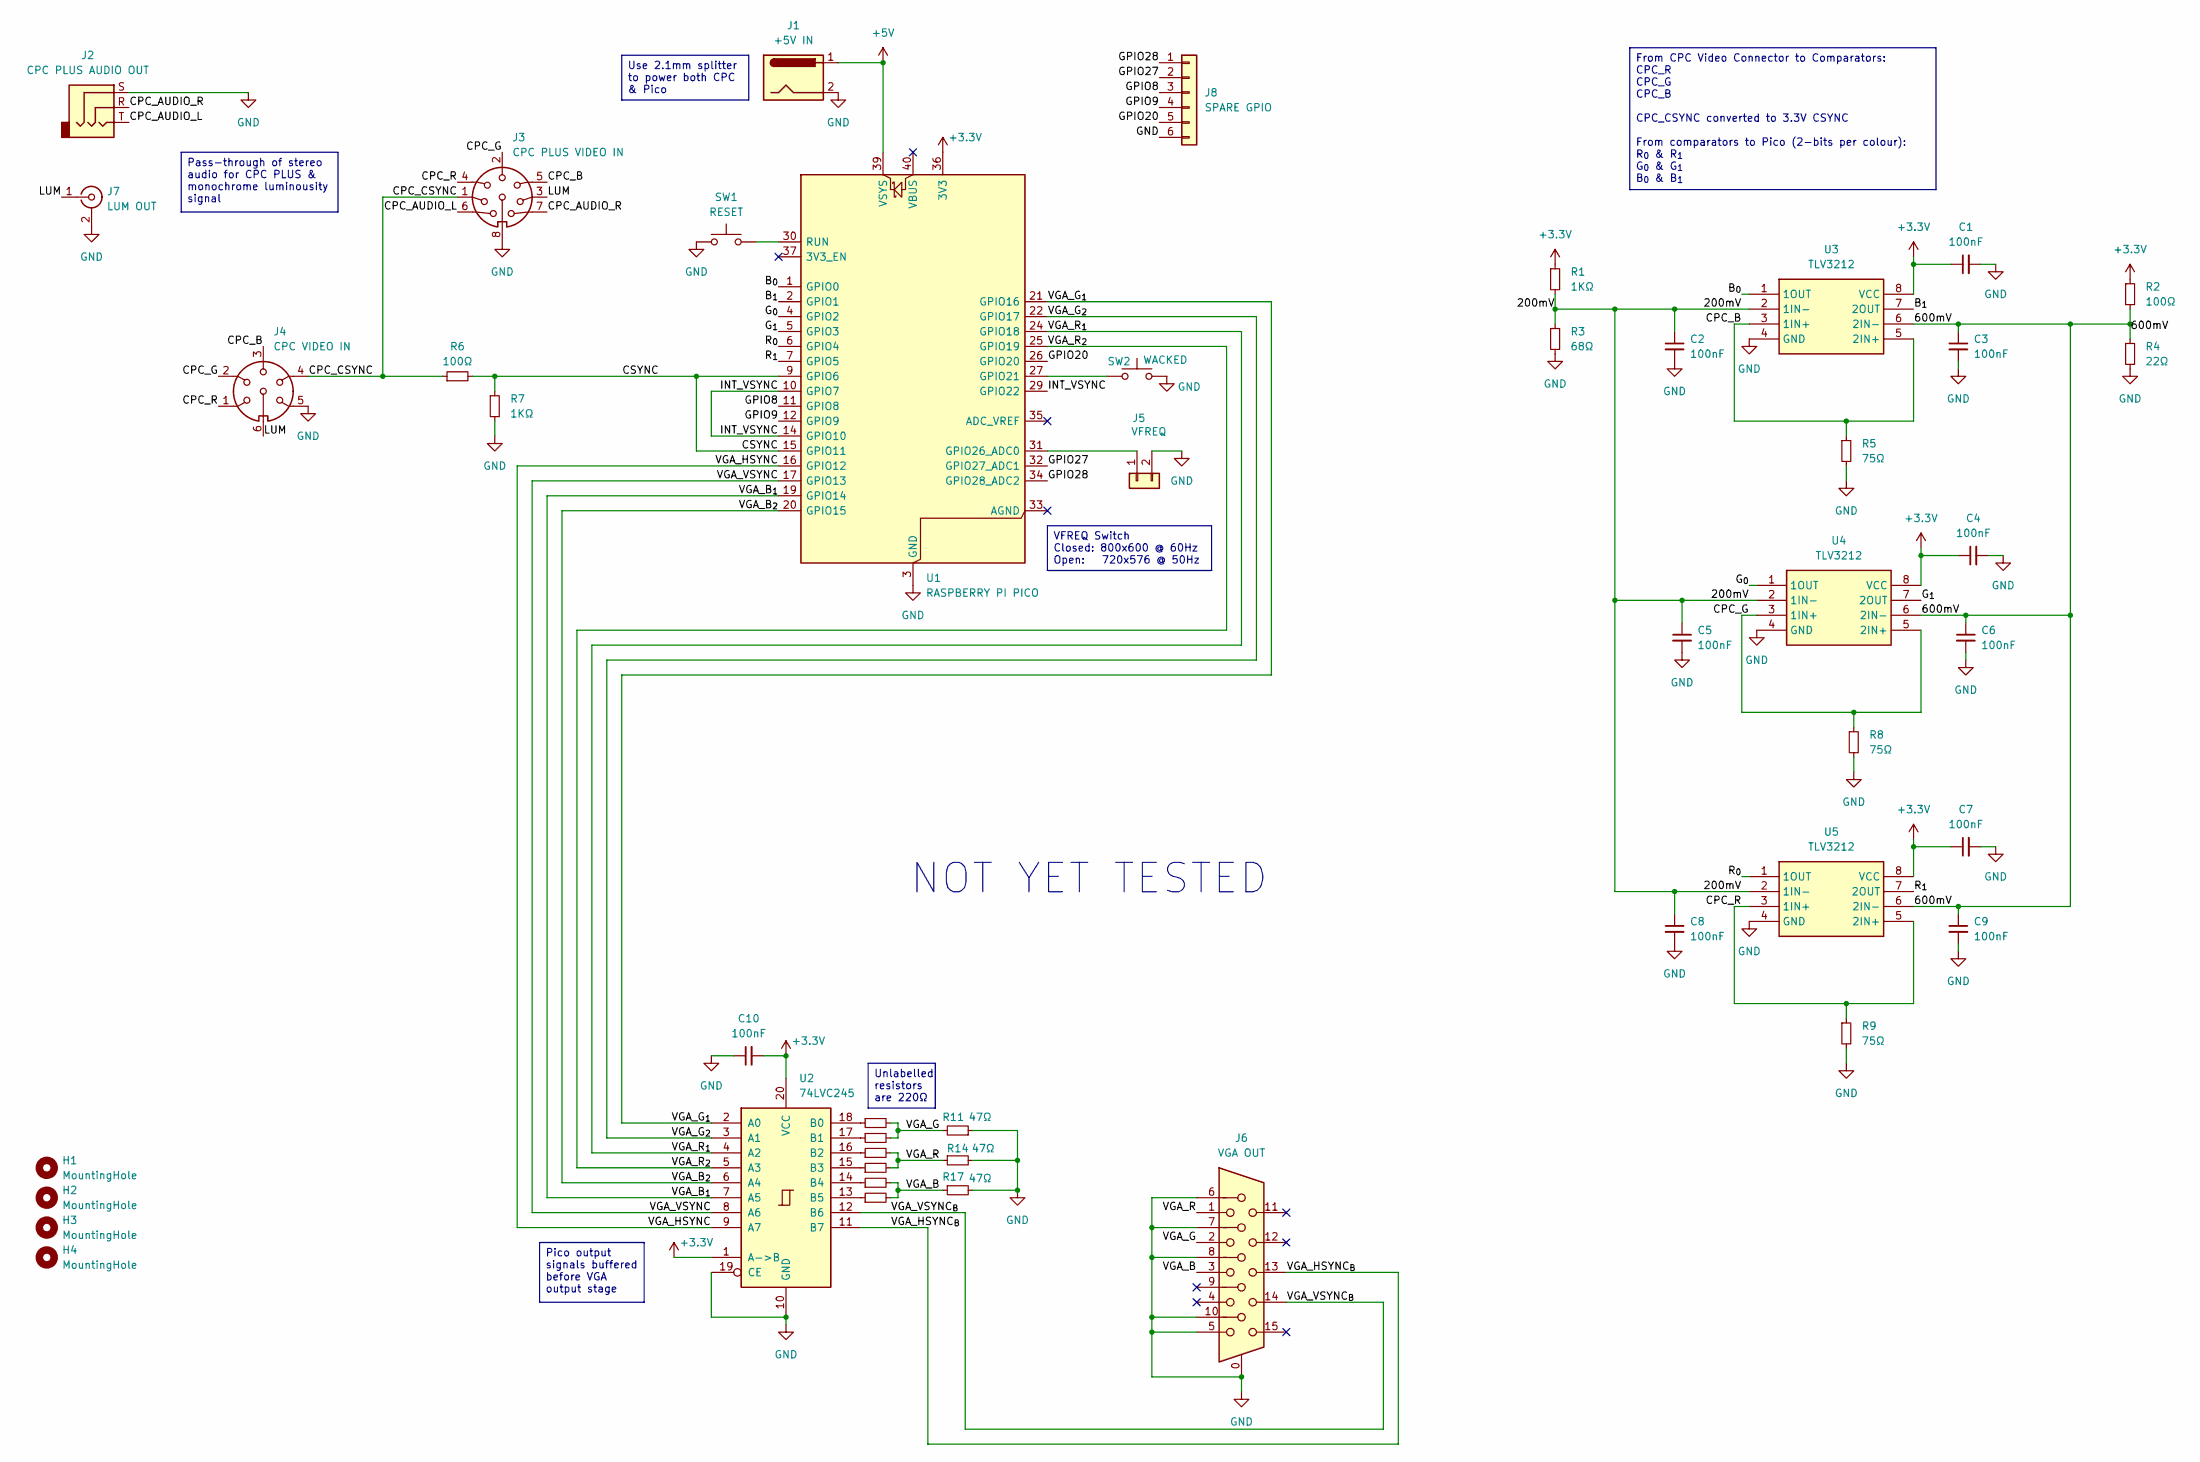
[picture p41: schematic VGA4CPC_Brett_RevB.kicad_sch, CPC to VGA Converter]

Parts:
C1, C2, C3, C4, C5, C6, C7, C8, C9, C10: 100nF; C_Disc_D3.4mm_W2.1mm_P2.50mm
H1, H2, H3, H4: MountingHole; MountingHole_3.2mm_M3
J1: +5V IN; BarrelJack_Horizontal
J2: CPC PLUS AUDIO OUT; SJ335083ATR
J3: CPC PLUS VIDEO IN; SDF80J
J4: CPC VIDEO IN; SDF80J
J5: VFREQ; PinHeader_1x02_P2.54mm_Vertical
J6: VGA OUT; DSUB-15-HD_Socket_Horizontal_P2.29x2.54mm_EdgePinOffset8.35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
J7: LUM OUT; 1560099E
J8: SPARE GPIO; PinHeader_1x06_P2.54mm_Vertical
R1, R7: 1KΩ; R_Axial_DIN0207_L6.3mm_D2.5mm_P7.62mm_Horizontal
R2, R6: 100Ω; R_Axial_DIN0207_L6.3mm_D2.5mm_P7.62mm_Horizontal
R3: 68Ω; R_Axial_DIN0207_L6.3mm_D2.5mm_P7.62mm_Horizontal
R4: 22Ω; R_Axial_DIN0207_L6.3mm_D2.5mm_P7.62mm_Horizontal
R5, R8, R9: 75Ω; R_Axial_DIN0207_L6.3mm_D2.5mm_P7.62mm_Horizontal
R10, R12, R13, R15, R16, R18: 220Ω; R_Axial_DIN0207_L6.3mm_D2.5mm_P7.62mm_Horizontal
R11, R14, R17: 47Ω; R_Axial_DIN0207_L6.3mm_D2.5mm_P7.62mm_Horizontal
SW1: RESET; SW_PUSH_6mm
SW2: WACKED; SW_PUSH_6mm
U1: RASPBERRY PI PICO; RaspberryPi_Pico_Common_Unspecified
U2: 74LVC245; SOIC-20W_7.5x12.8mm_P1.27mm
U3, U4, U5: TLV3212; SOIC-8_3.9x4.9mm_P1.27mm; Mouser Part Number 595-TLV3202AID

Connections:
+3.3V: C1.1, C4.1, C7.1, C10.2, R1.1, R2.1, U1.36 (3V3), U2.1 (A->B), U2.20 (VCC), U3.8 (VCC), U4.8 (VCC), U5.8 (VCC)
+5V: J1.1, U1.39 (VSYS)
/200mV: C2.1, C5.1, C8.1, R1.2, R3.1, U3.2 (1IN-), U4.2 (1IN-), U5.2 (1IN-)
/600mV: C3.1, C6.1, C9.1, R2.2, R4.1, U3.6 (2IN-), U4.6 (2IN-), U5.6 (2IN-)
/B_{0}: U1.1 (GPIO0), U3.1 (1OUT)
/B_{1}: U1.2 (GPIO1), U3.7 (2OUT)
/CPC_AUDIO_L: J2.T, J3.6
/CPC_AUDIO_R: J2.R, J3.7
/CPC_B: J3.5, J4.3, R5.1, U3.3 (1IN+), U3.5 (2IN+)
/CPC_CSYNC: J3.1, J4.4, R6.1
/CPC_G: J3.2, J4.2, R8.1, U4.3 (1IN+), U4.5 (2IN+)
/CPC_R: J3.4, J4.1, R9.1, U5.3 (1IN+), U5.5 (2IN+)
/CSYNC: R6.2, R7.1, U1.9 (GPIO6), U1.15 (GPIO11)
/GPIO8: J8.3, U1.11 (GPIO8)
/GPIO9: J8.4, U1.12 (GPIO9)
/GPIO20: J8.5, U1.26 (GPIO20)
/GPIO27: J8.2, U1.32 (GPIO27_ADC1)
/GPIO28: J8.1, U1.34 (GPIO28_ADC2)
/G_{0}: U1.4 (GPIO2), U4.1 (1OUT)
/G_{1}: U1.5 (GPIO3), U4.7 (2OUT)
/INT_VSYNC: U1.10 (GPIO7), U1.14 (GPIO10), U1.29 (GPIO22)
/LUM: J3.3, J4.6, J7.1 (In)
/R_{0}: U1.6 (GPIO4), U5.1 (1OUT)
/R_{1}: U1.7 (GPIO5), U5.7 (2OUT)
/VGA_B: J6.3, R16.2, R17.1, R18.2
/VGA_B_{1}: U1.19 (GPIO14), U2.7 (A5)
/VGA_B_{2}: U1.20 (GPIO15), U2.6 (A4)
/VGA_G: J6.2, R10.2, R11.2, R12.2
/VGA_G_{1}: U1.21 (GPIO16), U2.2 (A0)
/VGA_G_{2}: U1.22 (GPIO17), U2.3 (A1)
/VGA_HSYNC: U1.16 (GPIO12), U2.9 (A7)
/VGA_HSYNC_{B}: J6.13, U2.11 (B7)
/VGA_R: J6.1, R13.2, R14.1, R15.2
/VGA_R_{1}: U1.24 (GPIO18), U2.4 (A2)
/VGA_R_{2}: U1.25 (GPIO19), U2.5 (A3)
/VGA_VSYNC: U1.17 (GPIO13), U2.8 (A6)
/VGA_VSYNC_{B}: J6.14, U2.12 (B6)
GND: C1.2, C2.2, C3.2, C4.2, C5.2, C6.2, C7.2, C8.2, C9.2, C10.1, J1.2, J2.S, J3.8, J4.5, J5.2, J6.0, J6.5, J6.6, J6.7, J6.8, J6.10, J7.2 (Ext), J8.6, R3.2, R4.2, R5.2, R7.2, R8.2, R9.2, R11.1, R14.2, R17.2, SW1.1, SW2.2, U1.3 (GND), U1.8 (GND), U1.13 (GND), U1.18 (GND), U1.23 (GND), U1.28 (GND), U1.38 (GND), U2.10 (GND), U2.19 (CE), U3.4 (GND), U4.4 (GND), U5.4 (GND)
unnamed: J5.1, U1.31 (GPIO26_ADC0)
unnamed: SW2.1, U1.27 (GPIO21)
unnamed: SW1.2, U1.30 (RUN)
unnamed: R10.1, U2.18 (B0)
unnamed: R12.1, U2.17 (B1)
unnamed: R15.1, U2.16 (B2)
unnamed: R13.1, U2.15 (B3)
unnamed: R16.1, U2.14 (B4)
unnamed: R18.1, U2.13 (B5)

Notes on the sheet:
NOT YET TESTED
From CPC Video Connector to Comparators: CPC_R CPC_G CPC_B CPC_CSYNC converted to 3.3V CSYNC From comparators to Pico (2-bits per colour): R_{0} & R_{1} G_{0} & G_{1} B_{0} & B_{1}
Use 2.1mm splitter to power both CPC & Pico
Unlabelled resistors are 220Ω
VFREQ Switch Closed: 800x600 @ 60Hz Open: 720x576 @ 50Hz
Pass-through of stereo audio for CPC PLUS & monochrome luminousity signal
Pico output signals buffered before VGA output stage

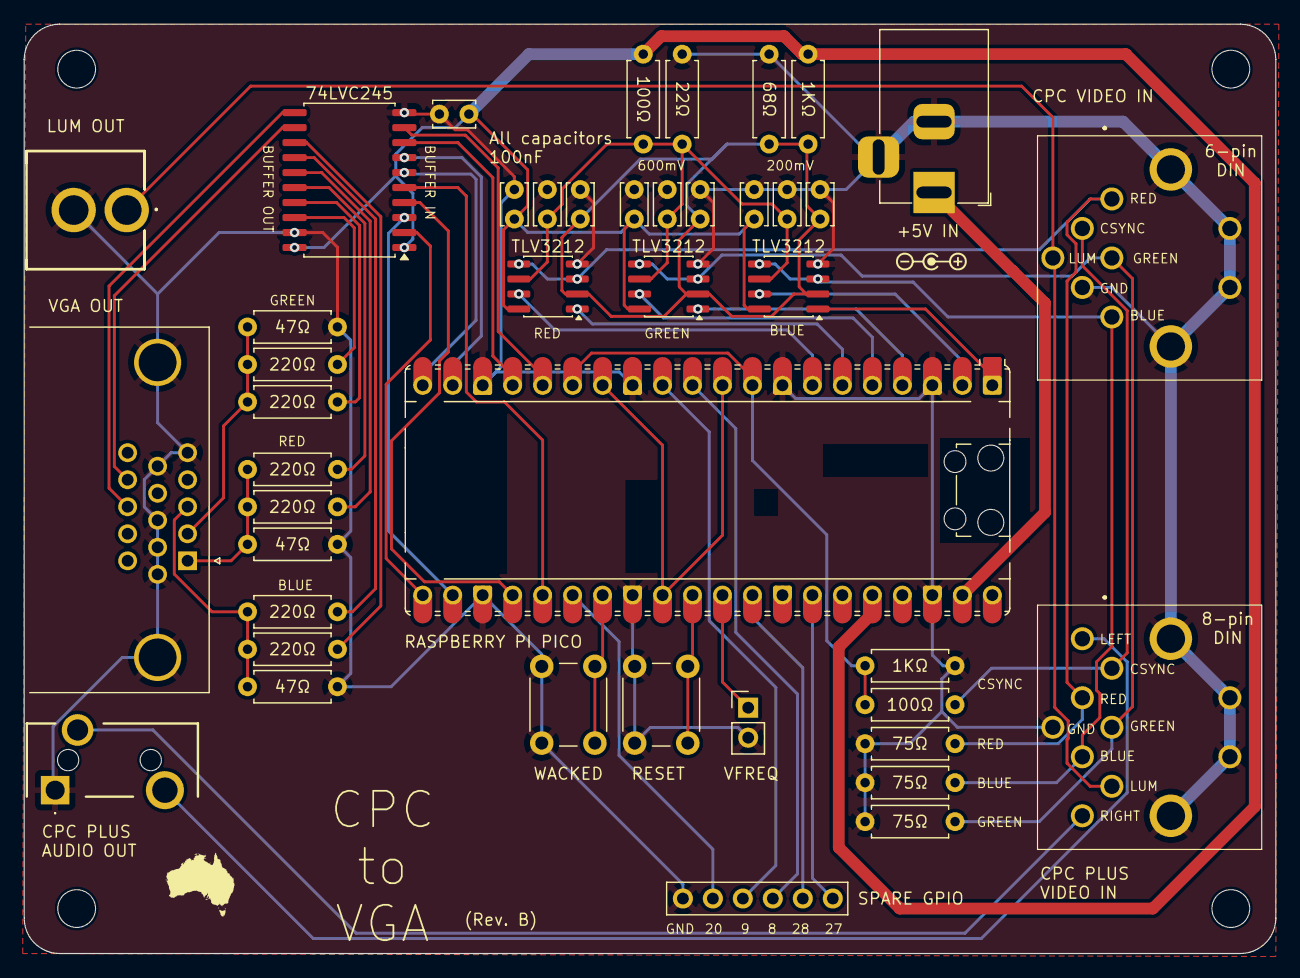
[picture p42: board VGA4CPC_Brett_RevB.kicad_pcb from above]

Board: 2 copper layers, 106.0 x 78.7 mm, 47 parts (0 on the bottom side), 47 nets.

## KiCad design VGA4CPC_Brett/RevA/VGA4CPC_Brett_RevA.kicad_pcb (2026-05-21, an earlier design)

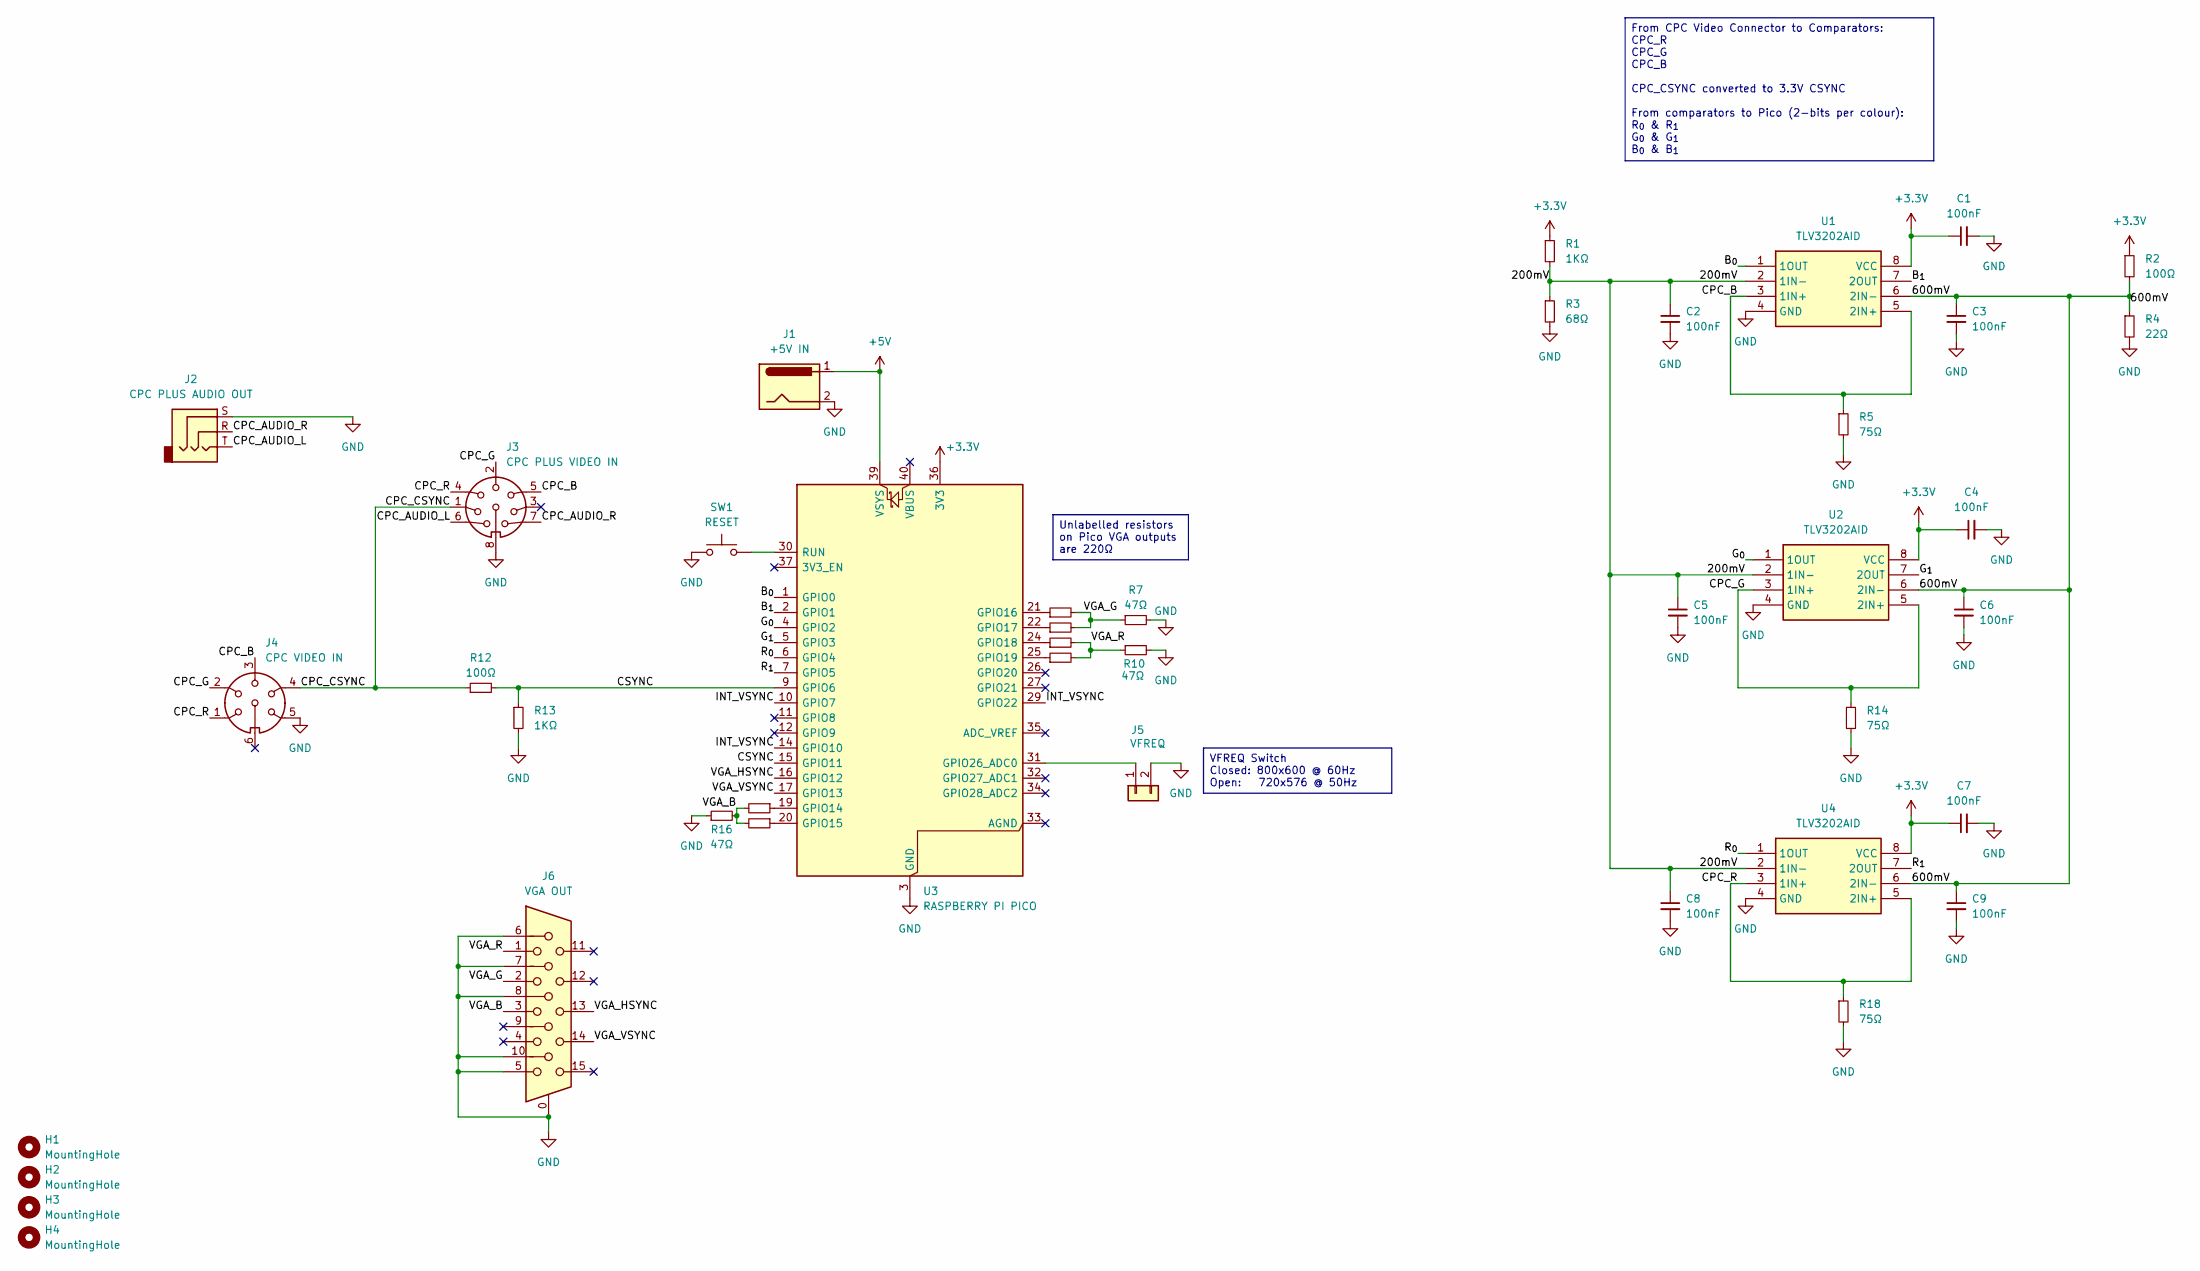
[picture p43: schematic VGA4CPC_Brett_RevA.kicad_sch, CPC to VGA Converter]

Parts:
C1, C2, C3, C4, C5, C6, C7, C8, C9: 100nF; C_Disc_D3.4mm_W2.1mm_P2.50mm
H1, H2, H3, H4: MountingHole; MountingHole_3.2mm_M3
J1: +5V IN; BarrelJack_Horizontal
J2: CPC PLUS AUDIO OUT; SJ335083ATR
J3: CPC PLUS VIDEO IN; SDF80J
J4: CPC VIDEO IN; SDF80J
J5: VFREQ; PinHeader_1x02_P2.54mm_Vertical
J6: VGA OUT; DSUB-15-HD_Socket_Horizontal_P2.29x2.54mm_EdgePinOffset8.35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
R1, R13: 1KΩ; R_Axial_DIN0207_L6.3mm_D2.5mm_P7.62mm_Horizontal
R2, R12: 100Ω; R_Axial_DIN0207_L6.3mm_D2.5mm_P7.62mm_Horizontal
R3: 68Ω; R_Axial_DIN0207_L6.3mm_D2.5mm_P7.62mm_Horizontal
R4: 22Ω; R_Axial_DIN0207_L6.3mm_D2.5mm_P7.62mm_Horizontal
R5, R14, R18: 75Ω; R_Axial_DIN0207_L6.3mm_D2.5mm_P7.62mm_Horizontal
R6, R8, R9, R11, R15, R17: 220Ω; R_Axial_DIN0207_L6.3mm_D2.5mm_P7.62mm_Horizontal
R7, R10, R16: 47Ω; R_Axial_DIN0207_L6.3mm_D2.5mm_P7.62mm_Horizontal
SW1: RESET; SW_PUSH_6mm
U1, U2, U4: TLV3202AID; SOIC-8_3.9x4.9mm_P1.27mm; Mouser Part Number 595-TLV3202AID
U3: RASPBERRY PI PICO; RaspberryPi_Pico_Common_Unspecified

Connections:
+3.3V: C1.1, C4.1, C7.1, R1.1, R2.1, U1.8 (VCC), U2.8 (VCC), U3.36 (3V3), U4.8 (VCC)
+5V: J1.1, U3.39 (VSYS)
/200mV: C2.1, C5.1, C8.1, R1.2, R3.1, U1.2 (1IN-), U2.2 (1IN-), U4.2 (1IN-)
/600mV: C3.1, C6.1, C9.1, R2.2, R4.1, U1.6 (2IN-), U2.6 (2IN-), U4.6 (2IN-)
/B_{0}: U1.1 (1OUT), U3.1 (GPIO0)
/B_{1}: U1.7 (2OUT), U3.2 (GPIO1)
/CPC_AUDIO_L: J2.T, J3.6
/CPC_AUDIO_R: J2.R, J3.7
/CPC_B: J3.5, J4.3, R5.1, U1.3 (1IN+), U1.5 (2IN+)
/CPC_CSYNC: J3.1, J4.4, R12.1
/CPC_G: J3.2, J4.2, R14.1, U2.3 (1IN+), U2.5 (2IN+)
/CPC_R: J3.4, J4.1, R18.1, U4.3 (1IN+), U4.5 (2IN+)
/CSYNC: R12.2, R13.1, U3.9 (GPIO6), U3.15 (GPIO11)
/G_{0}: U2.1 (1OUT), U3.4 (GPIO2)
/G_{1}: U2.7 (2OUT), U3.5 (GPIO3)
/INT_VSYNC: U3.10 (GPIO7), U3.14 (GPIO10), U3.29 (GPIO22)
/R_{0}: U3.6 (GPIO4), U4.1 (1OUT)
/R_{1}: U3.7 (GPIO5), U4.7 (2OUT)
/VGA_B: J6.3, R15.2, R16.2, R17.2
/VGA_G: J6.2, R6.2, R7.1, R8.2
/VGA_HSYNC: J6.13, U3.16 (GPIO12)
/VGA_R: J6.1, R9.2, R10.1, R11.2
/VGA_VSYNC: J6.14, U3.17 (GPIO13)
GND: C1.2, C2.2, C3.2, C4.2, C5.2, C6.2, C7.2, C8.2, C9.2, J1.2, J2.S, J3.8, J4.5, J5.2, J6.0, J6.5, J6.6, J6.7, J6.8, J6.10, R3.2, R4.2, R5.2, R7.2, R10.2, R13.2, R14.2, R16.1, R18.2, SW1.1, U1.4 (GND), U2.4 (GND), U3.3 (GND), U3.8 (GND), U3.13 (GND), U3.18 (GND), U3.23 (GND), U3.28 (GND), U3.38 (GND), U4.4 (GND)
unnamed: J5.1, U3.31 (GPIO26_ADC0)
unnamed: R15.1, U3.19 (GPIO14)
unnamed: R17.1, U3.20 (GPIO15)
unnamed: R6.1, U3.21 (GPIO16)
unnamed: R8.1, U3.22 (GPIO17)
unnamed: R9.1, U3.24 (GPIO18)
unnamed: R11.1, U3.25 (GPIO19)
unnamed: SW1.2, U3.30 (RUN)

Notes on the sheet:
From CPC Video Connector to Comparators: CPC_R CPC_G CPC_B CPC_CSYNC converted to 3.3V CSYNC From comparators to Pico (2-bits per colour): R_{0} & R_{1} G_{0} & G_{1} B_{0} & B_{1}
Unlabelled resistors on Pico VGA outputs are 220Ω
VFREQ Switch Closed: 800x600 @ 60Hz Open: 720x576 @ 50Hz

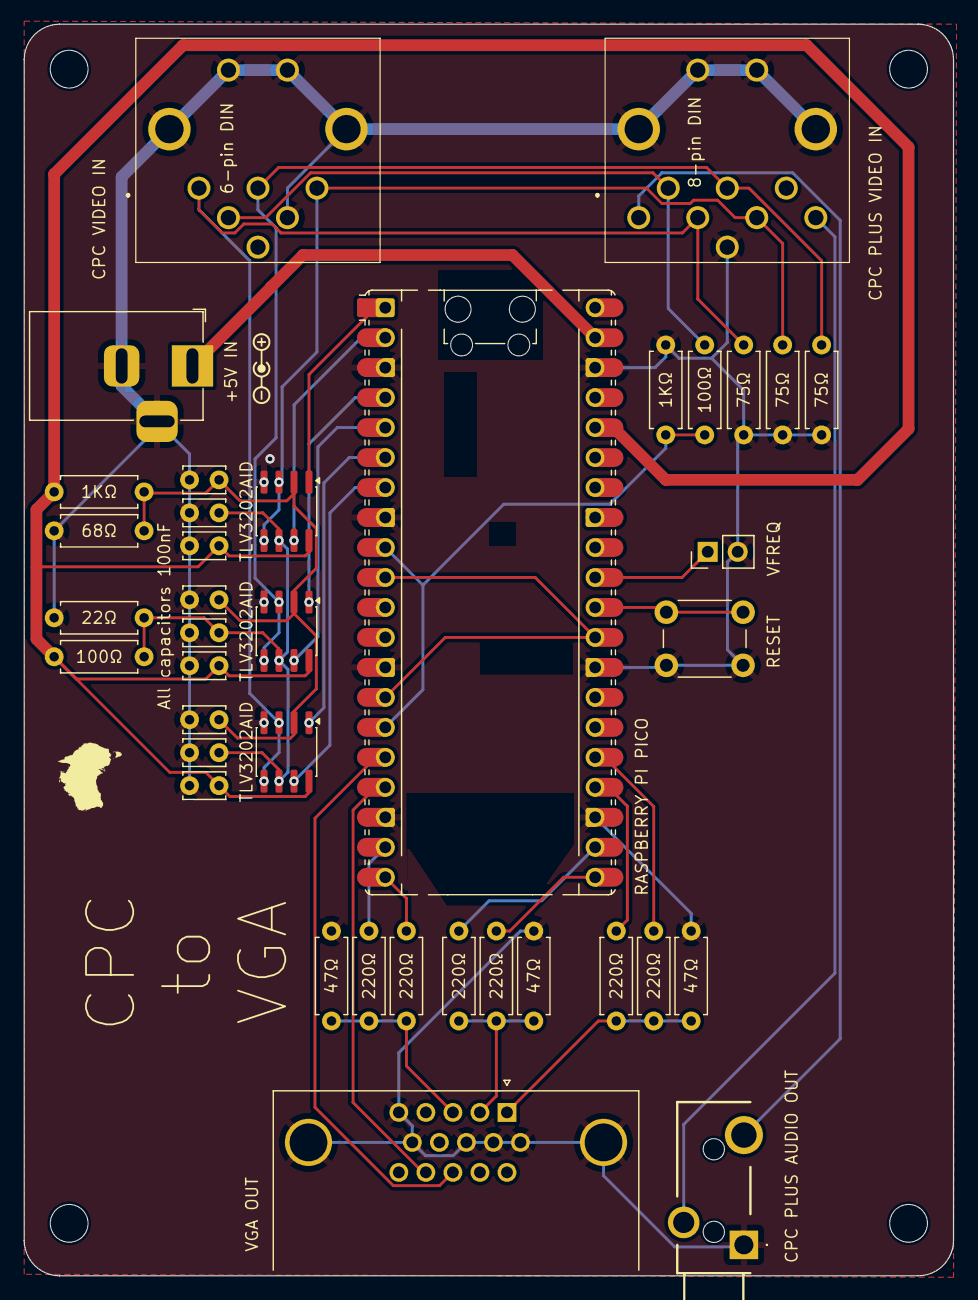
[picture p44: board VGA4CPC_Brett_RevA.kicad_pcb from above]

Board: 2 copper layers, 78.7 x 106.0 mm, 42 parts (0 on the bottom side), 32 nets.

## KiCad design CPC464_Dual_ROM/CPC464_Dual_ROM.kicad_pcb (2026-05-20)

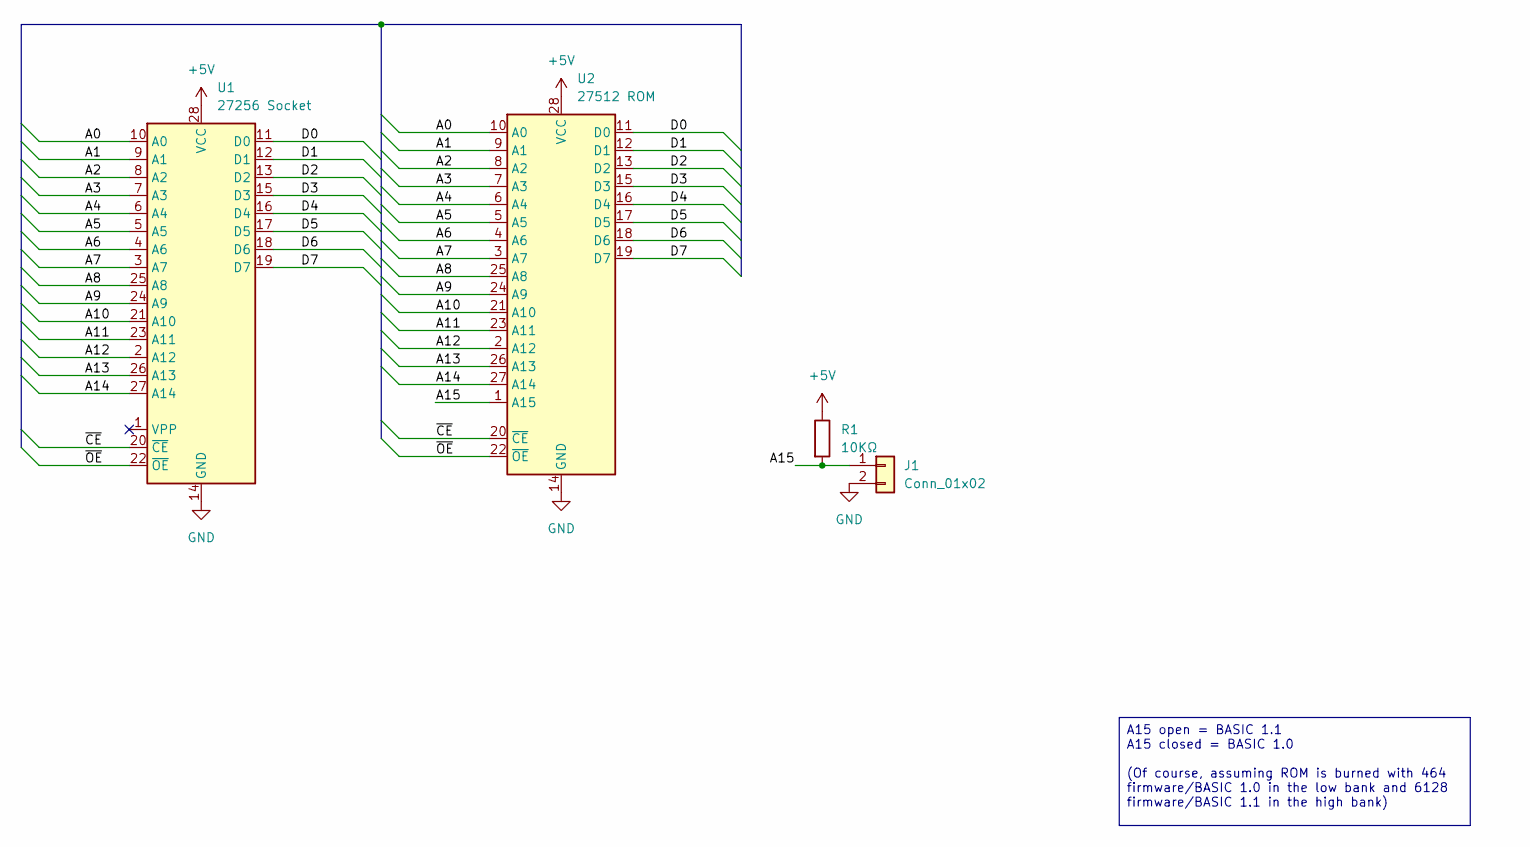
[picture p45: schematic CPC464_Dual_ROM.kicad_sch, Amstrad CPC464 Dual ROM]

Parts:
J1: Conn_01x02; PinHeader_1x02_P2.54mm_Vertical
R1: 10KΩ; R_Axial_DIN0207_L6.3mm_D2.5mm_P7.62mm_Horizontal
U1: 27256 Socket; DIP-28_W15.24mm
U2: 27512 ROM; DIP-28_W15.24mm_Socket

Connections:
+5V: R1.1, U1.28 (VCC), U2.28 (VCC)
/A0: U1.10 (A0), U2.10 (A0)
/A1: U1.9 (A1), U2.9 (A1)
/A2: U1.8 (A2), U2.8 (A2)
/A3: U1.7 (A3), U2.7 (A3)
/A4: U1.6 (A4), U2.6 (A4)
/A5: U1.5 (A5), U2.5 (A5)
/A6: U1.4 (A6), U2.4 (A6)
/A7: U1.3 (A7), U2.3 (A7)
/A8: U1.25 (A8), U2.25 (A8)
/A9: U1.24 (A9), U2.24 (A9)
/A10: U1.21 (A10), U2.21 (A10)
/A11: U1.23 (A11), U2.23 (A11)
/A12: U1.2 (A12), U2.2 (A12)
/A13: U1.26 (A13), U2.26 (A13)
/A14: U1.27 (A14), U2.27 (A14)
/A15: J1.1, R1.2, U2.1 (A15)
/D0: U1.11 (D0), U2.11 (D0)
/D1: U1.12 (D1), U2.12 (D1)
/D2: U1.13 (D2), U2.13 (D2)
/D3: U1.15 (D3), U2.15 (D3)
/D4: U1.16 (D4), U2.16 (D4)
/D5: U1.17 (D5), U2.17 (D5)
/D6: U1.18 (D6), U2.18 (D6)
/D7: U1.19 (D7), U2.19 (D7)
/~CE: U1.20 (~CE), U2.20 (~CE)
/~OE: U1.22 (~OE), U2.22 (~OE)
GND: J1.2, U1.14 (GND), U2.14 (GND)

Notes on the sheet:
A15 open = BASIC 1.1 A15 closed = BASIC 1.0 (Of course, assuming ROM is burned with 464 firmware/BASIC 1.0 in the low bank and 6128 firmware/BASIC 1.1 in the high bank)


Board: 2 copper layers, 40.3 x 21.7 mm, 4 parts (0 on the bottom side), 28 nets.

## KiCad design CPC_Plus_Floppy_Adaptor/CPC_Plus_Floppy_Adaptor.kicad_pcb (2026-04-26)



Board: 2 copper layers, 70.1 x 30.2 mm, 3 parts (2 on the bottom side), 15 nets.

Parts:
J1: 111-036-113L001
J2: Standard Floppy; PinHeader_2x17_P2.54mm_Vertical
J3: CPC Floppy; PinHeader_2x13_P2.54mm_Vertical

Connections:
/~DIR: J1.17, J2.18, J3.10
/~DRVSA: J1.13, J2.14
/~DRVSB: J1.11, J2.12, J3.4
/~INDEX: J1.7, J2.8, J3.2
/~MOTEA: J1.9, J2.10
/~MOTEB: J1.15, J2.16, J3.8
/~RDATA: J1.29, J2.30, J3.22
/~RDY: J1.33, J2.34, J3.26
/~SIDE1: J1.31, J2.32, J3.24
/~STEP: J1.19, J2.20, J3.12
/~TRK00: J1.25, J2.26, J3.18
/~WDATA: J1.21, J2.22, J3.14
/~WGATE: J1.23, J2.24, J3.16
/~WPT: J1.27, J2.28, J3.20
GND: J1.2, J1.4, J1.6, J1.8, J1.10, J1.12, J1.14, J1.16, J1.20, J1.22, J1.24, J1.26, J1.28, J1.30, J1.32, J1.34, J2.1, J2.3, J2.5, J2.7, J2.9, J2.11, J2.13, J2.15, J2.17, J2.19, J2.21, J2.23, J2.25, J2.27, J2.29, J2.31, J2.33, J3.1, J3.3, J3.5, J3.7, J3.9, J3.11, J3.13, J3.15, J3.17, J3.19, J3.21, J3.23, J3.25

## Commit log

2025-07-24 Started CPC6128 keyboard design
    [Amstrad_CPC6128_Keyboard.kicad_pcb, Amstrad_CPC6128_Keyboard.kicad_sch, amstrad-cpc6128_plate.dxf]
2025-07-24 CPC6128 keyboard updates
    [Amstrad_CPC6128_Keyboard.kicad_pcb, Amstrad_CPC6128_Keyboard.kicad_sch, amstrad-cpc6128_plate.dxf]
2025-07-30 Reorganise CPC projects
    [Amstrad_CPC6128_Keyboard.kicad_pcb, Amstrad_CPC6128_Keyboard.kicad_sch, Project_02_Picture_Digitiser.kicad_pcb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]
2025-07-30 Finalising 12mm tactile design
    [Amstrad_CPC6128_Keyboard.kicad_pcb, Amstrad_CPC6128_Keyboard.kicad_sch]
2025-07-30 Consolidating Amstrad CPC projects
    [CPC_PICOROM_PLUS.kicad_pcb, CPC_PICOROM_PLUS.kicad_sch, DEFAULT.CFG]
2025-07-31 Finalised Rev. A of tactile keyboard design
    [Amstrad_CPC6128_Keyboard.kicad_pcb, Amstrad_CPC6128_Keyboard.kicad_sch]
2025-08-01 Added 6mm tactile design
    [Amstrad_Tactile-12mm_Keyboard.kicad_pcb, Amstrad_Tactile-12mm_Keyboard.kicad_sch, Amstrad_Tactile-6mm_Keyboard.kicad_pcb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]
2026-05-20 Reorient PCB text
    [CPC464_Dual_ROM.kicad_pcb, CPC464_Dual_ROM.kicad_pcb_bom.csv, CPC464_Dual_ROM.kicad_pcb_positions.csv]
2026-05-21 Create RevA version
    [VGA4CPC_Brett.kicad_pcb, VGA4CPC_Brett.kicad_pcb_bom.csv, VGA4CPC_Brett.kicad_pcb_positions.csv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]
2026-05-21 Create Rev. B version
    [1] Added buffer on Pico VGA output signals as suggested by WacKEDmaN
    [2] Added RCA jack for luminosity (B&W) signal pass-through
    [VGA4CPC_Brett.kicad_pcb, VGA4CPC_Brett.kicad_pcb_bom.csv, VGA4CPC_Brett.kicad_pcb_positions.csv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]
2026-05-21 Added BOM to schematic
    [VGA4CPC_Brett.kicad_pcb, VGA4CPC_Brett.kicad_pcb_bom.csv, VGA4CPC_Brett.kicad_pcb_positions.csv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]
2026-05-22 Silkscreen updates
    [VGA4CPC_Brett.kicad_pcb, VGA4CPC_Brett.kicad_pcb_bom.csv, VGA4CPC_Brett.kicad_pcb_positions.csv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]
2026-05-22 Spare GPIO ports routed
    [1] Additional WACKED button (GPIO 21) for "future use"
    [2] Spare GPIO 8/9/20 brought out to pin header for "future use"
    [VGA4CPC_Brett.kicad_pcb, VGA4CPC_Brett.kicad_pcb_bom.csv, VGA4CPC_Brett.kicad_pcb_positions.csv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]
2026-05-22 Broke out extra spare GPIO ports
    [VGA4CPC_Brett.kicad_pcb, VGA4CPC_Brett.kicad_pcb_bom.csv, VGA4CPC_Brett.kicad_pcb_positions.csv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]
2026-05-24 Reorganise RevA & RevB
    [VGA4CPC_Brett_RevA.kicad_pcb, VGA4CPC_Brett_RevA.kicad_sch, VGA4CPC_Brett_RevB.kicad_pcb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]
2026-05-24 CPC-only RevC small PCB
    Under 100x100mm so US$5 for 10 PCBs
    [VGA4CPC_Brett_RevC.kicad_pcb, VGA4CPC_Brett_RevC.kicad_pcb_bom.csv, VGA4CPC_Brett_RevC.kicad_pcb_positions.csv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]
2026-05-24 Added +3.3V on spare GPIO header
    [VGA4CPC_Brett_RevC.kicad_pcb, VGA4CPC_Brett_RevC.kicad_pcb_bom.csv, VGA4CPC_Brett_RevC.kicad_pcb_positions.csv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]
2026-05-24 Corrected RevC in schematic sheet
    [VGA4CPC_Brett_RevC.kicad_sch]
2026-05-24 Added CPC PLUS connectors
    [1] 8-pin DIN for CPC PLUS
    [2] pass-through of CPC PLUS audio
    [VGA4CPC_Brett_RevD.kicad_pcb, VGA4CPC_Brett_RevD.kicad_pcb_bom.csv, VGA4CPC_Brett_RevD.kicad_pcb_positions.csv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]
2026-05-24 Initial commit
    Nothing fancy, simply converts CPC DIN connector to VGA for easier connecting to something else, no fancy signal conditioning
    Or, simply use the B&W LUM output
    Also exposes the CPC PLUS stereo audio
    [CPC_DIN-to-VGA.kicad_pcb, CPC_DIN-to-VGA.kicad_pcb_bom.csv, CPC_DIN-to-VGA.kicad_pcb_positions.csv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]
2026-05-24 Type correction
    [VGA4CPC_Brett_RevD.kicad_sch]
2026-05-30 TLV3212 -> TLV3232
    Had to change footprint from SOIC-8 to SSOP-8
    [VGA4CPC_Brett_RevE.kicad_pcb, VGA4CPC_Brett_RevE.kicad_sch]
2026-05-30 Updated PCB text to "15KHz VGA OUT"
    [CPC_DIN-to-VGA.kicad_pcb, CPC_DIN-to-VGA.kicad_pcb_bom.csv, CPC_DIN-to-VGA.kicad_pcb_positions.csv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]
2026-05-30 Added "15KHz VGA" note to PCB
    [CPC_DIN-to-VGA.kicad_pcb_bom.csv, CPC_DIN-to-VGA.kicad_pcb_positions.csv]
2026-05-30 New comparator daughterboard for Rev. F design
    Moved comparators to separate daughterboard to simplify main VGA board design
    [Comparator_Board.kicad_pcb, Comparator_Board.kicad_pcb_bom.csv, Comparator_Board.kicad_pcb_positions.csv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]
2026-05-30 Widened the PCB
    Made more room on the PCB in case we want to change it and not have to change the footprint on the main board.
    [Comparator_Board.kicad_pcb, Comparator_Board.kicad_pcb_bom.csv, Comparator_Board.kicad_pcb_positions.csv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]
2026-05-31 Rev. F initial commit
    Moved comparator to own daughterboard
    Switched from 3.3V to 5V logic (requires Pico 2 for sure)
    Switched 74LVC245 (SMD) to 74HCT245 (through-hole)
    [VGA4CPC_Brett.kicad_pcb_bom.csv, VGA4CPC_Brett.kicad_pcb_positions.csv, VGA4CPC_Brett_RevC.kicad_pcb_bom.csv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]
2026-06-26 Error for semicolon instead of colon
    For example:
    PRINT;PRINT"xxxx" (error)
    PRINT:PRINT"xxxx" (ok)
2026-07-09 Finalised voltage divider resistor values
    [Comparator_Board.kicad_pcb, Comparator_Board.kicad_sch]
